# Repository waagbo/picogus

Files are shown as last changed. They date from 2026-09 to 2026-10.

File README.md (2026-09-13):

# PicoGUS

PicoGUS Logo



ISA sound card and CD-ROM drive emulation on the Raspberry Pi Pico's RP2040 microcontroller. PicoGUS can emulate:

* [Gravis Ultrasound (GUS)](https://en.wikipedia.org/wiki/Gravis_Ultrasound) - the primary focus of PicoGUS, hence the name
* [Sound Blaster 16](https://en.wikipedia.org/wiki/Sound_Blaster_16) (OPL3) / [Sound Blaster Pro 2](https://en.wikipedia.org/wiki/Sound_Blaster#Sound_Blaster_Pro_2,_CT1600) (OPL3) / [AdLib](https://en.wikipedia.org/wiki/Ad_Lib,_Inc.) (OPL2)
* [MPU-401 (with intelligent mode)](https://en.wikipedia.org/wiki/MPU-401) - outputs MIDI data on 3.5mm MIDI TRS connector
* [Tandy 3-voice](http://www.vgmpf.com/Wiki/index.php?title=Tandy_3_Voice)
* [CMS/Game Blaster](http://nerdlypleasures.blogspot.com/2012/10/all-you-ever-wanted-to-know-about.html)
* [Game port joystick](https://en.wikipedia.org/wiki/Game_port)
* [Panasonic/MKE CD-ROM](https://en.wikipedia.org/wiki/Panasonic_CD_interface)
* USB drive access from DOS: the drive plugged into the PicoGUS mapped to a DOS drive letter with `PGUSDFS.EXE` (see [pgusdfs/README.md](pgusdfs/README.md))

Current status: perpetual beta! See the [main wiki page](https://github.com/polpo/picogus/wiki) for current status and the [compatibility list](https://github.com/polpo/picogus/wiki/Compatibility-list) for support status of various DOS programs and other system compatibility notes. This project has a heavy demoscene focus due to the GUS's history so that's what I've concentrated on, but GUS support in games is very good to excellent.

Want to buy a PicoGUS? Fully assembled PicoGUS 2.0 sound cards are available from these sources, all of whom ship worldwide:

* [Joe's Computer Museum Shop](https://jcm-1.com/product/picogus-v2/) - in US 🇺🇸
* [Serdashop](https://www.serdashop.com/PicoGUS) - in EU 🇪🇺
* [Flamelily IT](https://shop.flamelily.co.uk/picogus) - in UK 🇬🇧

Want to make your own PicoGUS? See the [build guide](https://github.com/polpo/picogus/wiki/Building-your-PicoGUS). Note that the more DIY friendly v1.1.1 hardware has some documented issues with reset – a forthcoming v1.2 revision will fix these issues. **Important caveat**: due to the specs of the Pico, assumptions made by programs written to use the GUS, the imprecise nature of emulation, and the varying specs of retro DOS PC hardware, some things will likely never be perfect. **This is still a work in progress.**

Have a PicoGUS and want to use it? See the [configuring and using your PicoGUS guide](https://github.com/polpo/picogus/wiki/Configuring-and-using-your-PicoGUS).

Want to support PicoGUS? I have a limited number of machines to test PicoGUS in and donating either money or motherboards would be greatly appreciated and help increase the compatibility of PicoGUS.

You can donate via [PayPal](https://paypal.me/ianpolpo) or Ko-Fi: 

PicoGUS 2.0 PCB

PicoGUS v1.1 beta PCB

See/hear PicoGUS in action on YouTube:

Videos by others:

[](https://www.youtube.com/watch?v=08IPnmvuatw)
[](https://youtu.be/bBYUTwKRyNk)
[](https://youtu.be/oEHVB0FITqU)
[](https://youtu.be/aeejxbaAQ4g)
[](https://youtu.be/okSBZJwqVb8)

My videos:

[September 2022 update](https://youtu.be/h4iWSnTc9Ag)
[October 2022 update](https://youtu.be/CkJvkJVRscQ)
[December 2022 update](https://youtu.be/F5Zk_hHHkTg)
[January 2023 update](https://youtu.be/sOHTagrWcIE)
[March 2023 update](https://youtu.be/2LBXzy4Fus0)

## Open Source Credits

* [Raspberry Pi Pico C/C++ SDK](https://github.com/raspberrypi/pico-sdk)
* `pico_audio_i2s` from [pico-extras](https://github.com/raspberrypi/pico-extras)
* `stdio_async_uart` from [PicoCart64](https://github.com/kbeckmann/PicoCart64)
* `gus-x.cpp` adapted from [DOSBox-X](https://github.com/joncampbell123/dosbox-x)
* OPL/AdLib emulation from [rp2040-doom](https://github.com/kilograham/rp2040-doom) (based on [emu8950](https://github.com/digital-sound-antiques/emu8950))
* MPU-401 emulation adapted from [HardMPU](https://github.com/ab0tj/HardMPU) and [DOSBox-X](https://github.com/joncampbell123/dosbox-x)
* Tandy 3-voice emulation based on code contributed by [Aaron Giles](https://aarongiles.com/), adapted from [DREAMM](https://aarongiles.com/dreamm/) 
* CMS emulation based on code contributed by [Aaron Giles](https://aarongiles.com/), adapted from [DREAMM](https://aarongiles.com/dreamm/)
* USB support uses [TinyUSB](https://github.com/hathach/tinyusb) and [tusb_xinput](https://github.com/Ryzee119/tusb_xinput) with USB mass storage improvements by rppicomidi and wbcbz7.
* FAT drive support by [FatFS](https://elm-chan.org/fsw/ff/)

## License

The hardware portions of this repository (hw/ directory) are licensed under the CERN OHL version 2, permissive.

The software portions of this repository (sw/, pgusinit/ directories) as a collection are licensed under the GNU GPL version 2. Some files are individually dual-licensed under BSD or MIT licenses – see the license in the file headers for details.

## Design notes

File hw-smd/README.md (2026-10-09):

# PicoGUS SMD v1.3.0 – based on PicoGUS v1.2

Board revision **v1.3.0 (SMD)**: the PicoGUS **v1.2** SMD card with the additions made for the
through-hole board in [`hw-tht/`](../hw-tht/README.md):

* **Waveblaster (wavetable) daughterboard header** J9, with MIDI and /RESET drive
* **Analogue WT volume** (RV1) and an **NE5532 op-amp mixer** that sums the PCM audio (unity gain) and the WT
  audio (up to +6 dB, set by RV1)
* **Cleaner audio supplies:** a ferrite-bead-filtered DAC AVDD and RC-filtered ±12 V for the op-amp
* **Same layout as the THT board:** taller card, Pico rotated along the top edge, DAC turned so its
  outputs face the mixer, and one KiCad group per circuit block

> **Status: prototype design, not yet fabricated or tested.**
> The schematic passes ERC (0 errors). The board was autorouted and checked with DRC in KiCad 10
> (0 errors, 0 unconnected), but nobody has built one yet. `hw/` still holds the released v1.2.

| File | What |
|---|---|
| `PicoGUS-SMD.kicad_pro/.kicad_sch/.kicad_pcb` | KiCad **10** project (the root sheet is the v1.2 logic) |
| `audio.kicad_sch` | PCM510x DAC sheet (v1.2 circuit, AVDD now filtered) |
| `wavetable.kicad_sch` | New: Waveblaster header, WT control (U12), WT volume, op-amp mixer, line-out jack |
| `PicoGUS-SMD-schematic.pdf` | Schematic PDF |
| `BOM-SMD.csv` | BOM with a **DigiKey link** for every line, stock and NOK price (checked 2026-09-29) |
| `BOM-SMD-digikey-upload.csv` | DigiKey cart/BOM upload: quantity, DigiKey part number, MPN, and the reference designators as Customer Reference (printed on each bag) |
| `BOM-SMD-digikey-upload-10x.csv` | The same for **10 boards**: every quantity ×10, except the 1x40 header strip (11 strips: one per board for the Pico, one more for all the 1x2 jumpers). DigiKey applies its 10-piece price breaks |

## What changed compared to v1.2

The v1.2 logic is unchanged: U2 74LVC244, U3/U4 CB3T3257, U5 74AHC14, U6 74LVC00,
U7 74LVC1G00, U8 PSRAM, U9 PCM510x and U10 74LVC2G06, with the same footprints.

* **Waveblaster header J9** (2x13, 2.54 mm) along the top edge, with 5 V, ±12 V and decoupling at the
  header (C24–C27). The daughterboard's outputs go through C22/C23 to RV1.
* **U12 (74LVC2G06, new)** drives the daughterboard's /RESET (inverted ISA RESET) and MIDI (the same
  UART data as the MIDI-out jack). Its outputs are open drain with 10 k pull-ups to +3.3 V (R9/R16), so
  3.3 V daughterboards are safe. U12B takes its input from the same U5A output that drives U10B (net `~MIDI_DRV`).
* **Mixer U11 (NE5532, SOIC-8)** is an inverting summer. PCM (after the v1.2 470 Ω / 2.2 nF filter) goes
  through 20 kΩ (R10/R11) and WT (after RV1) through 10 kΩ (R12/R13) into the virtual ground, with
  20 kΩ ∥ 47 pF feedback (R19/R20, C30/C31) and a 100 Ω output resistor.
  * PCM has (almost) unity gain (20k/20.47k, −0.2 dB), so the PCM level at the jack is the same as on v1.2
    (2.1 Vrms full scale).
  * WT has a gain of 2 (+6 dB) at RV1 max. Waveblaster daughterboards put out only about 1–1.2 Vrms full
    scale (a DreamBlaster X2 uses an AKM AK4388 DAC, 1.13 Vrms), so at unity gain MIDI was 5–6 dB quieter
    than PCM. RV1 trims it down. The daughterboard sees about 4.8 kΩ at RV1 max (RV1 ∥ R12 ∥ R14).
  * **Changed 2026-10-09** (BOM only, no board change): R10, R11, R19, R20 were 10 kΩ and C30/C31 were
    100 pF (about unity gain for both sources; PCM was −0.4 dB). 47 pF with the 20 kΩ feedback puts the
    corner at ~170 kHz (10 kΩ ∥ 100 pF was ~160 kHz).
* **Audio quality:**
  * DAC AVDD (U9 pin 8) sits behind ferrite bead FB3, with C13 (0.1 µF) and C15 (10 µF) at the pin.
    DVDD and CPVDD stay on the Pico's 3.3 V.
  * Op-amp ±12 V comes through R23/R24 (10 Ω) and C32/C33 (47 µF), an RC low-pass at ~340 Hz, with
    C28/C29 (0.1 µF) at the pins.
  * C22/C23 are **bipolar** electrolytics, because the DC level across them depends on the daughterboard.
  * The signal-path capacitors (C19/C20, C30/C31) are **C0G**. The signal-path resistors (R7/R8,
    R10–R13, R19/R20) are **0.1 % thin film**, which has lower noise and distortion than thick film and
    keeps left and right matched.
* **Removed:** J2 (the ISA debug header, never fitted).
* **Pico VBUS** gets a PWR_FLAG, which clears the one ERC error that v1.2 also had.
* **1.6 mm FR4.** The v1.2 project file said 0.57 mm, which is too thin for an ISA edge connector.

### DAC option: on-board PCM5100A **or** a GY-PCM5102 module (J10)

As on the THT board, the PCM output can come from **either** the on-board DAC **or** a GY-PCM5102
module soldered almost flat over the DAC area. Fit one of the two, **never both**.

| Build | Fit | Leave out |
|---|---|---|
| On-board DAC (default, JLCPCB assembly) | U9, C12–C20, FB3, R7, R8 | J10 (the module) |
| GY-PCM5102 module | the module, soldered almost flat in J10 | **U9, C12–C20, FB3, R7, R8** (mark them DNP) |

* The parts to leave out are exactly the ones inside the module's **dashed J10 outline**, headed
  "DAC -OR- GY-PCM5102". That includes the DAC's output filter (R7/R8, C19/C20): the module has the same
  470 Ω / 2.2 nF filter, so its outputs join AUDIO_L/AUDIO_R straight into the mixer.
* Solder the module directly on its 2.54 mm male pins (6-pin I2S header + a 4-pin piece on the AGND ROUT
  AGND LROUT end of its 9-pin row), no sockets, so it stays well under a Waveblaster daughterboard. Its
  solder jumpers: **H1=L, H2=L, H3=H, H4=L**; it gets +5 V and SCK is grounded on the card.

### Back silkscreen

The back carries the PicoGUS artwork (hw-common/art/picogus-artwork.svg: three game heroes over the
PicoGUS logo), 76 × 27 mm, with the dedication centred below it: *This version is dedicated to Mila and
Alisa, my two wonderful princesses, who fill my world with joy.* Both are mirrored on B.SilkS; any pad or
hole in the way is cut out 0.3 mm around it.

## Card dimensions (ISA 8-bit)

The card is **103.7 mm long (bracket to far edge) × 99.9 mm tall** (fingers to top edge). The IBM PC/XT
full-height limit is 4.2 in (106.7 mm), so the card is 6.8 mm under it; the AT limit is 4.8 in (121.9 mm).
The edge connector (62 contacts, 0.1 in pitch), its position and the bracket holes H1/H2 are copied
from v1.2. The existing v1.2 bracket fits, plus one extra hole for RV1 (see below). The tallest
parts are the pot RV1 and the pin headers. A Waveblaster daughterboard sits about 11 mm above the
card, well inside the 0.8 in (20.3 mm) slot pitch of an AT case, as on Sound Blaster cards with a
Waveblaster header. The next card along must not have tall parts on its solder side.

## Ordering

`BOM-SMD.csv` has a DigiKey part number, a clickable digikey.no link, stock and price for every
line. Every line was in stock at DigiKey on 2026-09-29.

| DigiKey, parts only (no PCB, no shipping) | 1 board | per board, 10-board order |
|---|---|---|
| NOK excl. MVA | ~374 kr | ~286 kr |
| NOK incl. 25 % MVA | ~468 kr | ~357 kr |
| USD | ~$39 | ~$30 |

The NOK prices are DigiKey's price breaks converted by findchips.com, so digikey.no may differ by a
few percent. The biggest items are the Pico (44 kr), U3/U4 (40 kr), the PCM5100A (25 kr) and RV1 (24 kr).

Several v1.2 BOM lines are **out of stock at DigiKey today**, so they are replaced with equivalent parts:

| Part | v1.2 BOM | v1.3.0 BOM |
|---|---|---|
| 0.1 µF | Samsung CL21B104KCFNNNE | Samsung CL21B104KBCNNNC |
| 1 µF | Samsung CL21B105KBFNNNE | TDK C2012X7R1H105K125AB |
| 2.2 µF | Samsung CL21A225KBQNNNE | TDK C2012X7R1H225K125AC |
| 10 µF (C15) | Samsung CL21A106KAYNNNE, 0805 | Samsung CL31A106KAHNNNE, **1206** (no 10 µF 0805 in stock) |
| 47 µF | Samsung CL31A476MPHNNNE | TDK C3216X5R1A476M160AB |
| U2 | Nexperia 74LVC244APW,118 | TI SN74LVC244APW |
| R1/R2/R5/R6 | Bourns CR0805 (low stock) | Yageo RC0805FR |

This BOM doesn't include LCSC/JLCPCB assembly data. The `hw/jlcpcb` files are for v1.2.

## JLCPCB files

```
hw-common/tools/jlcpcb.sh hw-smd/PicoGUS-SMD.kicad_pcb        # -> hw-smd/build/jlcpcb/
```

The script stops if DRC (including the schematic-parity check) finds errors. `FORCE=1` exports anyway. It writes:

* `PicoGUS-SMD-gerbers.zip`: upload this to jlcpcb.com. It holds the Gerbers (Protel extensions, no X2)
  and the Excellon drill files (PTH and NPTH separate, mm).
* `PicoGUS-SMD-bom-jlc.csv` and `PicoGUS-SMD-cpl-jlc.csv`: the BOM and placement files for JLCPCB assembly (SMD parts only).
  The LCSC column is empty for now (this BOM is DigiKey-only), so JLCPCB matches parts by MPN or you pick them in their BOM tool.
* `PicoGUS-SMD-drc.rpt`: the DRC report.

The **Hardware (JLCPCB files)** GitHub Action runs the same script on every push that touches the
boards. The files can be downloaded as build artifacts (`jlcpcb-tht`, `jlcpcb-smd`).

Order options: 2 layers, **1.6 mm**, and **Gold fingers: Yes** with the **45° finger chamfer** (the ISA
edge connector). ENIG is a good choice for the rest of the board. Check the rotations in JLCPCB's
placement preview before paying for assembly.

## Caveats

1. **Untested.** The board is built from the proven v1.2 circuit plus the THT board's additions, but
   it hasn't been fabricated. It was autorouted with Freerouting, so check the routing before ordering.
2. **Audio now needs −12 V.** The mixer runs from ISA ±12 V, so without −12 V there is no line
   output at all (not even PCM). Every AT/ATX PC power supply provides −12 V.
3. **C22/C23 footprint.** KiCad has no non-polar SMD electrolytic footprint, so the silkscreen shows
   a "+". The parts are bipolar, so either orientation is correct.
4. **RV1.** The BOM uses the Bourns PTD902-2020K-A103 (DigiKey 426, 24 kr). It has the same 2.5 mm
   pin grid and M7 bushing as the Alps RK097 the footprint was drawn for; test-fit one in the bracket
   before a large order. The Alps RK09712200HA (45 kr) and the switched RK0971221Z0X also fit, but
   have low stock.
5. **ISA bracket.** Drill one more hole (about 7 mm, for RV1's bushing) between the MIDI and line-out
   jack holes.
6. **Silkscreen.** Reference labels were placed automatically, and some sit on their default spot
   next to a neighbour. Tidy them before ordering.

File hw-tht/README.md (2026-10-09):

# PicoGUS THT (through-hole) v1.3.0 – based on PicoGUS v1.2

Board revision **v1.3.0**: a through-hole variant of the PicoGUS **v1.2** ISA card, with an added
**Waveblaster (wavetable) daughterboard header** and an **analogue volume
control** that mixes the wavetable output with the PicoGUS audio.

> **Status: prototype design, not yet fabricated or tested.**
> The schematic passes ERC and was netlist-compared against v1.2. The board was
> autorouted and checked with DRC in KiCad 10, but nobody has built one yet.
> Read the [caveats](#caveats) before ordering boards.

Files:

| File | What |
|---|---|
| `PicoGUS-THT.kicad_pro/.kicad_sch/.kicad_pcb` | KiCad **10** project (the root sheet is the v1.2 logic) |
| `audio.kicad_sch` | PCM510x DAC sheet (same circuit as v1.2, with THT passives) |
| `wavetable.kicad_sch` | New: Waveblaster header, WT control logic, WT volume, op-amp mixer, line-out jack |
| `PicoGUS-THT-schematic.pdf` | Schematic PDF |
| `BOM-THT.csv` | BOM with DigiKey **and** LCSC part numbers, plus a digikey.no link per line (stock checked 2026-09-28) |
| `BOM-THT-digikey-upload.csv` (+ `-optional`) | DigiKey cart/BOM upload: quantity, DigiKey part number, MPN, and the reference designators as Customer Reference (printed on each bag) |
| `BOM-THT-digikey-upload-10x.csv` (+ `-optional-10x`) | The same for **10 boards**: every quantity ×10, except the 1x40 header strip (11 strips: one per board for the Pico, one more for all the 1x2 jumpers). DigiKey applies its 10-piece price breaks |

The shared `PiGUS library` symbols and footprints are linked from `hw-common/`, like the other boards.
All other footprints come from KiCad's standard libraries.

## What changed compared to v1.2

### Through-hole parts only

| Part | v1.2 | THT board |
|---|---|---|
| Resistors | 0805 | 1/4 W axial, 10.16 mm hole pitch |
| Ceramic caps | 0805 / 1206 | radial MLCC / disc, **5.0 mm** lead pitch |
| Electrolytics | 1206 / SMD | 5 mm radial electrolytics |
| D1 | B5819W SOD-123 | 1N5819 DO-41 |
| U2 | 74LVC244 TSSOP-20 | **74AHC244 DIP-20** |
| U5 | 74AHC14 SOIC-14 | **74AHC14 DIP-14** |
| U6 | 74LVC00 SOIC-14 | **74AHC00 DIP-14** |
| U7 | 74LVC1G00 SOT-23-5 | **one gate of a 74AHC00 DIP-14**, 3 spare gates tied off |
| U10 | 74LVC2G06 SOT-23-6 (open drain, 3V3) | **74AHCT126 DIP-14 at +5 V**, used as a "pseudo open-drain" |
| FB1/FB2 | 0805 beads | axial ferrite beads (bead on leads), 12.7 mm hole pitch |

Only the parts that exist in SMD packages alone stay SMD. All of them have a pitch of 0.65 mm or more and can be hand-soldered:

* **U3, U4** SN74CB3T3257: FET bus-switch mux with 5 V→3.3 V clamping. It only comes in
  TSSOP-16/TVSOP. No DIP part does this job without redesigning the ISA bus interface (and the PIO timing).
* **U8** APS6404L PSRAM: SOIC-8.
* **U9** PCM5100A/PCM5101A/PCM5102A DAC: TSSOP-20.

The 3.3 V logic needs 5 V-tolerant inputs, so it is 74**AHC** in DIP (TI still makes these and DigiKey
stocks them). **LCSC has almost none of these DIPs in stock** (0–74 pcs on 2026-09-28): order the logic
ICs from DigiKey.

### U10: 74AHCT126 instead of 74LVC2G06

The open-drain 74LVC2G06 has no DIP equivalent that takes a 3.3 V input and has a 5 V
open-drain output. HC/LS open-drain parts either need 5 V input levels or float "high"
while the Pico boots, which would hang the ISA bus through IOCHRDY. The AHCT126 runs from +5 V and
accepts the 3.3 V signals (TTL thresholds). It is wired as a pseudo open-drain driver:
input **A is tied to GND**, and the signal that drove the old inverter input now drives **OE**. OE=1 pulls the line low;
OE=0 releases it. The polarity is the same as on v1.2, so **no firmware change** is needed.

* Gate A: IOCHRDY (as v1.2). **R18** (100 k pull-down on `~RI/OCHRDY`) keeps IOCHRDY released
  while +5 V is up but the Pico's 3.3 V rail isn't yet, or while the Pico is in reset.
* Gate B: MIDI-out current loop (as v1.2).
* Gate C: Waveblaster `/RESET`. Gate D: Waveblaster MIDI (see below).
* **Only use 74AHCT126 here** (SN74AHCT126N). A 74**HCT**126 has
  input clamp diodes to VCC: with the Pico powered from USB and the PC off, the Pico's
  outputs would back-power the ISA +5 V rail through it. A 74**HC**126 at 5 V doesn't recognise 3.3 V
  highs. An **AHC**126 would work electrically, but its 5 V thresholds leave no margin.

**R17** (10 k pull-up on `UART_TX`) holds the MIDI and Waveblaster MIDI lines idle while the Pico boots
(the RP2040 pads default to pull-down, which would otherwise send a MIDI "break").

### Waveblaster header (new)

`J9` is the standard 26-pin Waveblaster header (2x13 male, 2.54 mm; the daughterboard has the
female socket). The pinout is as on PicoGUS 2.0: DGND 1,3,5,7,9,11 · AGND 15–25 odd · +5 V 6,10,14 ·
+12 V 18 · −12 V 22 · MIDI to DB 4 · audio R 20 · audio L 24 · /RESET 26 · 2,8,12,13,16 n.c.

* **MIDI** (pin 4): the MPU-401 UART (`UART_TX`, the same data as the MIDI-out jack) through U10D,
  a pseudo open-drain driver with a **10 k pull-up to +3.3 V** (R16). The line swings 0/3.3 V: that is
  a valid TTL high for 5 V daughterboards, and it is safe for modern 3.3 V daughterboards
  (Dreamblaster etc.) that are not 5 V tolerant.
* **/RESET** (pin 26): ISA RESET through U10C, also pseudo open-drain with a 10 k pull-up to +3.3 V (R9).
* **±12 V** come straight from the ISA bus. They are now connected on this board, with 0.1 µF decoupling at J9.
* The footprint includes the standard support hole at the far end of the daughterboard
  (the M3 × 11 mm standoff is in the BOM).

### Analogue WT volume + op-amp mixer (new)

```
                    v1.2 DAC filter
PCM510x OUTL --- 470R ---+--- 20k (R10) ---+-------+---- 47pF (C30) ----+
                         |                 |       +---- 20k (R19) -----+
                       2.2nF               |       |                    |
                         |                 |       +--|- \              |
                        GND                |          |NE5532 >---------+--- 100R (R21) --> LINE OUT L (J8)
WT L (J9.24) --+-- C22 ---- RV1A ---- R12 -+       +--|+ /
               |                                   |
          100k (R14)                              GND
               |
              GND                    (right channel: R11, R13, R20, C31, R22, RV1B, C23, R15)
```
C22 = 10 µF bipolar · RV1A = 10k log (CW end from C22, CCW end to GND, wiper to R12) · R12 = 10k · R14 = 100k

* The two sources are summed by a **NE5532 inverting summer** (U11, DIP-8, powered from ISA ±12 V).
  **PCM has (almost) unity gain** (R19/(R7+R10) = 20k/20.47k, −0.2 dB), so the PCM line out has the same
  level as on v1.2 (2.1 Vrms full scale). **The WT input has a gain of 2 (+6 dB) at RV1 max** (R19/R12 = 20k/10k):
  Waveblaster daughterboards put out only about 1–1.2 Vrms full scale (a DreamBlaster X2 uses an AKM AK4388
  DAC, 1.13 Vrms), so at unity gain MIDI ended up 5–6 dB quieter than PCM. RV1 trims it down. C30/C31
  (47 pF) put the feedback corner at ~170 kHz (10k ∥ 100 pF was ~160 kHz). The output is phase-inverted, which you can't hear.
* **Changed 2026-10-09** (BOM only, no board change): R10, R11, R19, R20 were 10k and C30/C31 were 100 pF
  (about unity gain for both sources; PCM was −0.4 dB). On a board built that way, swap R10/R11/R19/R20 to
  20k (and C30/C31 to 47 pF; leaving 100 pF costs only ~0.2 dB more at 20 kHz) to get the extra WT gain. Raising the feedback instead
  of lowering R12/R13 keeps the daughterboard's load as before: about 4.8 kΩ at RV1 max (RV1 ∥ R12 ∥ R14).
* **RV1** (dual-gang 10 k audio taper, right angle: Bourns PTD902-2020K-A103, or the Alps RK097 the footprint was drawn for) sets the Waveblaster
  level. Its shaft goes through the ISA bracket between the MIDI and line-out jacks. The signal is on the
  CW-end terminals (3/6) and GND is on the CCW end (1/4), so the level rises clockwise. The 10 k summing
  resistor loads the wiper only a little, because a log pot's wiper is near the GND end for most of its travel.
* C22/C23 (10 µF **bipolar** electrolytics, Panasonic SU) block any DC offset from the daughterboard.
  The DC across them depends on the daughterboard (some outputs are AC-coupled, some carry an offset), so a
  polarised cap could end up reverse-biased; a bipolar one doesn't care. R14/R15 (100 k) give the
  capacitors a defined DC level when no daughterboard is fitted. Without a daughterboard, RV1's setting doesn't matter.
* The PCM510x sees a ~20.5 kΩ load (R7 + R10; its datasheet minimum is 1 kΩ). The output is DC-coupled, which is fine because the
  DAC's outputs are ground-centred; expect a few mV of offset at the jack.
* R21/R22 (100 Ω) isolate the op-amp from cable capacitance. The NE5532 drives 600 Ω headphones
  easily, but this is still a line output.
* **Op-amp supply filter.** The ISA ±12 V rails carry PSU ripple and noise from other cards. They reach U11
  through R23/R24 (10 Ω) and C32/C33 (47 µF), an RC low-pass at about 340 Hz, with C28/C29 (0.1 µF) at the
  op-amp pins. The NE5532's supply rejection falls at high frequencies, which is where this filter works.
  The daughterboard still gets the plain ±12 V (decoupled at J9); it has its own regulators and filtering.
* **DAC analogue supply.** On v1.2 the PCM510x AVDD (pin 8) shares the Pico's switch-mode 3.3 V with all
  the logic. Here AVDD has its own rail behind ferrite bead FB3 (the same part as FB1/FB2), with C13
  (0.1 µF) and C15 (10 µF) at the pin. DVDD/CPVDD stay on the plain 3.3 V. The bead drops only millivolts
  at the DAC's ~10 mA.
* **Capacitor types in the signal path:** C19/C20 (DAC output filter) and C30/C31 (op-amp feedback) are
  **C0G/NP0**, which has no voltage or temperature coefficient and so adds no distortion. X7R is used only for
  supply decoupling.

### DAC option: on-board PCM5100A **or** a GY-PCM5102 module (J10)

The PCM output can come from **either** the on-board DAC **or** a plug-in GY-PCM5102 module. Fit one of
the two, **never both** (two DAC outputs would drive the same line).

| Build | Fit | Leave out |
|---|---|---|
| On-board DAC (default) | U9, C12–C20, FB3, R7, R8 | J10 (the module) |
| GY-PCM5102 module | the module, soldered almost flat in J10 | **U9, C12–C20, FB3, R7, R8** |

* The module lies **over the DAC area**: the parts to leave out for it are exactly the ones inside the
  module's **dashed J10 outline** on the silkscreen, headed "DAC -OR- GY-PCM5102". That includes the
  DAC's output filter (R7/R8 470 Ω, C19/C20 2.2 nF): the module has the same 470 Ω / 2.2 nF filter on
  board, so its outputs join the audio path after it (AUDIO_L/AUDIO_R, straight into the mixer).
* Solder the module **almost flat, directly on its 2.54 mm male pins** (no sockets): its 6-pin I2S header
  (SCK BCK DIN LCK GND VIN) and a 4-pin piece of the 1x40 strip on the **AGND ROUT AGND LROUT end** of
  its 9-pin row, both pointing down. It then sits a few mm above the card, well under a Waveblaster
  daughterboard (~11 mm); on 8.5 mm sockets it would hit one.
* Set the module's solder jumpers **H1=L, H2=L, H3=H, H4=L**. It gets +5 V (it has its own 3.3 V
  regulator); SCK is grounded on the card. Its own 3.5 mm jack is not used: the audio goes through the
  mixer to J8.
* Either way the mixer, the Waveblaster mix and the firmware are the same. With the module the board is
  fully through-hole apart from U3/U4 and the SOIC-8 PSRAM.
* The module is not sold by DigiKey (AliExpress, eBay and the like).

### Back silkscreen

The back carries the PicoGUS artwork (hw-common/art/picogus-artwork.svg: three game heroes over the
PicoGUS logo), 76 × 27 mm, just above the ISA fingers, with the dedication higher up on the back, above the DAC area: *This version is
dedicated to Mila and Alisa, my two wonderful princesses, who fill my world with joy.* Both are mirrored
on B.SilkS so they read correctly from the back. The back is full of through-hole pads, so the artwork is
cut out 0.3 mm around every pad and hole (silkscreen never lands on copper).

### Other changes

* The board is **103.7 × 99.9 mm**. It has the same length, ISA edge connector and bracket holes as v1.2
  (the MIDI and line-out jacks are in the same places), but it is taller, like PicoGUS 2.0, to fit the
  Waveblaster header along the top edge. 1.6 mm FR4 (the v1.2 project file said 0.57 mm).
* Design rules are relaxed for THT/DIY: 0.2 mm clearance, 0.25 mm signal / 0.4 mm power tracks
  (+5 V, +3.3 V, VSYS), 0.7/0.35 mm vias. GND is routed and poured on both layers, with stitching vias.
* **J2 (the 2x31 ISA debug/probe header of v1.2, never fitted) is removed.** On a through-hole board
  its pads formed a wall right above the gold fingers that every ISA signal had to cross.
* The `+3.3V` power symbols are renamed `+3V3`. KiCad 8+ names power nets after the symbol value, so the
  upgraded v1.2 sheets would otherwise have split the 3.3 V rail into two nets.
* The symbol fields of U3/U4 now name the CB3T3257 that is actually used (the v1.2 fields still said 74FST3257DR2G).
* **Layout is grouped by circuit block.** Each chip and its decoupling caps and resistors form a KiCad group,
  so a block can be selected and moved as one: DAC (U9), Mixer + line out (U11, J8), WT volume (RV1),
  Waveblaster header (J9), MIDI out (J5), Pico + power (U1), ISA bus switches (U3, U4), ISA buffer (U2),
  74AHC14 (U5), 74AHC00 (U6, U7), 74AHCT126 (U10), PSRAM (U8), IRQ/DMA jumpers (J1).
* **Layout for audio quality:** every decoupling cap sits next to its chip's supply pin, with a short
  return to GND. FB3 sits next to C13/C15. The ±12 V filter (R23/R24, C32/C33) sits above U11. The PCM5102 is rotated so that its outputs, output RC filter (R7/R8, C19/C20) and the
  mixer op-amp form one short, straight path to the line-out jack, away from the Pico and the ISA logic.

## Card dimensions (ISA 8-bit)

The card is **103.7 mm long × 99.9 mm tall** (bottom of the fingers to the top edge). The IBM PC/XT
full-height limit is 4.2 in (106.7 mm), so the card is 6.8 mm under it; the AT limit is 4.8 in (121.9 mm).
The edge connector (62 contacts, 0.1 in pitch), its position and the bracket holes are unchanged from
v1.2, and the board is 1.6 mm, the standard ISA card thickness. A Waveblaster daughterboard sits about
11 mm above the card, inside the 0.8 in (20.3 mm) AT slot pitch. Clip the THT leads short
(≤ 2 mm) on the solder side, where the next card sits.

The **SMD** version of this board is in [`hw-smd/`](../hw-smd/README.md).

## Ordering

`BOM-THT.csv` lists, for every line, the DigiKey part (with DigiKey stock) and the LCSC part
(with LCSC stock) as of 2026-09-28, plus alternatives. DigiKey numbers were checked
against findchips distributor data, and LCSC numbers against the LCSC product API.

* **Logic ICs (U2, U5, U6, U7, U10): order from DigiKey.** LCSC lists the DIPs, but has 0–74 in stock.
  Everything else is available from both.
* **DigiKey BOM cost** (2026-09-28, parts only, no PCB, no shipping), from DigiKey's price breaks:

  | | 1 board | per board, 10-board order |
  |---|---|---|
  | NOK excl. MVA (digikey.no) | ~474 kr | ~356 kr |
  | NOK incl. 25 % MVA | ~592 kr | ~444 kr |
  | USD | ~$50 | ~$37 |

  The optional sockets and Pico headers add ~39 kr (~$4). NOK figures are DigiKey's USD prices converted
  at 9.53 NOK/USD, so digikey.no can differ by a few percent. The Pico (44 kr), U3/U4 (40 kr)
  and the 18 × 0.1 µF (59 kr) are the big items.
* **Ceramic capacitors must have 5.0 mm (or 5.08 mm) lead pitch.** 2.5 mm parts don't fit (e.g. TDK FG1x, Vishay K…L2).

Mistakes found in the v1.2 BOM/JLCPCB data (don't copy these from the v1.2 files):
C139966 is a Vilsion part, not the APS6404L. C2910528 is a 3.5 mm jack with a different pinout.
C2905423 is a female header, not the Pico. C2935925 is DEALON, not Amphenol. C6942 is the SOIC SN74AHC14DR.

## JLCPCB files

```
hw-common/tools/jlcpcb.sh hw-tht/PicoGUS-THT.kicad_pcb        # -> hw-tht/build/jlcpcb/
```

The script stops if DRC (including the schematic-parity check) finds errors. `FORCE=1` exports anyway. It writes:

* `PicoGUS-THT-gerbers.zip`: upload this to jlcpcb.com. It holds the Gerbers (Protel extensions, no X2)
  and the Excellon drill files (PTH and NPTH separate, mm).
* `PicoGUS-THT-bom-jlc.csv` and `PicoGUS-THT-cpl-jlc.csv`: the BOM and placement files for JLCPCB assembly (SMD parts only).
  Only U3/U4 (and U8/U9) are SMD on this board; the LCSC column comes from the schematic fields.
* `PicoGUS-THT-drc.rpt`: the DRC report.

The **Hardware (JLCPCB files)** GitHub Action runs the same script on every push that touches the
boards. The files can be downloaded as build artifacts (`jlcpcb-tht`, `jlcpcb-smd`).

Order options: 2 layers, **1.6 mm**, and **Gold fingers: Yes** with the **45° finger chamfer** (the ISA
edge connector). ENIG is a good choice for the rest of the board. Check the rotations in JLCPCB's
placement preview before paying for assembly.

## Caveats

1. **Untested.** This board is built from the proven v1.2 circuit, but it hasn't been fabricated or
   run in a PC. It was autorouted with Freerouting, so check the routing before ordering.
2. **Audio now needs −12 V.** The mixer op-amp runs from ISA ±12 V, so without −12 V there is
   **no line output at all** (not even PCM). Every AT/ATX PC power supply provides −12 V. Some unusual
   backplanes or small DC-DC "pico" supplies may not, so check yours.
3. **Slower logic in the ISA path.** 74AHC00 (U6/U7) is a few ns slower than the v1.2 74LVC00,
   and IOCHRDY now goes through an AHCT126 instead of an LVC2G06. At ISA speeds this should be
   harmless, but it hasn't been tested on fast (10–12 MHz) buses.
4. **AHC input thresholds.** At 3.3 V, 74AHC needs ~2.3 V for a logic high (74LVC: 2.0 V). The ISA
   signals that reach U5/U7 directly (AEN, RESET, DACK) are fine from any normal chipset or
   74LS/F/ACT driver (VOH ≈ 3.4 V or more). A marginal old bus that only gives the TTL minimum of 2.4 V
   has little margin.
5. **Daughterboard clearance.** The Waveblaster daughterboard sits ~11 mm above the card, and a
   full-size (Creative-spec) board covers most of the card's left half. Only low parts are placed
   under it (DIP ICs, axial resistors, radial MLCCs, the J1 jumper block as on PicoGUS 2.0). Electrolytics,
   the pot and the Pico are outside that area. IC sockets add ~4 mm and may touch a daughterboard
   that has parts on its underside, so solder the DIPs directly or check the clearance.
6. **RV1.** The BOM uses the Bourns PTD902-2020K-A103 (DigiKey 426, 24 kr). It has the same 2.5 mm
   pin grid and M7 bushing as the Alps RK097 the footprint was drawn for; test-fit one in the bracket
   before a large order. LCSC doesn't list it, so the LCSC column keeps the Alps RK09712200HA
   (C470545). The Alps parts (RK09712200HA: DigiKey 210 / LCSC 175, 45 kr; the switched RK0971221Z0X
   also fits) have low stock, and Alps North America has published a discontinuation notice that
   covers parts of the range.
7. **ISA bracket.** Drill one more hole (about 7 mm, for RV1's bushing) between the MIDI and
   line-out jack holes. Those two holes are where they are on v1.2.
8. **Mixed LCSC stand-ins.** LCSC's 3.5 mm jacks are XKB PJ-325C5 equivalents. Their unused
   TN pin sits ~0.4 mm further out, so clip it if it doesn't fit. Don't use C2910528
   (different pinout; it is in the v1.2 JLCPCB project). The Pico is not sold in the LCSC shop
   (only in the JLCPCB assembly library). DigiKey doesn't stock the APS6404L PSRAM; Adafruit 4677 (the bare chip) is the DigiKey source.
9. **Ferrite beads.** FB1/FB2 are axial beads on leads (DigiKey Fair-Rite 2743002112, LCSC FH
   RH3.5x0.8x9P52E). A wire link also works (MIDI out works without the beads, with slightly worse EMI).
10. The v1.2 symbols are cached in the schematic, so KiCad reports "symbol doesn't match library"
    warnings. That is expected; don't "update symbols from library" blindly.
11. Waveblaster pin 8 (MIDI out from the daughterboard) and the daughterboard audio inputs (pins 12/16)
    are not used. PicoGUS has no MIDI in.

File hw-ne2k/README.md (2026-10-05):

# PicoGUS NE2000 v1.0 – WiFi network card based on PicoGUS v1.2

A third card in this repository: the PicoGUS **v1.2** ISA interface with **everything audio removed**,
built around a **Raspberry Pi Pico W** so it runs the PicoGUS NE2000 firmware (`pg-ne2k`: an NE2000
that talks to the network over WiFi). Added:

* **USB-A host port** at the bracket, wired to the Pico W's USB test points (TP2/TP3), for USB mice,
  joysticks and storage (the same idea as the PicoGUS 2.0 USB-A port)
* **8 MB PSRAM** (APS6404L) kept, for buffering/caching in future firmware
* **Boot ROM** on the ISA memory bus: an in-system-writable SST39SF010A flash with 4 × 32 KB images
  (e.g. iPXE for PXE boot, a disk-image boot ROM, XT-IDE BIOS), configured from the Pico W

> **Status: prototype design, not yet fabricated or tested.** The schematic passes ERC (no errors
> beyond those inherited from v1.2). The board was autorouted and checked with DRC in KiCad 10:
> **0 errors, 0 unconnected**, and it matches the schematic. Firmware support for the boot ROM
> (enable/base/bank set-up, ROM images, flashing tool) does not exist yet; the stock `pg-ne2k` firmware
> runs the NE2000 and leaves the ROM switched off.

| File | What |
|---|---|
| `PicoGUS-NE2K.kicad_pro/.kicad_sch/.kicad_pcb` | KiCad **10** project. Root sheet: the v1.2 ISA logic + Pico W + PSRAM |
| `bootrom.kicad_sch` | Boot ROM (U13–U16) and USB-A host port (J5, U17, F1) |
| `PicoGUS-NE2K-schematic.pdf` | Schematic PDF |
| `BOM-NE2K.csv` | BOM with a **DigiKey link** for every line, stock and NOK price |
| `BOM-NE2K-digikey-upload.csv` / `-10x.csv` | DigiKey cart/BOM upload for 1 / 10 boards (designators as Customer Reference) |
| `build/jlcpcb/` | Gerbers, drill, assembly BOM and placement files for JLCPCB (regenerate with `hw-common/tools/jlcpcb.sh`) |

## What is on the card

### Kept from v1.2 (unchanged)

U2 74LVC244, U3/U4 SN74CB3T3257, U5 74AHC14, U6 74LVC00, U7 74LVC1G00, U8 APS6404L PSRAM and
U10A 74LVC2G06 (IOCHRDY), with the same Pico GPIO assignment as v1.2. So the stock PicoGUS firmware
builds (`pg-ne2k`, the USB mouse/joystick build, `multifw`) work without changes; the sound modes of
`multifw` simply have no DAC to play through.

### Removed

* **Audio:** PCM510x DAC, the GY-PCM5102 option, line-out and the Waveblaster/mixer section of v1.3
* **MIDI out** (J5 jack, R3/R4, FB1/FB2). U10B stays on the board (its input is still driven) with the
  output unconnected.
* **ISA DMA:** the DRQ/DACK jumpers and the DRQ/DACK/TC paths. The NE2000 moves packet data with
  programmed I/O through its data port (its "remote DMA" is internal to the NE2000, not ISA DMA), so
  `pg-ne2k` never uses DRQ or DACK. DACK keeps its pull-up (R6), so the AEN gating (U7) works as before.
* **J7 (USB power jumper):** the USB-A port has its own VBUS supply.

### IRQ (J1)

J1 is now a **2×5 header**: one jumper selects **IRQ 2/9, 3, 4, 5 or 7** for the NE2000 (same layout as
the IRQ half of the v1.2 J1). IRQ 3 is the usual NE2000 choice if COM2 is not used.

### Pico W, antenna and USB-A

* **U1 must be a Pico W** (SC0918). The NE2000 firmware is built for the RP2040 + CYW43439; a
  Pico 2 W does not work.
* **Solder the Pico W flat** (castellated edges, or pins cut flush), not on header pins: the USB data
  lines are taken from its **TP2 (D−) and TP3 (D+)** test points on the underside. The footprint
  (`RPi_PicoW_SMD_TH_USB`) has plated 1.5 mm pads with a 0.6 mm hole there, so you solder them from the
  back of the card after the module is in place. TP1 (USB ground) is connected the same way. A Pico WH
  (pre-soldered headers) cannot be used.
* **The antenna end points at the bracket**, as far out as the board allows. No copper on either layer
  under the antenna (datasheet keep-out, 14 × 9 mm between the pin rows) or between the module end and
  the bracket edge. The footprint also drops the Pico's SWD pads, which would sit under the Pico W
  antenna.
* **USB-A (J5, Molex 67643)** sits at the bracket below the antenna, on the line of the v1.2 line-out jack.
  D+/D− run straight from the Pico's test points (the Pico's own 27 Ω series resistors are before them),
  with a USBLC6-2SC6 ESD protector (U17). VBUS comes from the ISA +5 V through a 0.5 A polyfuse (F1)
  with 10 µF + 0.1 µF. The Pico's own VBUS pin is not connected, so a PC on the micro-USB port (on the
  bench, for flashing) and the ISA supply never feed each other.
* **Firmware updates** go over ISA with `pgusinit` as usual. The micro-USB socket now faces into the card;
  it is still usable with the card out of the PC (BOOTSEL on the Pico).

### Boot ROM (bootrom.kicad_sch)

A real option ROM on the ISA memory bus, so the BIOS finds and runs it during POST.

* **U13 SST39SF010A** (128 KB, 5 V, PLCC-32), read through a **32 KB window**: SA0–SA14 go straight to the
  flash. Flash A15/A16 are the **bank** bits from the Pico, so the chip holds **4 images of 32 KB**.
* **U14 74HCT688** compares SA19..SA15 with `1 1 BASE2 BASE1 BASE0` and requires **ROM_EN = 1**. Its
  enable is `~MEMSTB` (U16: low during any ISA memory read or write), so the output `~ROM_CS` is only
  active in a memory cycle inside the window.
* **U15 74AHCT245** drives the flash data onto the ISA data bus (the flash alone is too weak for a loaded
  bus). Direction comes from `~SMEMW`, enable from `~ROM_CS`.
* **Base address** (BASE2..0): `001` C8000, `010` D0000, `011` D8000, `100` E0000, `101` E8000.
* **ROM_EN, BASE0–2, BANK0–1 are Pico GPIOs** (the pins freed by removing I2S and DMA):

  | GPIO | Pico pin | Signal |
  |---|---|---|
  | 16 | 21 | ROM_EN (pulled low by R3: ROM off until the firmware enables it) |
  | 17 | 22 | ROM_BASE0 |
  | 18 | 24 | ROM_BASE1 |
  | 19 | 25 | ROM_BASE2 |
  | 20 | 26 | ROM_BANK0 |
  | 22 | 29 | ROM_BANK1 |

  The firmware should set them from its stored settings first thing after reset. The Pico is running
  within tens of milliseconds of ISA RESET, while the BIOS scans for option ROMs only after its memory
  test. With the stock firmware the ROM stays invisible.
* **Writing the ROM from DOS:** fit **J2** (write enable: `~SMEMW` → flash WE#, R4 holds WE# high
  otherwise), then use the SST software command sequence (5555h/2AAAh lie inside the 32 KB window).
  Remove J2 afterwards.
* **What to put in the banks:** iPXE built with its `ne2k_isa` driver (PXE boot; iPXE needs a 386 or
  later), a small INT 13h ROM that boots a disk image the Pico fetches over WiFi (cached in the PSRAM; works
  on an 8088), or an XT-IDE BIOS. All of this is firmware work; the hardware only provides the ROM.

## Card dimensions and bracket

The card uses the **v1.2 outline: 103.7 × 74.2 mm** (bracket edge to far edge × fingers to top), with the
v1.2 edge connector and bracket holes H1/H2, so a v1.2 bracket screws on. The bracket needs:

* a **large opening in front of the antenna** (around the old MIDI-jack hole, y ≈ 80 mm on the board):
  metal close to the antenna is what costs range,
* a **USB-A cut-out** (about 14 × 7 mm) centred on the old line-out jack hole.

### Silkscreen

Front: IRQ numbers at J1, `ROM WE` at J2, `TX GND` at J6, `USB`, `WiFi ANTENNA` at the antenna end,
`REAR >`. Back: the PicoGUS artwork (`hw-common/art/picogus-artwork.svg`, 70 × 25 mm) over the lower half,
the dedication *This version is dedicated to Mila and Alisa, my two wonderful princesses, who fill my
world with joy.* behind the Pico, and the copyright/licence text (CERN-OHL-P v2).

## Building it

* Everything except U1, J1, J2, J5, J6 and the jumpers is SMD on the top side. `hw-common/tools/jlcpcb.sh
  hw-ne2k/PicoGUS-NE2K.kicad_pcb` writes gerbers, drill, assembly BOM and placement files to `build/jlcpcb/`
  (38 SMD placements). The parts have no LCSC numbers yet, so pick them in JLCPCB's part matcher (or order
  the parts from DigiKey and assemble by hand).
* Solder the **Pico W flat**, then solder **TP1, TP2, TP3 from the back** through the plated holes.
* Jumpers: one on J1 (IRQ). J2 only while writing the boot ROM.
* Firmware: flash `pg-ne2k` (or `multifw`) with `pgusinit`, then set the WiFi SSID/password and the NE2000
  base port with `pgusinit` as on any PicoGUS.

## Ordering

`BOM-NE2K.csv` lists a DigiKey part for every line with stock and price (new parts checked on
digikey.com on 2026-10-05; parts shared with the SMD board from its 2026-09-29 check).
DigiKey parts only (no PCB, no shipping): **about 264 kr excl. MVA (~330 kr incl. 25 % MVA, ~$28) per
board**; the Pico W (73 kr), the PLCC flash (19 kr), the USB-A connector (18 kr) and the two bus switches
(20 kr) are the largest items.

## Sources

* PicoGUS v1.2 schematic (`hw/`) and the v1.3.0 SMD root sheet (`hw-smd/`)
* Raspberry Pi Pico W datasheet (test points TP1–TP6, SMT footprint, antenna keep-out)
* Microchip SST39SF010A datasheet; TI CD74HCT688, SN74AHCT245, SN74AHCT1G08 datasheets
* PicoGUS firmware: `sw/ne2000play.cpp`, `sw/ne2000/ne2000.c`, `sw/CMakeLists.txt` (`NE2K` target)

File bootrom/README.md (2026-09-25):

# PGBOOT: boot floppy and hard disk images from the PicoGUS USB drive

**Experimental.** PGBOOT is an 8 KB x86 option ROM. It presents disk image
files on the USB drive plugged into a PicoGUS to the BIOS as a floppy drive
(A:, BIOS drive 00h) and/or a hard disk (C:, BIOS drive 80h), and it can boot
from them. The PicoGUS only decodes I/O ports and cannot carry a ROM itself,
so the ROM goes into an EEPROM on a separate ROM card, or it is loaded into
RAM by `PGBOOT.COM`.

The card side (`sw/bootdisk/`) serves 512-byte sectors of the image files
over the PGDFS transport. The wire protocol is described in
`sw/bootdisk/PROTOCOL.md` and `sw/dfs/PROTOCOL.md`.

| File | What it is |
|---|---|
| `PGBOOT.ROM` | The option ROM (8192 bytes: `55 AA 10`, init entry at offset 3, checksum byte at the end). |
| `PGBOOT88.ROM` | The same code, but it always uses the 8088 transfer loops. This is for testing; on an XT the normal ROM picks those loops by itself. |
| `PGBOOT.COM` | Loader for machines without a ROM board (experimental). |
| `PGFLASH.COM` | Writes the ROM into a 28C64/28C256 EEPROM in the machine (experimental). |
| `test/INT13TST.COM` | INT 13h exerciser used by the tests. It is not needed to boot. |

## Building

You need `nasm` (2.15 or later) and `python3`.

```
make            # PGBOOT.ROM PGBOOT88.ROM PGBOOT.COM PGFLASH.COM test/INT13TST.COM
make check      # size/header/checksum of both ROMs, and no 186+ opcode outside
                # the two 186+ transfer routines (cpucheck.py on the listing)
```

All sources assemble with `cpu 8086` and with every NASM warning treated as
an error. Only two routines are exceptions: `out186` (`rep outsw`) and
`in186` (`rep insw`). They are assembled with `cpu 186` and only run after the
CPU check has found an 80186 or later. `mkrom.py` pads the image, sets the
checksum byte and verifies it. The header word at 14h holds the number of
bytes in use: about 4.3 KB of the 8 KB.

## Setting up the card

Copy the image files to the USB drive and configure the card with pgusinit:

```
pgusinit /fdimage DOS622.IMG     floppy image -> A: (raw 160K..2.88M, DMF, or any size with a FAT BPB)
pgusinit /hdimage HD\DOS.VHD     hard disk image -> C: (raw with MBR, fixed VHD, superfloppy)
pgusinit /bdopts n               bit 0 floppy read-only, bit 1 hard disk read-only,
                                 bit 2 ROM disabled, bit 3 boot the hard disk even with a floppy image
pgusinit /save                   make it permanent
pgusinit /fdimage -              remove the floppy image (same for /hdimage)
```

You can change the floppy image while the system is running: the ROM
reports a media change (INT 13h AH=16h) to DOS. A new hard disk image takes
effect at the next boot.

## Installing the ROM

### On a ROM card (DoubleROM-style, XT-IDE boards with a free socket, ...)

1. Choose a free 8 KB window, for example C800h, D000h, D800h or E000h. It
   must not overlap the VGA BIOS (C000h-C7FFh), a network boot ROM or an
   XTIDE ROM. **Order matters with other disk ROMs.** The BIOS scans option
   ROMs from low to high segments, so each ROM that hooks INT 19h wraps the
   ones scanned before it, and the last one scanned runs first at boot.
   * Some ROMs replace INT 19h without chaining to the old handler: XT
     fixed-disk controller ROMs (the IBM/WD/Xebec family) and the XTIDE
     Universal BIOS in its default mode, which runs its own boot menu.
     PGBOOT must be scanned **after** such a ROM, so give it a higher
     segment. Scanned first, PGBOOT's INT 19h never runs.
   * The XTIDE Universal BIOS configured for late initialisation hooks
     INT 19h and INT 13h at boot time itself. Then both ROMs rearrange the
     drive numbers when their INT 19h runs, and the one that runs second
     sees the other's drives as physical. Use XUB in normal (POST-time)
     mode with PGBOOT above it, or expect the image at 80h to shift.
   * BIOSes with a BIOS Boot Specification boot manager (most 1996+ AT
     BIOSes, "boot device priority" menus) may restore their own INT 19h
     before booting, or boot through their own list without calling
     INT 19h. PGBOOT then never runs its late init. Such machines need a
     BIOS that keeps legacy option ROM INT 19h hooks, or `PGBOOT.COM`.
2. Program the EEPROM. You have three ways to do it:
   * `PGFLASH D000 PGBOOT.ROM` in the target machine. Boot clean first (no
     EMM386 or QEMM) and set the board's write-enable jumper. `/256` sends
     the 28C256 SDP command addresses, but only when the board decodes the
     chip's full 32 KB. `/NOSDP` writes without the unlock sequence. `/BYTE`
     is for chips without page mode. PGFLASH only reads until you confirm.
     It shows what the segment holds now and warns about other option ROMs
     in the same 32 KB window, which a 28C256 or a board decoding 32 KB may
     share. After you confirm, it checks that the segment is not RAM and
     writes. Interrupts stay off from each SDP unlock until the write cycle
     ends. It refuses to overwrite a PGBOOT that is running from that
     segment.
   * XTIDECFG (from the XTIDE Universal BIOS): load `PGBOOT.ROM` as a
     "BIOS image" and flash it to the segment. Skip its "configure" step,
     because that is XTIDE-specific.
   * An external programmer such as the TL866 or T48: write `PGBOOT.ROM` to
     the chip at address 0. On a 28C256 in a board that maps an 8 KB window,
     write it at the offset the board's address jumpers select.
3. Tell memory managers to keep out of the window, for example
   `DEVICE=EMM386.EXE X=D000-D1FF`. The same goes for QEMM, 386MAX and the
   UMB drivers.
4. If the BIOS shadows option ROMs, it may shadow this window too. Shadowing
   is harmless for PGBOOT, which never writes to its own segment. Only
   PGFLASH needs shadowing off for that window.

### Without a ROM card: PGBOOT.COM (experimental)

```
PGBOOT [path\PGBOOT.ROM] [/Y] [/C]
```

`PGBOOT.COM` reads the image (default: `PGBOOT.ROM` in the current directory)
and checks its size, header, signature and checksum. It copies the image to
the top of conventional memory: 40:13h is lowered by 8 KB, so the copy is KB
aligned. It tells the copy where the original BIOS INT 13h handler is, calls
the copy's init entry just as the BIOS would at POST, and then issues
INT 19h. If the ROM does not install (no card, disabled, ...), the loader
puts back the memory and vectors it touched and returns to DOS.

**Run it from a clean boot.** INT 19h does not undo what DOS and TSRs have
hooked. The booted system overwrites DOS in memory while a timer, keyboard
or disk IRQ vector may still point into it. The loader lists such vectors
(08h, 09h, 0Eh, 15h, 1Ch, 70h, 74h, 76h in conventional memory or the HMA)
and asks before it goes on. The fix is a minimal CONFIG.SYS: `STACKS=0,0`
(FreeDOS and MS-DOS hook the IRQ vectors for their stack switcher
otherwise), no TSRs, no HIMEM, no EMM386. The loader refuses to run in
virtual 8086 mode. `/Y` skips the question.

`/C` (catch mode, MS-DOS 3.2 or later only; untested) keeps DOS's own INT 19h
in charge, so that DOS restores the vectors it hooked. The loader points
INT 13h at a boot catcher in the ROM copy, directly and through INT 2Fh
AH=13h. The BIOS's first INT 13h call after DOS's INT 19h then runs the late
init. FreeDOS has no INT 2Fh AH=13h and restores INT 13h on its own, so `/C`
is refused there.

#### Loader <-> ROM convention (header fields)

| Offset | Size | Field |
|---|---|---|
| 06h | 4 | `PGBT` signature |
| 0Ah | 1 | loader interface version, 1 |
| 0Bh | 1 | flags. Bit 0: this image is a writable RAM copy, set by the loader. Bit 1: catch mode active, set by the catcher. |
| 0Ch | 4 | far pointer: the INT 13h handler the ROM chains to. 0:0 means "the vector at INT 19h time". The loader stores the BIOS handler from INT 2Fh AH=13h (ES:BX, else DS:DX, else the current vector). |
| 10h | 4 | previous INT 19h. Written by the init entry only when bit 0 is set. |
| 14h | 2 | bytes used, for information only |
| 16h | 1 | `IRET`. The loader points INT 1Bh (Ctrl-Break) at it. |
| 1Ch | 2 | offset of the boot catcher (`/C`) |

The loader fixes the checksum byte after it patches these fields.

## What happens at boot

1. **POST** (the BIOS far-calls offset 3). The ROM looks for the card with
   these checks: knock CCh on 1D0h; `CMD_MAGIC` = DDh; `CMD_PROTOCOL` >= 5;
   `CMD_DFSMAXLEN` in 512..32768; `CMD_DFSPORT` != 0; `CMD_BDOPTS` with
   bit 7 set, bit 6 clear and bit 2 (ROM disabled) clear. The ROM prints one
   line. If the card is there, it hooks INT 19h and nothing else. If
   nothing answers at all, it still hooks INT 19h: a fast AT POST can reach
   the option ROMs while the card is still booting. The late init then
   gives the card another 2 s and continues with the BIOS boot if it is
   still absent. If the card answers but reports old firmware, PGDFS off
   or the ROM disabled, nothing is hooked. A ROM
   cannot write to itself: an unprotected EEPROM would take the write. So
   the ROM keeps the previous INT 19h in interrupt vector **6Bh** (free
   between POST and boot) until the late init copies it to RAM. A loaded
   copy keeps it in its header instead.
2. **INT 19h (late init).** The ROM checks the card again and takes 1 KB at
   the top of conventional memory (40:13h - 1) for all its state. It then
   runs on its own stack at the top of that block. If no image name is
   configured, it continues with the BIOS boot at once. Otherwise it waits
   up to 15 s for the USB drive (`CMD_DFSSTAT` = FFh, or BDINFO state 4,
   means "not mounted yet"). A countdown is shown and Esc skips the wait
   (other keys, such as F5/F8 for DOS, stay in the keyboard buffer). The
   ROM then sends BDINFO with OPEN for unit 0 (floppy) and unit 1 (hard
   disk), prints a line per configured unit, adjusts the BIOS data area,
   hooks INT 13h and reads sector 0 of the boot image to 0000:7C00. It boots
   the floppy image first, or the hard disk image when option bit 3 is set or
   there is no floppy image. A hard disk needs 55AAh at the end of the
   sector. A floppy boot sector without the signature is accepted when it
   starts with a jump (EBh/E9h). The ROM then jumps to 0000:7C00 with
   DL = drive, DH = 0, SS:SP = 0000:7C00 and the other registers 0. If the
   first image does not boot, it tries the other one. If neither boots, it
   continues with the BIOS boot, and the images stay installed as A:/C:.
   When no image is ready, the ROM gives the memory back, unhooks INT 19h
   and continues with the BIOS boot.
3. **Running system.** The INT 13h handler serves drives 00h and 80h from the
   card. It passes other drives through to the previous handler, translating
   them as described in the next section.

### Drive mapping

| BIOS drive | Floppy image configured | Hard disk image configured |
|---|---|---|
| 00h | the floppy image (the physical A: is hidden) | physical A: |
| 01h | physical B: | physical B: |
| 80h | physical first disk | the hard disk image |
| 81h..80h+n | physical | physical disk 80h..80h+n-1 (DL-1 to the old handler, DL restored) |

When a floppy image is present, the equipment word (40:10h) is set to report
at least one floppy drive. A hard disk image adds one to 40:75h. INT 13h
AH=08h for 80h or a translated drive returns DL = the number of physical
hard disks the ROM saw at install + 1, taken from its own state rather than
from 40:75h after chaining. AH=15h returns CX:DX unchanged from the old
handler.

### INT 13h functions served

Floppy image (00h): 00 reset (also re-reads the image info), 01 status,
02/03/04 read/write/verify, 05 format (fills the track with F6h, 03h if
read-only), 08 parameters (BL type from the card, ES:DI -> a DPT in RAM with
the image's sectors per track), 15 (AH=02h, change line), 16 (06h + CF once
after the image changed), 17, 18 (0Ch if the requested geometry does not
match the image).

Hard disk image (80h): 00, 01, 02, 03, 04, 08, 09, 0C, 0D, 10, 11, 14,
15 (AH=03h, CX:DX = total sectors), 41h (EDD 1.1, CX=1: 42h-44h, 47h, 48h),
42h/43h/44h (disk address packet, LBA < 2^32, count written back),
47h (bounds check), 48h (1Ah or 1Eh bytes, CHS valid, no DPTE).

Any other function returns AH=01h with CF set. The last status goes to 40:41h
(floppy) or 40:74h (hard disk). CHS addresses outside the geometry, and LBAs
at or past the end of the image, return 04h. Transfers stop at the end of the
image, and AL (or the packet count) holds the number of sectors done. The
buffer (ES:BX or the packet's pointer) is tracked as a linear address. Each
frame gets the segment address/16, but at most FFFFh, so no DMA-boundary
errors are raised. A buffer in the HMA (FFFF:xxxx with A20 on) is served
without wrapping to low memory. A frame that would run past FFFF:FFFF is cut
there, and if not even one sector fits, the ROM returns 09h. Transfers are
split into frames of at most `CMD_DFSMAXLEN`/512 sectors for reads and
(`CMD_DFSMAXLEN`-10)/512 for writes. With the default 4096 that is 8 and 7
sectors. Card status codes pass through as INT 13h status (03h write
protected, 04h, 20h, 80h). A transport timeout or a missing USB drive gives
80h, and a frame the card rejects twice gives 20h.

Every BDREAD/BDWRITE carries the unit's image token from the last BDINFO.
If the floppy image was swapped in between, the card answers 06h. The ROM
passes 06h on (CF set, DOS re-reads the disk), refreshes the unit (new
token and geometry, so the next call works) and also reports the change at
the next AH=16h. For the hard disk, a token mismatch (card rebooted,
different file) is 80h "not ready" until the next boot.

A call that comes in while a request is in progress (an interrupt handler
calling INT 13h during the poll) gets AAh "drive not ready" with CF set, and
the transaction in flight is not disturbed.

### Transport

Every transaction knocks and selects its register again, because another
program may have changed it. On a 186 or later the ROM moves data with
`rep outsw`/`rep insw`. On an 8086/8088 it uses `lodsw/out dx,ax` and
`in ax,dx/stosw` loops, and an odd last byte moves as a single byte. The
CPU test is the shift-count mask, so a NEC V20 counts as an 8088. After
`CMD_DFSEXEC`, the ROM polls `CMD_DFSSTAT`. Reads, verifies and BDINFO get
about 10 s. Writes and BDINFO with OPEN get about 30 s, because the card's
USB write deadline is 10 s per operation and one BDWRITE (write plus sync)
can take several. The time is counted in changes of the BIOS tick count,
and a timeout also needs a minimum number of status reads (ticks x 1.2 x
65536; one ISA read takes at least about 0.7 us). A program that speeds up
the timer therefore cannot shorten the timeout. With interrupts off, twice
that many reads end the wait. On a timeout the ROM aborts the transaction
and returns 80h. An ABORTED status makes it send the request once more, and
NODRIVE returns 80h. Before it starts a request, the ROM reads
`CMD_DFSSTAT`. If another client's request is BUSY (PGUSDFS interrupted by
an INT 13h call), the ROM waits for it to finish, within the same timeout.

### RAM block (1 KB at segment `[40:13h]*64` after the late init)

| Offset | Content |
|---|---|
| 00h | `PGBT`, old INT 13h, old INT 19h, ROM segment, data port, sectors per read/write frame, CPU flag, installed units, last translated drive, saved 40:10h / 40:75h, options, media-change latch, scratch |
| 30h / 48h | unit structures (floppy, hard disk): cylinders, heads (at most 255), sectors, total, drive type, flags, state, card unit, generation, image token. The geometry is only replaced by a valid BDINFO record, so an ejected floppy keeps its last geometry. |
| 60h | diskette parameter table (AH=08h/18h) |
| 70h | INT 13h trampoline: `push cs / push cs / jmp far ROM:int13_entry`. The INT 13h vector points here. The handler reads its RAM segment from the pushed words and puts the caller's DS back before it returns or chains. |
| 78h-B3h | transaction and transfer parameters |
| C0h-13Fh | BDINFO answer buffer |
| up to 400h | stack for the late init (the INT 13h handler runs on the caller's stack, about 50 bytes) |

If INT 19h runs again (a reboot through INT 19h), the ROM finds its block
through the INT 13h vector, undoes the previous installation and reuses the
block.

## Expected screen output

No card (or firmware without PGDFS/PGBOOT):
```
PGBOOT 0.1: PicoGUS not found, will look again at boot   [then at INT 19h: PGBOOT: PicoGUS not found]
PGBOOT 0.1: PicoGUS firmware without PGBOOT support
PGBOOT 0.1: PGDFS disabled or unsupported on the card
PGBOOT 0.1: disabled (pgusinit /bdopts bit 2)
```
Card found, floppy and hard disk image, the stick mounts a few seconds late:
```
PGBOOT 0.1: PicoGUS found, data port 1D4h (186+)       [(8088) on an XT, (8088 forced) for PGBOOT88.ROM]
PGBOOT: waiting for the USB drive (Esc skips)... 12    [only while not mounted; counts down from 15]
PGBOOT: A: \FD.IMG, 1440K
PGBOOT: C: \HD.IMG, 31M                                [" (read-only)" appended when read-only]
PGBOOT: booting A:
```
Other late-init lines, each followed by the normal BIOS boot:
```
PGBOOT: no disk image configured
PGBOOT: skipped                                        (Esc)
PGBOOT: no USB drive                                   (15 s passed)
PGBOOT: A: \MISSING.IMG - file not found               (also: - unusable image, - no USB drive,
                                                        - too fragmented (copy it to a freshly formatted drive), - not ready)
PGBOOT: no image ready
PGBOOT: C: card error 80h
PGBOOT: C: boot sector read error 04h
PGBOOT: C: not bootable (no 55AAh signature)
PGBOOT: continuing with the BIOS boot
```

## Tests

`tools/emu/run-tests.sh` (QEMU with the pgbridge device and the card
simulator) covers these cases:
* T1: FreeDOS floppy image, with a write.
* T2: T1 with `PGBOOT88.ROM`.
* T3: `FDISK /MBR` and `SYS C:` onto a blank hard disk image through the ROM.
* T4: boot that hard disk image.
* T5: USB drive mounted 3 s late.
* T6: no card.

`test/INT13TST.COM [W]` prints AH=08h/15h for 00h/80h/81h. It also tests
EDD 41h/48h, compares CHS against LBA reads over several frames, reads into
an odd unnormalised buffer, checks error codes, reads a physical 81h through
the translation, and with `W` does write/readback/restore on A: and the last
LBA of 80h. The last line is `INT13TST DONE, n failures`.

## Limitations

* Every sector goes through the USB drive and FatFs on the card. The ROM
  waits for each write until the card has synced the file, so disk-heavy
  work is slower than on a real disk.
* SMARTDRV and other write-behind caches hold writes in RAM. Turn write-behind
  off for the image drives (`SMARTDRV C-` or `/X`), or flush before a power
  cycle, or the image can end up inconsistent.
* Windows 9x runs these drives in MS-DOS compatibility mode (real-mode
  INT 13h, no 32-bit disk access), which is slow but works. Windows 3.x
  32-bit disk access (WDCTRL) does not apply: keep 32BitDiskAccess off.
* The ROM and PGUSDFS (the PGDFS redirector) share the card's single
  transport. Both knock and select for every transaction, so they coexist as
  long as neither is called from an interrupt handler while the other is in
  the middle of a transaction. A disk cache that flushes from the timer
  interrupt could do exactly that.
* An image that is in use must not be changed through PGUSDFS. The card
  refuses to modify, rename or delete an open image file (access denied),
  but other files on the stick are fine.
* The hard disk image must fit the CHS view for old DOS: at most 1024
  cylinders, 256 heads, 63 sectors. Larger images are reachable through
  EDD (LBA) only.
* No INT 41h/46h fixed disk parameter table is installed for the image.
  Software that reads the geometry from there instead of INT 13h AH=08h sees
  the physical disk.
* The pre-POST INT 19h is kept in vector 6Bh between POST and the late init
  (ROM only). If another ROM uses that vector at POST, change `OLD19_VEC`
  in `defs.inc` and rebuild.
* `PGBOOT.COM` depends on a clean boot, and its `/C` mode is untested on
  MS-DOS.
* A floppy image that was ejected (`/fdimage -`) still answers AH=08h with
  the last geometry. Reads return 80h.
* PGFLASH is untested on real EEPROMs. Its refusal paths (RAM,
  read-only window, running ROM) have been checked in QEMU.

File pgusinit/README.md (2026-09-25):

# PicoGUSinit

PicoGUSinit (also called pgusinit, after the program's .exe file) detects and
initializes a PicoGUS card. In GUS emulation mode, it should be used instead of
ULTRINIT.

For more info on PicoGUS, see https://picog.us/.

The board must be loaded with firmware before using it for the first time. See
https://github.com/polpo/picogus/wiki/Building-your-PicoGUS#programming-the-pico
for programming instructions if your card didn't come programmed. The `/flash
x` option to pgusinit can be used to upgrade firmware on a running PicoGUS.
Firmware files that comes with release:

* `picogus.uf2` - All modes are now in a single firmware. To switch between
  modes, use the `/mode x` option in pgusinit.
* `pg-ne2k.uf2` - Special firmware for NE2000/WiFi. Only works on PicoGUS
  Femto and PicoGUS v1.x boards with a Pico W installed.

pgusinit must be run with firmware it is compatible with. If run with an
incompatible firmware, pgusinit will complain about a protocol mismatch. One
exception to this is that pgusinit can be used to upgrade an older version of
firmware to a more recent version. For example, firmware v1.2.0, which is
normally incompatibile with pgusinit v3.0.0, can be upgraded to firmware
v2.0.0 with pgusinit v3.0.0.

## Using

Simply run `PGUSINIT.EXE` to detect and initialize your card with default
settings. Options may be given for other settings:

### Global options

* `/?` - shows help for PicoGUSinit. Detects the current card mode and only
  shows options valid for that mode.
* `/??` - shows help for PicoGUSinit for all modes.
* `/flash picogus.uf2` - uploads firmware in the file named picogus.uf2 to the
  PicoGUS. Used to upgrade firmware version.
* `/wtvol x` - sets wavetable header volume to x percent (PicoGUS 2.0 boards
  only).  Available in all modes in case you want to use the wavetable header
  as an aux input (for example for an internal CD-ROM drive).
* `/mainvol x` - sets main volume level for all outputs.
* `/mode x` - changes the card to mode specified by x. Options:
    - `gus`: Gravis Ultrasound
    - `sb`: Sound Blaster 2.0 & AdLib. Supports CD-rom emulation.
    - `mpu`: MPU-401 with intelligent mode and IRQ support
    - `psg`: Tandy 3-voice and CMS/Game Blaster. Supports USB serial mouse
      emulation.
    - `adlib`: AdLib only. Supports USB serial mouse emulation.
    - `usb`: Only emulates game port joystick and serial mouse via USB. Can be
      used if you don't want to emulate any sound cards. Supports CD-ROM
      emulation.
* `/save` - saves current settings to the card. Saved settings persist across
  reboots, meaning pgusinit does not need to be run. The card mode is also
  saved.
* `/defaults` - restores all card settings to defaults.
* `/joy 1|0` - enable USB joystick support with 1, disable with 0.

### GUS options

GUS emulation requires the ULTRASND variable to be set, in the format:

`set ULTRASND=240,1,1,5,5` where 240 is the PicoGUS's port, 1 is the DMA, and
5 is the IRQ. pgusinit will check that the port set on the PicoGUS matches the
port specified in ULTRASND.

* `/gusenv` - sets the base I/O port from ULTRASND variable.
* `/gusport x` - sets the base I/O port of the GUS to x. Defaults to 240.
* `/gusbuf n` - sets the audio buffer size to n samples. Defaults to 4 with a
  minimum of 1 and maximum of 256. Some programs require a different value to
  run properly. Going lower than 4 is not advisable.
* `/gusdma n` - sets the DMA interval to n microseconds. Games that use
  streaming audio over DMA work better with higher values. Doom, for example,
  runs well with a value of 10-12. Note that increasing this will slow sample
  loading. Set to 0 to use the GUS's default DMA interval handling, where the
  DMA interval is set by the program using it.
* `/gus44k 1|0` - setting to 1 enables fixed 44.1kHz output. Normally the GF1
  varies its output sample rate from 44.1kHz at 14 voices to 19.2kHz at 32
  voices. Using this option enables 44.1kHz output for all numbers of voices,
  similar to the Interwave. This will result in stuttering in most games that
  use streaming DMA for sound effects like Doom, hence it is EXPERIMENTAL.
* `/gusvol x` - sets the volume of the GUS output to x percent.

See the Compatibility List wiki for notes on programs that require special
settings for the above options:
https://github.com/polpo/picogus/wiki/Compatibility-list

### Sound Blaster/AdLib options

Sound Blaster emulation requires the BLASTER variable to be set, in the format:

`set BLASTER=A220 I5 D1 H1 T6`, where 220 is the PicoGUS's SB emulation port,
5 is the IRQ, 1 is the DMA, 6 is the emulated SB type (see `/sbtype` option)

* `/sbenv` - sets SB base port, IRQ, DMA and type from BLASTER variable.
* `/sbport x` - sets the base port of the Sound Blaster. Defaults to 220.
* `/sbirq x` - sets the IRQ of the Sound Blaster. Must match jumper settings.
* `/sbdma x` - sets the DMA of the Sound Blaster. Must match jumper settings.
* `/sbtype x` - sets the Sound Blaster type: Allowed values are:
  1 - SB 1.x,          2 - SB Pro 1 (dual OPL2), 3 - SB 2.0
  4 - SB Pro 2 (OPL3), 6 - SB 16
* `/oplport x` - sets the base port of the OPL/AdLib. Defaults to 388.
* `/oplwait` - wait on OPL2 data write. Can fix speed-sensitive early AdLib
  games on fast systems (example: 688 Attack Sub).
* `/sbvol  x` - sets the volume of the SB PCM output to x percent.
* `/oplvol x` - sets the volume of the OPL2 output to x percent.
* `/sbfixtc 1|0 ` - fix SB time constant for 11/22/44 kHz sample rate. Can fix
  PCM audio slightly pitched up or down in pre-SB16 games and applications.
  Note than certain programs are already aware of SB time constant inaccuracy
  and will sound wrong if this option is enabled. Default = 0 (disabled)
* `/sblockmixer n` - lock writes to SB mixer settings. Choices:
  0 - write lock disabled (default)
  1 - lock all but Voice Volume registers (for panning effects e.g. in Wolf3D)
  2 - lock all registers

### MPU-401 options

* `/mpuport x` - sets the base port of the MPU-401. Defaults to 330.
* `/mpudelay` - set to 1 to enable sysex delay to prevent buffer overflows on
  older MPU-401 revisions.
* `/mpufake` - set to 1 to fake all-notes-off for the Roland RA-50.

### Tandy options

* `/tandyport x` - sets the base port of the Tandy 3-voice. Defaults to 2c0.
* `/psgvol x` - sets the volume of the PSG output to x percent.

### CMS options

* `/cmsport x` - sets the base port of the CMS. Defaults to 220.
* `/psgvol x` - sets the volume of the PSG output to x percent.

### Serial mouse settings

Since a COM port requires an IRQ, serial mouse emulation is possible in modes
that do not require an IRQ: AdLib, CMS, Tandy, and USB.

* `/mousecom n` - mouse COM port. Default: 0, Choices: 0 (disable), 1, 2, 3, 4
* `/mouseproto n` - set mouse protocol. Default: 0 (Microsoft). Choices:
     0 - Microsoft Mouse 2-button,      1 - Logitech 3-button
     2 - IntelliMouse 3-button + wheel, 3 - Mouse Systems 3-button
* `/mouserate n` - set report rate in Hz. Default: 60, Min: 20, Max: 200.
  Increase for smoother cursor movement, decrease for lower CPU load
* `/mousesen n` - set mouse sensitivity (256 - 100%, 128 - 50%, 512 - 200%)

### CD-ROM emulation options

* `/cdport x` - set base port of CD interface. Default: 250, 0 to disable
* `/cdlist` - list CD images on the inserted USB drive
* `/cdload n` - load image n in the list given by /cdlist. 0 to unload image
* `/cdloadname x` - load CD image by name. Names with spaces can be quoted
* `/cdauto 1|0` - auto-advance loaded image when same USB drive is reinserted
* `/cdvol x` - sets the volume of the CD audio output to x percent.

### PGDFS options

* `/dfsport x` - set the PGDFS data port (hex). Default: 1D4, 0 to disable
  PGDFS. The port must be even (the data window is two consecutive ports,
  1D4-1D5 by default), between 100 and 3FE, and clear of the PicoGUS control
  ports 1D0-1D3; the card keeps its old value otherwise. The PGDFS driver
  reads this setting from the card once, at install, so after changing the
  port (or `/defaults`) unload and reload the driver: `PGUSDFS /U`, then
  `PGUSDFS E:`. Keep the window clear of the ports of the emulated devices
  active in your mode (220h Sound Blaster, 250h CD-ROM, 330h MPU-401, 388h
  AdLib, ...); pgusinit warns when it overlaps one. Use `/save` to keep the
  setting across reboots.

### PGBOOT options (experimental)

These configure the PGBOOT option ROM, which boots floppy and hard disk
images stored on the USB drive (see `sw/bootdisk/PROTOCOL.md`). They need
firmware with PGBOOT support; with older firmware pgusinit says so and changes nothing.

* `/fdimage x` - floppy image presented as drive A:, a path on the USB drive
  (`\DISKS\DOS622.IMG`; use backslashes, a leading `/` reads as the next
  option). `-` removes it. The card switches to the new image at once, so a
  running system sees a media change, as if the disk had been swapped. Raw
  images of the standard sizes (160K to 2.88M, DMF) or with a DOS boot
  sector, and fixed VHD files, are accepted.
* `/hdimage x` - hard disk image presented as drive C: (the physical hard
  disks move up by one), `-` removes it. A raw image or a fixed VHD. The
  change takes effect at the next boot: a running system keeps the disk it
  booted with.
* `/bdopts n` - option bits, add them up: 1 floppy image read-only, 2 hard
  disk image read-only, 4 disable the ROM (it installs nothing), 8 boot the
  hard disk image even when a floppy image is configured. Default: 0.

All three are stored with the other settings: use `/save` to keep them
across power cycles. pgusinit shows the configured images and options in its
status output (`PGBOOT floppy image: ...`) when the firmware supports PGBOOT.
The images live on the USB drive that PGDFS serves, and the ROM reaches them
through PGDFS, so PGDFS must be enabled (`/dfsport`, not 0). While an image
is in use, PGDFS refuses to delete, rename or write that file.

## PGDFS (USB drive as a DOS drive letter)

Firmware with PGDFS support serves the FAT-formatted USB drive plugged into
the PicoGUS to DOS as a network drive letter. pgusinit shows the state of
PGDFS on a `PGDFS data port 1D4, USB drive: ...` line in its normal status
output (data port, then the drive's label, file system and size, or `none
inserted`), or `PGDFS disabled (pgusinit /dfsport 1D4 to enable)` when the
data port has been set to 0, when the firmware supports it. The DOS driver
itself is a separate TSR, `PGUSDFS.EXE`, which comes with its own test tool
`DFSDIAG.EXE`; see `pgusdfs/README.md` for usage and requirements.

## Compiling

PicoGUSinit can be compiled with OpenWatcom 1.9 or 2.0. Run `wmake` to compile.

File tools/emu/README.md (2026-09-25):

# Emulator test harness for PGBOOT and PGDFS

End-to-end tests of the PGBOOT option ROM (`bootrom/`) and the PicoGUS
card-side code (`sw/dfs`, `sw/bootdisk`) without hardware:

```
 QEMU (i386 PC, SeaBIOS)                     pgcard-sim (host process)
 +-----------------------------+   UNIX     +------------------------------------------+
 | FreeDOS / PGBOOT.ROM        |  socket    | core 0: knock/select, 1D1h/1D2h regs      |
 |   in/out 1D0h-1D2h, 1D4h-5h |----------->|   -> real dfs_ctl_* / dfs_data_* / bd_ctl_*|
 | pgbridge ISA device         |  byte      | core 1: real dfs_tasks() -> dfs_server,   |
 |   (8-bit card: word access  |  cycles    |   dfs_fs, bootdisk, FatFs                 |
 |    = 2 byte cycles)         |<-----------| USB stick: raw image file (file diskio)   |
 +-----------------------------+            +------------------------------------------+
```

* `qemu/pgbridge.c` - the QEMU device; `qemu/pgbridge.patch` - the same file
  plus Kconfig/meson wiring, generated by `qemu/mkpatch.sh`.
* `sim/` - `pgcard-sim`. Core 0 register logic mirrors `sw/picogus.cpp`
  (`select_picogus`, `write_picogus_low/high`, `read_picogus_low/high`) for the
  registers the ROM, pgusinit and PGUSDFS use; everything behind the registers
  is the real firmware code compiled for the host.
* `lib.sh`, `run-tests.sh` - image builders and the tests.
* `buscheck.py` - drives the card over the bridge protocol directly (no QEMU)
  the way the ROM does, and checks the PGBOOT registers and frames (test S1).

Nothing large is kept in the repository: QEMU, FreeDOS, the DOS tools, the
simulator build and all test images live in `$EMU_CACHE`
(default `~/pico/emu-cache`: about 1.7 GB with the QEMU source and build
trees, about 200 MB without them, `CLEAN=1 tools/emu/build-qemu.sh` removes
them after installing; the next build re-extracts the tarball).

## Requirements

* macOS or Linux, a C compiler, make, python3.
* QEMU build: ninja, pkg-config, glib, pixman, libfdt
  (`brew install ninja pkgconf glib pixman dtc`). QEMU brings its own meson.
* mtools (`brew install mtools`) for all disk images.
* OpenWatcom in `~/pico/watcom` (or `$WATCOM`) for T0, T9 and T10: the
  harness builds `DFSDIAG.EXE`, `PGUSDFS.EXE` and `PGUSINIT.EXE` out of tree
  into `$EMU_CACHE/dos` with the flags of their Makefiles (nothing is written
  into `pgusdfs/` or `pgusinit/`), again whenever a source is newer.
* The ROM images for T1-T11: `bootrom/PGBOOT.ROM` and `bootrom/PGBOOT88.ROM`
  (`make -C bootrom`, nasm); a test whose ROM is missing reports SKIP.

## Build

```
tools/emu/build-qemu.sh          # downloads qemu-10.2.4, patches, builds i386-softmmu only
make -C tools/emu/sim            # pgcard-sim ($EMU_CACHE/sim-build/pgcard-sim)
```

`build-qemu.sh` configures with `--without-default-features --enable-tcg
--enable-pixman --enable-vnc --target-list=i386-softmmu` (no docs, no GUI
toolkits, no audio, no networking back ends), installs to
`$EMU_CACHE/qemu` and drops the firmware blobs of other targets. When
`pgbridge.patch` changed it swaps the old patch for the new one in the
existing tree (incremental rebuild) and re-extracts only if that fails.
After editing `qemu/pgbridge.c`, run `qemu/mkpatch.sh` and then `build-qemu.sh`.

The simulator Makefile uses the real `sw/bootdisk/*.c` as soon as that
directory defines `bd_init()`, and `sim/bd_stub.c` (answers AX=01h to every
PGBOOT frame) before that; `make -C tools/emu/sim info` says which.
FatFs is `sw/fatfs/source` with `sw/dfs/test/ffconf_host.h` (read/write, LFN,
fast seek), copied next to `ff.h` in the build directory as that Makefile does.

## Run

```
tools/emu/run-tests.sh                 # T0 S1 T1 ... T11 (about 1.5 minutes)
tools/emu/run-tests.sh T0 T3 T4        # a selection
KEEP=1 SIM_LOG=3 tools/emu/run-tests.sh T1
SIM_EXTRA='--busy-polls 300' tools/emu/run-tests.sh    # a slow card: long BUSY phases
ROMDIR=/some/dir tools/emu/run-tests.sh                # other PGBOOT.ROM / PGBOOT88.ROM
```

Every test prints PASS/FAIL/SKIP and a short excerpt of the guest's COM1
output; the evidence stays in `$EMU_CACHE/work/<test>/`:

| file | content |
|---|---|
| `serial.txt` | COM1 of the guest (the DOS batch files redirect everything there) |
| `sim.log` | card trace: register selects, every frame (`REQ #n BDREAD unit=0 count=7 lba=...`, `ANS #n AX=...`), status changes, USB mount |
| `screen-early.txt`, `screen.txt` | text screen (B800h) a few seconds after power-on and at the end: SeaBIOS, ROM and kernel messages |
| `qemu.log` | QEMU's stderr |
| `*.img` | stick, floppy and hard disk images (deleted after a PASS unless `KEEP=1`) |

## Tests

| Test | What runs | What it proves |
|---|---|---|
| S1 | `buscheck.py` against the sim, no QEMU | Card PGBOOT server over the exact bus sequence: `CMD_BDOPTS` signature, image names, nothing open before BDINFO OPEN (state 0, BDREAD -> 80h), BDINFO (state, CHS, total, floppy type, image token), BDREAD (content equals the image, max-size frames, end of image -> 04h), BDWRITE + read back, wrong token -> 06h floppy / 80h hard disk, new token after OPEN and after a floppy name commit, unknown unit -> 01h. Also shows BUSY -> READY. |
| T0 | Native QEMU floppy boot (FreeDOS), `DFSDIAG /INFO /ECHO /DIR /LDIR /MKDIR` | Bridge + transport + real DFS server, without the ROM: detection registers, 16-bit reads at odd ports, word-wide data window both ways, 64..4096-byte frames, FatFs on the stick image, a write (MKDIR) visible with mtools. |
| T1 | `PGBOOT.ROM`, no native disks, stick with `FD.IMG`, sim `--fd FD.IMG` | The ROM boots FreeDOS from the floppy image: POST detection, INT 19h late init, BDINFO OPEN, INT 13h reads (boot sector, FAT, kernel, COMMAND.COM). Also reports whether a DOS write to A: reached `FD.IMG`. |
| T2 | as T1 with `PGBOOT88.ROM` | the 8088 transfer path (`in ax,dx`/`out dx,ax` loops instead of `rep insw`/`outsw`; the ROM's banner says `(8088 forced)`, on the bus both paths are the same byte-cycle pairs) |
| T3 | ROM, stick with an installer floppy + an empty partitioned FAT16 `HD.IMG` (65/16/63, 32 MB), sim `--fd --hd` | INT 13h writes through the ROM: `FDISK /MBR` (MBR code), `SYS C:` (boot sector, KERNEL.SYS, COMMAND.COM), COPY. Verified afterwards with mtools on `HD.IMG` extracted from the stick. |
| T4 | ROM, stick with only `HD.IMG`, sim `--hd HD.IMG` | Booting FreeDOS from the hard disk image (C:), and a write to C:. Uses T3's image if T3 passed in the same run, else a reference image prepared natively (`P4`). |
| T5 | T1 with `--mount-delay-ms 3000` | The ROM's wait loop: the card reports NODRIVE (FFh) for 3 s after power-on, then the stick mounts and the boot continues. |
| T6 | ROM without `-device pgbridge`, native floppy | No card: the ROM prints `PicoGUS not found` (regex `ROM_NOTFOUND_RE`) and SeaBIOS boots the native floppy. |
| T7 | ROM + card, `--fd MISSING.IMG`, native floppy | Card present but no image ready: the ROM reports "file not found" and chains to the BIOS INT 19h, which boots the native floppy. |
| T8 | ROM, `--fd FD.IMG --hd HD.IMG --opts 8` | Both drives presented, option bit 3 boots C: instead of A:. |
| T9 | ROM, FreeDOS on FD.IMG runs `PGUSINIT /fdimage FD2.IMG` | Floppy swap under a running DOS: the card reopens unit 0 and flags a media change, the ROM reports it through INT 13h, DOS re-reads FAT and directory (new label, a file only FD2.IMG has). FreeCOM re-reads AUTOEXEC.BAT by name and offset, so the checks after the swap only exist on FD2.IMG. |
| T10 | ROM boot, then `PGUSDFS D:` | PGDFS and PGBOOT together: the stick as D:, a D: -> A: copy, and DEL/REN of the open `FD.IMG` refused by the card (DELETE/RENAME answer AX=05h in the trace, the file is still on the stick). |
| T11 | ROM, card `--dfsport 0x2a0`, bridge `dataport=0x2a0` | The ROM takes the data window from `CMD_DFSPORT` instead of assuming 1D4h. |
| P4 | native QEMU floppy + IDE disk, no ROM, no card | Helper: the reference hard disk for T4/T8 when T3 did not run (FDISK /MBR + SYS C: through SeaBIOS INT 13h). |

The markers the tests wait for are written by `AUTOEXEC.BAT` with
`ECHO PGBOOT-... > COM1`; there is no power-off, the harness kills QEMU after
the marker and a final screen dump. Timeout per test: `TIMEOUT` (90 s).

## Test images

* FreeDOS 1.3 FloppyEdition (official, sha256-checked,
  `FD13-FloppyEdition.zip` from ibiblio): its 1.44 MB boot disk is the template
  for every floppy (FreeDOS FAT12 boot sector that loads `KERNEL.SYS` by name);
  the installer is removed and `COMMAND.COM`, `FDAPM.COM`, a minimal
  `FDCONFIG.SYS` and the test's `AUTOEXEC.BAT` are added. `SYS.COM` and
  `FDISK.EXE` come from the same disk.
* The stick is a 96 MB FAT32 superfloppy (`mformat -F`), label `PGSTICK`.
* The hard disk is 65 cyl x 16 heads x 63 sectors with one active type-04
  FAT16 partition at sector 63 (`mpartition`, `mformat -H 63`), no boot code:
  that is what T3/P4 install.

## pgcard-sim

```
pgcard-sim --stick IMAGE [--fd NAME] [--hd NAME] [--opts N] [--mount-delay-ms N]
           [--dfsport N] [--busy-polls N] [--socket PATH] [--persist] [--log[=N]] [--logfile F]
```

* The stick mounts `--mount-delay-ms` after the bridge connects (QEMU start),
  then `dfs_on_drive_mounted()` runs like in `usb_msc/msc_app.c` (which also
  opens the PGBOOT images: `dfs_server_drive_mounted()` calls
  `bd_on_drive_mounted()`). Until then the status reads NODRIVE.
* Core 1: `dfs_tasks()` (which also runs `bd_tasks()`) runs whenever the
  socket is idle for 1 ms, after every control/data-port write except a
  pending request, and when the status is polled: a request stays BUSY for
  `--busy-polls` status reads (default 1), so the ROM sees `02 03`, not just
  `03`.
* `--fd/--hd/--opts` are the persisted settings (`Settings.BootDisk`);
  `CMD_SAVE` only logs them. `CMD_FLASH`/`CMD_REBOOT` are not simulated.
* The data window is decoded at the card's current `CMD_DFSPORT` value; the
  bridge only forwards the window it was created with (`dataport=`), so a
  guest that moves the window loses it, as on a machine where the new ports
  are decoded by something else.
* Log levels: 1 registers and frames, 2 every status poll, 3 disk I/O
  (`disk R/W lba n`), 4 every port access.

## Bridge wire protocol

8-byte messages, little-endian: `op, size(1), port(u16), value(u32)`.
QEMU sends `'r'` (read, blocks for a `'R'` reply carrying the byte) and `'w'`
(write, posted). The device sets `impl.max_access_size = 1` and
`valid.unaligned = true`, so the QEMU memory core splits `in ax, dx` /
`rep insw` into two byte cycles, base then base+1, exactly what an 8-bit ISA
card sees (including `in ax, 1D1h`). Properties: `path` (socket, required),
`dataport` (default 0x1d4, 0 = none), `timeout` (seconds to wait for the
socket at start, default 10).

## SeaBIOS and the option ROM

`-option-rom FILE` hands the ROM to SeaBIOS (1.17.0 in QEMU 10.2) through
fw_cfg (`/rom@genroms/PGBOOT.ROM`). SeaBIOS copies it to the option ROM area
(CC80h here, after `kvmvapic.bin` at CA00h) and runs its init entry during
POST ("Running option rom at cc80:0003" in the SeaBIOS debug log, captured
with `-chardev file,id=sb,path=seabios.log -device isa-debugcon,iobase=0x402,chardev=sb`).
PGBOOT hooks INT 19h there, and SeaBIOS leaves that vector alone: at the end
of POST SeaBIOS boots by issuing INT 19h (`startBoot`), so the ROM's handler
runs first, before any SeaBIOS boot entry. The screen shows the PGBOOT lines
right after the SeaBIOS banner with no "Booting from ..." line (T1-T5, T8-T11).
When the ROM has nothing to boot it chains to the previous vector and SeaBIOS
runs its normal boot order: "Booting from Hard Disk... Boot failed", then
"Booting from Floppy..." (T7; QEMU's default order for `-M pc` is hard disk,
floppy, CD). With no card the ROM does not hook INT 19h at all (T6). So no
`-boot order`/`bootorder` tweaking is needed; the tests pass `-boot menu=off`
only to rule out the boot menu prompt.

## Debugging

* `SIM_LOG=3` (or 4) for the card trace, `KEEP=1` to keep the images.
* Run a test by hand: `pgcard-sim --stick stick.img --fd FD.IMG --log --socket /tmp/pg.sock &`
  then `qemu-system-i386 -M pc -m 16 -display none -nic none -serial stdio
  -option-rom bootrom/PGBOOT.ROM -device pgbridge,path=/tmp/pg.sock`.
  To watch the screen, add `-vnc :1` and connect a VNC viewer to port 5901
  (QEMU is built without curses/SDL/Cocoa).
* The sim exits when QEMU disconnects (`--persist` keeps it listening); a
  guest reboot inside one QEMU run keeps the card state (the simulator has
  no ISA RESET line).
* QEMU: `-d int,in_asm -D qemu.trace` (large), `-d unimp,guest_errors`,
  `-monitor stdio` then `info registers`, `x/16xb 0xc8000`,
  `pmemsave 0xb8000 4000 screen.bin`.
* The screen dumps (`screen*.txt`) come from `pmemsave` of B800:0000 through
  the HMP monitor socket.

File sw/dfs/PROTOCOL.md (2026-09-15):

# PGDFS wire protocol

PGDFS lets a DOS network-redirector TSR (`PGUSDFS.EXE`) use the USB drive plugged
into the PicoGUS as a drive letter. DOS forwards every file operation on that
letter (open, read, find-first, mkdir, ...) to the TSR as an INT 2Fh/11h call;
the TSR packs the call into a request frame, ships it to the card, and unpacks
the answer. The card serves the request from its own FatFs volume, so DOS never
sees sectors and the volume format is the card's business.

The request/answer payloads are the EtherDFS "EDF5" protocol (Mateusz Viste,
MIT), which is also what PicoMEM's PMDFS speaks. Only the framing and the
transport differ: EtherDFS uses raw Ethernet frames, PMDFS a shared-RAM window,
PGDFS a byte stream over a two-port ISA I/O window.

## Ports and registers

Everything rides on the existing PicoGUS control protocol (`common/picogus.h`):
knock `CCh` on `CONTROL_PORT` (1D0h), write a register number, then move data
through `DATA_PORT_LOW` (1D1h) / `DATA_PORT_HIGH` (1D2h). PGDFS adds a two-port
data window and eight registers.

| Reg / port | Name | Access | Meaning |
|---|---|---|---|
| `1D4h`-`1D5h` (default) | data window | byte stream, 8- or 16-bit | Request bytes in (`rep outsw`), answer bytes out (`rep insw`). Two consecutive ports at an even base; both feed the same byte stream, so a word access carries stream byte n in the low byte (base) and n+1 in the high byte (base+1), and single-byte accesses to either port work as well. Direction follows the selected register. Base set with `CMD_DFSPORT`. |
| `80h` | `CMD_DFSSTAT` | read 1D2h / write 1D2h | Read: `dfs_status_t`. Any write aborts the current transaction and returns to IDLE. |
| `81h` | `CMD_DFSREQ` | select | Rewinds the write pointer. Subsequent data window writes append to the request frame. Status becomes RECEIVING. |
| `82h` | `CMD_DFSEXEC` | write 1D2h (any value) | Validates the frame (received bytes == declared length, length within limits) and sets BUSY; core 1 serves it. Invalid frame: ABORTED. |
| `83h` | `CMD_DFSRESP` | select | Rewinds the read pointer. Subsequent data window reads stream the answer frame. Valid only in READY. |
| `84h` | `CMD_DFSINFO` | read string 1D2h | Zero-terminated `LABEL|FS|<size MB>|<serial hex>`; empty string when no drive is mounted. Reading the terminator rewinds. |
| `85h` | `CMD_DFSMAXLEN` | read 16-bit 1D1h/1D2h | Largest payload (bytes, excluding header) the card accepts in one frame. Reads 0 when PGDFS is disabled (`CMD_DFSPORT` = 0). Firmware without PGDFS returns FF00h here (low byte 00h, high byte FFh); the driver treats anything outside 128..32768 as "not supported". |
| `86h` | `CMD_DFSTIME` | write 1D2h, 4 bytes | DOS packed time (lo, hi) then packed date (lo, hi), FAT format. Used for timestamps on files the card creates or modifies. |
| `87h` | `CMD_DFSPORT` | read/write 16-bit 1D1h/1D2h | Base of the data window, handled like `CMD_CDPORT`: write the low byte to 1D1h, then the high byte to 1D2h, which commits; reads return the current value, 0 when disabled. Bit 0 is ignored (the base is forced even). 0 disables PGDFS: `CMD_DFSMAXLEN` reads 0 and the window is not decoded. Bases below 100h, above 3FEh, or whose window overlaps 1D0h-1D3h are rejected and the previous value kept. Stored in the card's settings (`pgusinit /dfsport`, persisted by `pgusinit /save`); default 1D4h. |

Protocol version (`CMD_PROTOCOL`) is 5 with PGDFS present. The driver requires `>= 5`.

Reads of `1D2h` and of the data window hold IOCHRDY only for the time it takes
core 0 to fetch one byte from RAM. Writes to the data window use the
IOCHRDY-stalled path as well, so the PIO FIFO can never overflow during
`rep outsw`. Core 0 never waits on USB or FatFs inside a bus cycle; the DOS side
waits on the status byte instead.

### Why a word-wide window on an 8-bit card

The PicoGUS is an 8-bit ISA card, so it never sees a 16-bit bus cycle. When
the CPU executes `out dx, ax` / `in ax, dx` (or `rep outsw` / `rep insw`) on an
8-bit port, the 8088 itself, or the bus controller of a 286+ motherboard,
splits the access into two 8-bit cycles, the base port with the low byte and
then base+1 with the high byte, with no extra CPU work. Both ports of the
window feed the same stream, so every iteration moves two stream bytes and the
CPU cost per byte roughly halves compared with `rep outsb` / `rep insb`.
`insw`/`outsw` are 186+ instructions; an 8086/8088 driver gets the same effect
from `in ax, dx` / `stosw` and `lodsw` / `out dx, ax` loops.

The card decodes the other emulated devices (GUS, SB, MPU-401, CD-ROM, ...)
before the PGDFS window, so a window placed on one of their ports is shadowed
by that device: pick a free even base, as for any other card in the machine.

## Status machine

```
            CMD_DFSREQ                CMD_DFSEXEC (ok)          core 1 done
  IDLE ---------------> RECEIVING -----------------------> BUSY ------------> READY
   ^                       |                                                  |
   |   CMD_DFSEXEC (bad)   v                                                  |
   +---------------- ABORTED <--------- CMD_DFSSTAT write (from any state) <--+
   |
   +--- NODRIVE: reported instead of IDLE while no USB drive is mounted
```

* `IDLE (0)`: nothing in flight. Selecting `CMD_DFSREQ` starts a transaction.
* `RECEIVING (1)`: the card is collecting request bytes.
* `BUSY (2)`: core 1 owns the buffer and is talking to FatFs/USB.
* `READY (3)`: the answer frame is in the buffer; select `CMD_DFSRESP` and read.
  The next `CMD_DFSREQ` discards it.
* `ABORTED (FEh)`: the last request was rejected (length mismatch, oversize) or
  aborted through `CMD_DFSSTAT`. Sticky until the next `CMD_DFSREQ`.
* `NODRIVE (FFh)`: no USB drive is mounted; reported in place of IDLE and
  ABORTED. Requests are refused. Also what firmware without PGDFS returns for
  an unknown register, so the driver must check `CMD_DFSMAXLEN` (FF00h without
  PGDFS, 0 with PGDFS disabled) and the protocol version at install, not this
  byte.

A write to `CMD_DFSSTAT` while BUSY cannot stop core 1: the status keeps
reading BUSY until core 1 finishes, then it becomes ABORTED (the result is
dropped through a generation counter). A driver that gave up on a request
therefore sees BUSY on its next transaction and simply waits for it; it
never streams a new frame into a buffer the card is still writing. A
`CMD_DFSREQ` or `CMD_DFSEXEC` arriving while BUSY is ignored.

## Frame format

Little-endian. The answer overwrites the request in the same buffer on both
sides, so the driver needs one buffer, not two.

```
request : LL LL DD AL  payload...
          LL LL = total frame length including this 4-byte header
          DD    = drive index in bits 0-4 (0 = the USB drive), flags in bits 5-7 (0)
          AL    = INT 2Fh/11h subfunction (EDF5 "query"), or a PGDFS extension

answer  : LL LL AX AX  payload...
          LL LL = total frame length including this 4-byte header
          AX AX = DOS result: 0 = success, else the DOS error code (2 = file not
                  found, 3 = path not found, 5 = access denied, 15h = drive not
                  ready, 12h = no more files, 1Dh = write fault, 1Eh = read
                  fault, ...)
```

Error codes that tell the layers apart: `15h` (drive not ready) means no drive
is mounted, FatFs found no file system, or the volume is not enabled; `1Dh`
(write fault) is a WRITE, CLOSE, SETFILETIMESTAMP or MKDIR whose disk write
(or a FatFs internal consistency check) failed underneath a mounted volume;
`1Eh` (read fault) is the same for READ; `13h` is a write-protected drive;
`05h` from MKDIR or CREATE can also mean that FatFs believes the volume has
no free cluster. `DIAG` (F2h) says which.

Maximum payload per frame is `CMD_DFSMAXLEN` (4096 by default). READ and WRITE
requests are chunked by the driver to fit; every other subfunction fits in one
frame.

## Transaction, driver side

`dfs_port` is the window base read from `CMD_DFSPORT` at install (0: PGDFS is
disabled, do not install). Frames move a word at a time; an odd byte count ends
with one byte access.

```
out 1D0h, CCh          ; knock
out 1D0h, 81h          ; CMD_DFSREQ: open request buffer
mov dx, dfs_port
mov cx, frame_len      ; the whole frame, header first
shr cx, 1              ; words; CF = one trailing byte
rep outsw              ; 186+ (8086/8088: lodsw / out dx, ax loop)
jnc @f
outsb
@@:
out 1D0h, 82h          ; CMD_DFSEXEC
out 1D2h, 01h
out 1D0h, 80h          ; CMD_DFSSTAT
loop: in al, 1D2h
      3 -> ready, FEh -> aborted, FFh -> no drive, else keep polling
      give up after ~30 s (BIOS tick count): abort via out 1D2h, 0 and fail with error 15h
out 1D0h, 83h          ; CMD_DFSRESP
mov dx, dfs_port
in ax, dx              ; header: frame length
mov cx, ax
in ax, dx              ; header: AX result
sub cx, 4
shr cx, 1
rep insw               ; payload (8086/8088: in ax, dx / stosw loop)
jnc @f
insb
@@:
```

The driver never re-sends a request that got READY. On ABORTED it re-sends
once (a lost byte during a bus glitch, or the card finishing a request the
driver had already given up on); a second ABORTED is reported to DOS as
error 15h (drive not ready). The poll timeout is about 30 s: an unplugged
drive is reported at once as NODRIVE, so the timeout only matters for hangs,
and legal work such as a wildcard DELETE over hundreds of files can take
several seconds.

The knock plus register select is part of every transaction because another
program (pgusinit) may have changed the selected register in between.

## Time

At install, and on `PGUSDFS /T`, the driver writes the DOS clock through
`CMD_DFSTIME`. Core 0 collects the four bytes and hands them to core 1,
which keeps `dos_time + elapsed` and returns it from `get_fattime()`. Without it, files created from DOS carry the FatFs default
timestamp (1 Jan 1980 or the firmware's fixed value).

## Drive info

`CMD_DFSINFO` returns `LABEL|FAT32|30528|1A2B3C4D` style strings: volume label
(may be empty), filesystem (`FAT12`/`FAT16`/`FAT32`/`EXFAT`), size in MB,
volume serial in hex. `pgusinit` shows it; `PGDFS` shows it at install.

## Subfunctions (EDF5 payloads)

Payloads are unchanged from EtherDFS. Summary, from EtherDFS `protocol.txt`
(Mateusz Viste, MIT). "SS" is the 16-bit file id the server assigned at OPEN
(EtherDFS calls it "starting sector"); "CC" is the 16-bit directory id and "pp"
the position used to continue a search.

| AL | Name | Request payload | Answer payload |
|---|---|---|---|
| 01h | RMDIR | path (`\DIR\SUB`) | - |
| 03h | MKDIR | path | - |
| 05h | CHDIR | path (existence check) | - |
| 06h | CLOSEFILE | SS | - |
| 08h | READFILE | OOOO offset, SS, LL length | data (may be shorter than LL at EOF) |
| 09h | WRITEFILE | OOOO offset, SS, data... | LL bytes written (LL=0 with data length 0 truncates at offset) |
| 0Ah/0Bh | LOCK/UNLOCK | NN count, SS, (OOOO ZZZZ)* | - (always success) |
| 0Ch | DISKSPACE | - | BX total clusters, CX bytes/sector, DX free clusters; AX = sectors/cluster (1) |
| 0Eh | SETATTR | A attr, path | - |
| 0Fh | GETATTR | path | tt time, dd date, ssss size, A attr |
| 11h | RENAME | L srclen, src path, dst path | - |
| 13h | DELETE | path (wildcards allowed) | - |
| 16h/17h/2Eh | OPEN/CREATE/SPOPNFIL | SS stack word (open mode for 16h, attributes for 17h/2Eh), CC action, MM mode, path | A attr, 11-byte FCB name, tt, dd, ssss size, CC file id, RR result (1 opened, 2 created, 3 truncated), o open mode |
| 1Bh | FINDFIRST | A attr mask, path with mask (`\DIR\FILE????.???`) | A attr, 11-byte FCB name, tt, dd, ssss, CC dir id, pp position |
| 1Ch | FINDNEXT | CC dir id, pp position, A attr, 11-byte FCB mask | same as FINDFIRST |
| 21h | SEEKFROMEND | oooo offset from end, SS | oooo offset from start |
| 24h | SETFILETIMESTAMP | tt, dd, SS | - |
| F0h | ECHO (PGDFS) | any bytes | the same bytes |
| F1h | LONGNAME (PGDFS) | path as DOS sees it: drive-relative, backslashes, 8.3 names (`\DIR\LONGNA~1.EXT`), no wildcards | the entry's long file name, no terminator (the short name itself when the entry has none, empty for the root); AX = 0, or GETATTR's errors: 2 file not found, 3 path not found, 15h no drive |
| F2h | DIAG (PGDFS) | - | the 60-byte diagnostics record below; AX = 0 always, with or without a drive (the drive index is ignored) |

Behaviour that the MS-DOS side relies on (all inherited from ethersrv-linux):
FINDFIRST in a non-root directory returns `.` and `..` first; a failing
FINDFIRST returns 12h (no more files), not 02h; DISKSPACE totals are capped just
under 2 GB; deleting a read-only file returns 05h; RENAME onto an existing name
fails; file and directory names are matched case-insensitively and reported as
8.3 names (FatFs short names, so long names appear as `LONGNA~1.EXT`).

## Diagnostics record (DIAG, F2h)

`DIAG` returns what the card knows about its own disk path, so a failing
write can be placed in the USB transfer, in FatFs or in the server from the
DOS side alone (`DFSDIAG /INFO` prints it, and `DFSDIAG` prints it after any
failed command). It never touches the drive: the values are counters kept by
the USB mass-storage glue (`sw/usb_msc/msc_app.c`) and the state of the FatFs
volume object as it is. AX is always 0; without a drive the volume fields are
zero and the counters still count. The layout is fixed and versioned by its
first byte; the same table is in `sw/dfs/dfs_server.h` (`DFS_DIAG_*`) and in
`pgusdfs/dfsdiag.c`. Little-endian; the u16 event counters saturate at FFFFh,
the u32 ones count since power-on.

| Offset | Size | Field |
|---|---|---|
| 0 | u8 | record version, 1 |
| 1 | u8 | flags: bit 0 = the server considers a drive present (status would not read NODRIVE) |
| 2 | u8 | FatFs volume type: 0 none, 1 FAT12, 2 FAT16, 3 FAT32, 4 exFAT |
| 3 | u8 | reserved, 0 |
| 4 | u32 | free clusters as FatFs currently believes them; a value greater than the cluster count means "unknown": the FAT has not been scanned since the mount (the first DISKSPACE does it, see FF_FS_NOFSINFO; FatFs starts at FFFFFFFFh) |
| 8 | u32 | FAT entries = clusters + 2 |
| 12 | u16 | sectors per cluster |
| 14 | u8 | last non-OK FatFs result of any call the server made (FRESULT, `ff.h` order: 1 DISK_ERR, 2 INT_ERR, 3 NOT_READY, 4 NO_FILE, 5 NO_PATH, 6 INVALID_NAME, 7 DENIED, 8 EXIST, ...); 0 = none since boot |
| 15 | u8 | which call produced it: 0 none, 1 f_open, 2 f_close, 3 f_lseek, 4 f_read, 5 f_write, 6 f_truncate, 7 f_sync, 8 f_stat, 9 f_chmod, 10 f_utime, 11 f_mkdir, 12 f_unlink, 13 f_rename, 14 f_opendir, 15 f_readdir, 16 f_closedir, 17 f_getfree, 18 f_getlabel |
| 16 | u8 | last "hard" FatFs result: as offset 14 but ignoring the lookup outcomes NO_FILE, NO_PATH, EXIST and INVALID_NAME, which DOS provokes constantly |
| 17 | u8 | which call produced it (same ids as offset 15) |
| 18 | u8 | DRESULT of the last disk read: 0 OK, 1 ERROR, 2 WRPRT, 3 NOTRDY, 4 PARERR |
| 19 | u8 | DRESULT of the last disk write |
| 20 | u8 | how the last disk read ended: 0 completed, 1 no drive mounted, 2 refused by the USB stack (endpoint busy or not mounted), 3 drive answered CSW status != 0, 4 no completion within the deadline (2 s for reads, 10 s for writes), 5 drive vanished during the transfer |
| 21 | u8 | how the last disk write ended (same codes) |
| 22 | u8 | bCSWStatus of the last SCSI command that completed with status != 0 (0 = none yet) |
| 23 | u8 | reserved, 0 |
| 24 | u32 | disk reads issued (`disk_read()` calls) |
| 28 | u32 | disk writes issued (`disk_write()` calls) |
| 32 | u16 | READ(10) commands the USB stack refused to start |
| 34 | u16 | WRITE(10) commands the USB stack refused to start |
| 36 | u16 | READ(10) commands completed with CSW status != 0 |
| 38 | u16 | WRITE(10) commands completed with CSW status != 0 |
| 40 | u16 | transfers abandoned at the deadline (2 s for reads, 10 s for writes) |
| 42 | u16 | transfers abandoned because the drive vanished |
| 44 | u32 | microseconds the last disk write took, from the call to its outcome (about 2 000 000 after a timeout) |
| 48 | u32 | first sector (LBA) of the last disk write |
| 52 | u16 | sectors in the last disk write (FatFs writes up to a cluster in one command when the caller's buffer allows it) |
| 54 | u16 | completions that arrived for a transfer the card had already abandoned (ignored, not charged to the current command) |
| 56 | u32 | dCSWDataResidue of the last SCSI command that completed with status != 0 |

A driver or tool that does not know the record simply skips it: the answer is
clipped to the frame like any other, and a record longer than the tool expects
(a later version) still starts with the fields above.
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

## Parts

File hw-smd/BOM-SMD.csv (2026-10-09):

References | Qty | Value | Type | Footprint | Manufacturer | MPN | DigiKey PN | DigiKey link | DigiKey stock 2026-09-29 | Unit NOK (1 board) | Line NOK (1 board) | Alternatives | Notes
U1 | 1 | Raspberry Pi Pico | THT module | RPi_Pico_SMD_TH | Raspberry Pi | SC0915 | 2648-SC0915CT-ND | https://www.digikey.no/no/products/result?keywords=2648-SC0915CT-ND | 42851 | 44.05 | 44.05 | Pico H SC0917 (DK 2648-SC0917-ND, 8889; JLCPCB lib C21351132). Pico W also works. | LCSC: Pico is only in the JLCPCB assembly parts library, not the LCSC shop - buy from DigiKey or an approved Raspberry Pi reseller. Solder on 2x 1x20 male headers (from the 1x40 strip) or socket it.
U2 | 1 | 74LVC244 | SMD TSSOP-20 | TSSOP-20_4.4x6.5mm_P0.65mm | Texas Instruments | SN74LVC244APW | 296-26609-5-ND | https://www.digikey.no/no/products/result?keywords=296-26609-5-ND | 2154 | 11.61 | 11.61 | Nexperia 74LVC244APW,118 (v1.2 BOM, DK 1727-2875-1-ND, 0 in stock today).
U3, U4 | 2 | SN74CB3T3257 | SMD TSSOP-16 | TSSOP-16_4.4x5mm_P0.65mm | Texas Instruments | SN74CB3T3257PWR | 296-17850-1-ND | https://www.digikey.no/no/products/result?keywords=296-17850-1-ND | 4031 | 19.96 | 39.93 |  | TSSOP-16. No DIP or SOIC version exists (only PW/DGV).
U5 | 1 | 74AHC14 | SMD SOIC-14 | SOIC-14_3.9x8.7mm_P1.27mm | Diodes Inc | 74AHC14S14-13 | 31-74AHC14S14-13CT-ND | https://www.digikey.no/no/products/result?keywords=31-74AHC14S14-13CT-ND | 3070 | 3.55 | 3.55 |  | Must be 74AHC14 (higher Schmitt threshold, see v1.2 changelog).
U6 | 1 | 74LVC00 | SMD SOIC-14 | SOIC-14_3.9x8.7mm_P1.27mm | Diodes Inc | 74LVC00AS14-13 | 31-74LVC00AS14-13CT-ND | https://www.digikey.no/no/products/result?keywords=31-74LVC00AS14-13CT-ND | 1816 | 3.65 | 3.65
U7 | 1 | 74LVC1G00 | SMD SOT-23-5 | SOT-23-5 | Texas Instruments | SN74LVC1G00DBVR | 296-9845-1-ND | https://www.digikey.no/no/products/result?keywords=296-9845-1-ND | 14500 | 1.34 | 1.34
U8 | 1 | APS6404L-3SQR-SN | SMD SOIC-8 | SOIC-8_3.9x4.9mm_P1.27mm | AP Memory | APS6404L-3SQR-SN [Adafruit 4677 (64Mbit QSPI PSRAM)] | 1528-4677-ND | https://www.digikey.no/no/products/result?keywords=1528-4677-ND | 4132 | 16.80 | 16.80 |  | SOIC-8. DigiKey does not stock the APS6404L itself; Adafruit 4677 is the DigiKey source (as in v1.2). Note: v1.2 BOM LCSC C139966 is actually a Vilsion VTI7064MSME (compatible).
U9 | 1 | PCM5100A | SMD TSSOP-20 | TSSOP-20_4.4x6.5mm_P0.65mm | Texas Instruments | PCM5100APWR | 296-36705-1-ND | https://www.digikey.no/no/products/result?keywords=296-36705-1-ND | 1419 | 25.15 | 25.15 | Pin-compatible PCM5102APWR (DK 296-36707-1-ND 619, LCSC C107671 6471) or PCM5101APWR. | TSSOP-20, no THT version exists. DAC AREA: leave out U9, C12-C20, FB3, R7 and R8 when the GY-PCM5102 module (J10) is fitted instead.
J10 | 1 | GY-PCM5102 module | THT (optional, instead of the DAC area) | GY-PCM5102_Module | generic | GY-PCM5102 |  |  |  |  |  |  | OPTION: replaces U9 + C12-C20 + FB3 + R7/R8 - exactly the parts under the dashed J10 module outline (the module has the same 470R/2.2nF output filter). Fit ONE of the two, never both. Not sold by DigiKey (AliExpress/eBay etc). Solder it almost flat, directly on 2.54 mm male pins: its 6-pin I2S header and a 4-pin piece of the 1x40 strip on AGND/ROUT/AGND/LROUT. No sockets: raised on 8.5 mm sockets it would hit a Waveblaster daughterboard. Set its solder jumpers H1=L H2=L H3=H H4=L.
U10, U12 | 2 | 74LVC2G06 | SMD SOT-23-6 | TSOP-6_1.65x3.05mm_P0.95mm | Texas Instruments | SN74LVC2G06DBVR | 296-13492-1-ND | https://www.digikey.no/no/products/result?keywords=296-13492-1-ND | 25644 | 3.46 | 6.91 |  | Open-drain inverters. U10: IOCHRDY + MIDI out (as v1.2). U12: Waveblaster /RESET + MIDI (new).
U11 | 1 | NE5532 | SMD SOIC-8 | SOIC-8_3.9x4.9mm_P1.27mm | Texas Instruments | NE5532DR | 296-13622-1-ND | https://www.digikey.no/no/products/result?keywords=296-13622-1-ND | 50117 | 4.80 | 4.80 |  | WT/PCM summing amplifier on the (filtered) ISA +/-12 V.
D1 | 1 | B5819W | SMD SOD-123 | D_SOD-123 | Slkor (Shenzhen Slkormicro) | B5819W | 5399-B5819WCT-ND | https://www.digikey.no/no/products/result?keywords=5399-B5819WCT-ND | 67294 | 2.69 | 2.69 |  | 40 V 1 A Schottky, SOD-123 (cut tape; 5399-B5819WTR-ND is a 3000-pc reel). Replaces MCC B5819W-TP (purchase-limited at DigiKey); Comchip CDBW140-G (641-1458-1-ND) also fits. JLCPCB assembly keeps B5819W (LCSC C84354).
C1, C2 | 2 | 47uF | SMD 1206 | C_1206_3216Metric | TDK | C3216X5R1A476M160AB | 445-6006-1-ND | https://www.digikey.no/no/products/result?keywords=445-6006-1-ND | 33669 | 7.97 | 15.93 | v1.2 Samsung CL31A476MPHNNNE (0 at DigiKey today).
C3, C4, C5, C6, C7, C8, C9, C11, C12, C13, C14, C18, C21, C25, C26, C27, C28, C29 | 18 | 0.1uF | SMD 0805 | C_0805_2012Metric | Samsung | CL21B104KBCNNNC | 1276-1003-1-ND | https://www.digikey.no/no/products/result?keywords=1276-1003-1-ND | 4889645 | 0.43 | 7.77 |  | 50V X7R.
C10 | 1 | 1uF | SMD 0805 | C_0805_2012Metric | TDK | C2012X7R1H105K125AB | 445-7547-1-ND | https://www.digikey.no/no/products/result?keywords=445-7547-1-ND | 7594 | 2.88 | 2.88 |  | 50V X7R.
C15, C24 | 2 | 10uF | SMD 1206 | C_1206_3216Metric | Samsung | CL31A106KAHNNNE | 1276-1075-1-ND | https://www.digikey.no/no/products/result?keywords=1276-1075-1-ND | 18634 | 2.11 | 4.22 | TDK C3216X5R1E106K160AB (DK 445-6862-1-ND, 43950). | 25V X5R. 1206 because no 10uF 0805 is in stock at DigiKey today.
C16, C17 | 2 | 2.2uF | SMD 0805 | C_0805_2012Metric | TDK | C2012X7R1H225K125AC | 445-5968-1-ND | https://www.digikey.no/no/products/result?keywords=445-5968-1-ND | 499706 | 5.09 | 10.17 |  | 50V X7R.
C19, C20 | 2 | 2.2nF C0G | SMD 0805 | C_0805_2012Metric | Samsung | CL21C222JBFNNNE | 1276-2993-1-ND | https://www.digikey.no/no/products/result?keywords=1276-2993-1-ND | 51757 | 1.34 | 2.69 |  | C0G/NP0 (DAC output filter). DAC AREA: leave out with the GY-PCM5102 module (J10).
C30, C31 | 2 | 47pF C0G | SMD 0805 | C_0805_2012Metric | Samsung | CL21C470JC61PNC | 1276-6521-1-ND | https://www.digikey.no/no/products/result?keywords=1276-6521-1-ND | 67127 | 1.70 | 3.40 |  | C0G/NP0 (op-amp feedback), 100 V. Previous value: 100pF C0G (Samsung CL21C101JBANNNC). 47 pF with the 20k feedback puts the feedback pole at ~170 kHz (10k || 100 pF was ~160 kHz). JLCPCB/LCSC: C14857 (CL21C470JBANNNC, 50 V; DigiKey does not stock it). Stock checked 2026-10-09.
C22, C23 | 2 | 10uF bipolar | SMD 6.3x5.4 | CP_Elec_6.3x5.4 | Panasonic | EEE-1EA100NP | PCE4294CT-ND | https://www.digikey.no/no/products/result?keywords=PCE4294CT-ND | 6070 | 6.05 | 12.09 | Nichicon UUP1V100MCL1GS (bipolar 35V, DK 493-9559-1-ND, 3792). | WT audio coupling: NON-POLAR electrolytic (either orientation). The footprint shows a + mark only because KiCad has no non-polar SMD electrolytic footprint.
C32, C33 | 2 | 47uF 35V | SMD 6.3x7.7 | CP_Elec_6.3x7.7 | Panasonic | EEE-FK1V470P | PCE3842CT-ND | https://www.digikey.no/no/products/result?keywords=PCE3842CT-ND | 47922 | 6.24 | 12.48 |  | Op-amp +/-12 V RC filter. C33: + to GND.
FB1, FB2, FB3 | 3 | 1k@100MHz | SMD 0805 | L_0805_2012Metric | Murata | BLM21AG102SN1D | 490-1041-1-ND | https://www.digikey.no/no/products/result?keywords=490-1041-1-ND | 621156 | 1.54 | 4.61 |  | FB1/FB2: MIDI out EMI. FB3: DAC AVDD filter.
R1 | 1 | 1k | SMD 0805 | R_0805_2012Metric | Yageo | RC0805FR-071KL | 311-1.00KCRCT-ND | https://www.digikey.no/no/products/result?keywords=311-1.00KCRCT-ND | 732526 | 0.96 | 0.96
R2, R5, R6 | 3 | 15k | SMD 0805 | R_0805_2012Metric | Yageo | RC0805FR-0715KL | 311-15.0KCRCT-ND | https://www.digikey.no/no/products/result?keywords=311-15.0KCRCT-ND | 127426 | 0.96 | 2.88
R3, R4 | 2 | 220R | SMD 0805 | R_0805_2012Metric | Yageo | RC0805FR-07220RL | 311-220CRCT-ND | https://www.digikey.no/no/products/result?keywords=311-220CRCT-ND | 420320 | 0.96 | 1.92
R7, R8 | 2 | 470R 0.1% thin film | SMD 0805 | R_0805_2012Metric | Yageo | RT0805BRD07470RL | YAG1904CT-ND | https://www.digikey.no/no/products/result?keywords=YAG1904CT-ND | 12924 | 1.06 | 2.11 |  | Thin film in the audio path (lower noise and voltage coefficient than thick film). DAC output filter: leave out with the GY-PCM5102 module (J10), which has the same filter.
R12, R13 | 2 | 10k 0.1% thin film | SMD 0805 | R_0805_2012Metric | Yageo | RT0805BRD0710KL | YAG1763CT-ND | https://www.digikey.no/no/products/result?keywords=YAG1763CT-ND | 176155 | 0.96 | 1.92 |  | Mixer WT inputs: thin film, 0.1% keeps the L/R gains matched. Until 2026-10-09 this line also held R10, R11, R19, R20 (6 pcs); those are now 20k.
R10, R11, R19, R20 | 4 | 20k 0.1% thin film | SMD 0805 | R_0805_2012Metric | Yageo | RT0805BRD0720KL | YAG1823CT-ND | https://www.digikey.no/no/products/result?keywords=YAG1823CT-ND | 24509 | 1.04 | 4.16 |  | Mixer PCM input/feedback: thin film, 0.1%. Previous value: 10k 0.1% (RT0805BRD0710KL). Mixer gain change 2026-10-09: R10/R11 (PCM in) and R19/R20 (feedback) 10k -> 20k gives the Waveblaster path 2x (+6 dB) gain at RV1 max; PCM gain essentially unchanged (-0.4 dB -> -0.2 dB). Stock checked 2026-10-09.
R9, R16 | 2 | 10k | SMD 0805 | R_0805_2012Metric | Yageo | RC0805FR-0710KL | 311-10.0KCRCT-ND | https://www.digikey.no/no/products/result?keywords=311-10.0KCRCT-ND | 2120333 | 0.96 | 1.92
R14, R15 | 2 | 100k | SMD 0805 | R_0805_2012Metric | Yageo | RC0805FR-07100KL | 311-100KCRCT-ND | https://www.digikey.no/no/products/result?keywords=311-100KCRCT-ND | 1068493 | 1.06 | 2.11
R21, R22 | 2 | 100R | SMD 0805 | R_0805_2012Metric | Yageo | RC0805FR-07100RL | 311-100CRCT-ND | https://www.digikey.no/no/products/result?keywords=311-100CRCT-ND | 1562462 | 0.96 | 1.92
R23, R24 | 2 | 10R | SMD 0805 | R_0805_2012Metric | Yageo | RC0805FR-0710RL | 311-10.0CRCT-ND | https://www.digikey.no/no/products/result?keywords=311-10.0CRCT-ND | 614659 | 1.15 | 2.30 |  | Op-amp +/-12 V RC filter (with C32/C33).
RV1 | 1 | 10k dual log | THT | Potentiometer_Alps_RK097_Dual_Horizontal_Switch | Bourns | PTD902-2020K-A103 | PTD902-2020K-A103-ND | https://www.digikey.no/no/products/result?keywords=PTD902-2020K-A103-ND | 426 | 24.45 | 24.45 | Alps RK09712200HA (DK 4809-RK09712200HA-ND 210, 45.45 kr; the part the footprint was drawn for). Alps RK0971221Z0X (same pot + switch, switch unused; DK 4809-RK0971221Z0X-ND 276). | 9 mm dual-gang 10k LOG, right angle, M7 bushing 7 mm, 20 mm shaft through the ISA bracket. Same 2.5 mm 2x3 pin grid as the Alps RK097 footprint; +-20 %, +-3 dB tracking. Test-fit one in the bracket before a large order. Alps stock is low and Alps NA has issued a discontinuation notice for parts of the RK097 range.
J1 | 1 | 2x9 header | THT | PinHeader_2x09_P2.54mm_Vertical | Amphenol | 10129381-918001BLF | 609-10129381-918001BLF-ND | https://www.digikey.no/no/products/result?keywords=609-10129381-918001BLF-ND | 8940 | 11.71 | 11.71
(jumpers) | 4 | 2.54mm jumper shunt | THT |  | Harwin | M7582-05 | 952-2881-ND | https://www.digikey.no/no/products/result?keywords=952-2881-ND |  | 1.52 | 6.08 | Blue: Harwin M7583-05 (DK 952-2882-ND). Red: Harwin M7581-05 (DK 952-2169-ND). Same open-top 2.54 mm shunt. | Black, open top. 3 for J1 (IRQ, DRQ, DACK), 1 for J7 (only for USB host devices).
J6, J7 | 2 | 1x40 breakaway header | THT | PinHeader_1x02_P2.54mm_Vertical | Sullins | PREC040SAAN-RC | S1012EC-40-ND | https://www.digikey.no/no/products/result?keywords=S1012EC-40-ND | 26032 | 4.70 | 9.41 |  | Cut 2x 1x20 for the Pico if it is not soldered directly (castellated), and 2x 1x2 for J6/J7.
J5 | 1 | SJ1-3535NG (black) | THT | Jack_3.5mm_CUI_SJ1-3535NG_Horizontal | Same Sky (CUI) | SJ1-3535NG | CP1-3535NG-ND | https://www.digikey.no/no/products/result?keywords=CP1-3535NG-ND | 27525 | 15.55 | 15.55 | Genuine CUI at LCSC C4991610 (56). The green C692438 (4990) also works - colour is cosmetic. | XKB PJ-325C5: TN pin sits ~0.4 mm further out (unused here) - clip it if it does not fit. Do NOT use C2910528 (different pinout; it is in the v1.2 JLCPCB project).
J8 | 1 | SJ1-3535NG-GR (green) | THT | Jack_3.5mm_CUI_SJ1-3535NG_Horizontal | Same Sky (CUI) | SJ1-3535NG-GR | CP1-3535NG-GR-ND | https://www.digikey.no/no/products/result?keywords=CP1-3535NG-GR-ND | 6323 | 17.08 | 17.08 |  | See J5 note about the TN pin.
J9 | 1 | Waveblaster 2x13 male | THT | Wavetable | Sullins | PEC13DAAN | 35-PEC13DAAN-ND | https://www.digikey.no/no/products/result?keywords=35-PEC13DAAN-ND | 439 | 12.86 | 12.86 |  | Unshrouded 2x13 male pin header; the daughterboard has the female socket.
(DB-standoff) | 1 | M3 x 11 mm F-F standoff | Hardware |  | Wurth | 970110321 | 732-10550-ND | https://www.digikey.no/no/products/result?keywords=732-10550-ND | 23866 | 3.07 | 3.07 |  | Supports the far corner of the daughterboard (J9 footprint hole).
(DB-screws) | 2 | M3 x 6 mm pan head screw | Hardware |  | Keystone | 29311 | 36-29311-ND | https://www.digikey.no/no/products/result?keywords=36-29311-ND | 14850 | 4.51 | 9.02
J3 | 0 | Bus_ISA_8bit | not fitted | BUS_PC_chamfer |  |  |  |  |  |  |  |  | ISA card edge (PCB gold fingers, order with chamfered/bevelled edge)
H1 | 0 | MountingHole_3.2mm_M3_Pad | not fitted | MountingHole_3.2mm_M3_Pad |  |  |  |  |  |  |  |  | Bracket mounting hole
H2 | 0 | MountingHole_3.2mm_M3_Pad | not fitted | MountingHole_3.2mm_M3_Pad |  |  |  |  |  |  |  |  | Bracket mounting hole

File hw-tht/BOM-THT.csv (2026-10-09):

References | Qty | Value | Type | Footprint | Manufacturer | MPN (DigiKey line) | DigiKey PN | DigiKey link | DigiKey stock 2026-09-28 | LCSC PN [MPN if different] | LCSC stock 2026-09-28 | Alternatives | Notes
U1 | 1 | Raspberry Pi Pico | THT module | RPi_Pico_SMD_TH | Raspberry Pi | SC0915 | 2648-SC0915CT-ND | https://www.digikey.no/no/products/result?keywords=2648-SC0915CT-ND | 42851 | C7203002 | n/a (JLCPCB library only) | Pico H SC0917 (DK 2648-SC0917-ND, 8889; JLCPCB lib C21351132). Pico W also works. | LCSC: Pico is only in the JLCPCB assembly parts library, not the LCSC shop - buy from DigiKey or an approved Raspberry Pi reseller. Solder on 2x 1x20 male headers (from the 1x40 strip) or socket it.
(U1-socket) | 2 | 1x20 female header x2 | THT (optional) |  | Sullins | PPTC201LFBN-RC | S7018-ND | https://www.digikey.no/no/products/result?keywords=S7018-ND | 16735 | C2897383 [HCTL PM254-1-20-Z-8.5] | 4775 |  | Only if you want the Pico socketed.
U2 | 1 | 74AHC244 | THT DIP-20 | DIP-20_W7.62mm | Texas Instruments | SN74AHC244N | 296-4585-5-ND | https://www.digikey.no/no/products/result?keywords=296-4585-5-ND | 982 | C1548228 | 0 | Rochester 2156-SN74AHC244N-ND (9380). | 3V3 supply, inputs must be 5V tolerant: AHC only (never HC/HCT). LCSC stocks this DIP rarely (checked 2026-09-28) - order it from DigiKey.
U3, U4 | 2 | SN74CB3T3257 | SMD only | TSSOP-16_4.4x5mm_P0.65mm | Texas Instruments | SN74CB3T3257PWR | 296-17850-1-ND | https://www.digikey.no/no/products/result?keywords=296-17850-1-ND | 4031 | C544573 | 6022 |  | TSSOP-16. No DIP or SOIC version exists (only PW/DGV).
U5 | 1 | 74AHC14 | THT DIP-14 | DIP-14_W7.62mm | Texas Instruments | SN74AHC14N | 296-4550-5-ND | https://www.digikey.no/no/products/result?keywords=296-4550-5-ND | 6716 | C2879116 | 0 |  | Must be 74AHC14 (higher Schmitt threshold, see v1.2 changelog), not LVC/HC. LCSC stocks this DIP rarely (checked 2026-09-28) - order it from DigiKey.
U6, U7 | 2 | 74AHC00 | THT DIP-14 | DIP-14_W7.62mm | Texas Instruments | SN74AHC00N | 296-4510-5-ND | https://www.digikey.no/no/products/result?keywords=296-4510-5-ND | 1979 | C2879122 | 74 | Rochester 2156-SN74AHC00N-ND (21358). | 3V3 supply, 5V-tolerant inputs: AHC only. LCSC stocks this DIP rarely (checked 2026-09-28) - order it from DigiKey.
U8 | 1 | APS6404L-3SQR-SN | SMD only | SOIC-8_3.9x4.9mm_P1.27mm | AP Memory | APS6404L-3SQR-SN | 1528-4677-ND [Adafruit 4677 (64Mbit QSPI PSRAM)] | https://www.digikey.no/no/products/result?keywords=1528-4677-ND | 4132 | C5333729 | 4772 |  | SOIC-8. DigiKey does not stock the APS6404L itself; Adafruit 4677 is the DigiKey source (as in v1.2). Note: v1.2 BOM LCSC C139966 is actually a Vilsion VTI7064MSME (compatible).
U9 | 1 | PCM5100A | SMD only | TSSOP-20_4.4x6.5mm_P0.65mm | Texas Instruments | PCM5100APWR | 296-36705-1-ND | https://www.digikey.no/no/products/result?keywords=296-36705-1-ND | 1419 | C131154 | 2156 | Pin-compatible PCM5102APWR (DK 296-36707-1-ND 619, LCSC C107671 6471) or PCM5101APWR. | TSSOP-20, no THT version exists. DAC AREA: leave out U9, C12-C20, FB3, R7 and R8 when the GY-PCM5102 module (J10) is fitted instead.
J10 | 1 | GY-PCM5102 module | THT (optional, instead of the DAC area) | GY-PCM5102_Module | generic | GY-PCM5102 |  |  |  |  |  |  | OPTION: replaces U9 + C12-C20 + FB3 + R7/R8 - exactly the parts under the dashed J10 module outline (the module has the same 470R/2.2nF output filter). Fit ONE of the two, never both. Not sold by DigiKey (AliExpress/eBay etc). Solder it almost flat, directly on 2.54 mm male pins: its 6-pin I2S header and a 4-pin piece of the 1x40 strip on AGND/ROUT/AGND/LROUT. No sockets: raised on 8.5 mm sockets it would hit a Waveblaster daughterboard. Set its solder jumpers H1=L H2=L H3=H H4=L.
U10 | 1 | 74AHCT126 | THT DIP-14 | DIP-14_W7.62mm | Texas Instruments | SN74AHCT126N | 296-4659-5-ND | https://www.digikey.no/no/products/result?keywords=296-4659-5-ND | 995 | C1548378 | 0 | Rochester 2156-SN74AHCT126N-ND (58265). | +5V supply with 3V3 inputs: must be AHCT (inputs tolerate voltage above VCC, so nothing back-powers the 5V rail when the card runs from USB only). Do NOT use HCT/HC/LVC. LCSC stocks this DIP rarely (checked 2026-09-28) - order it from DigiKey.
(DIP14-socket) | 4 | DIP-14 socket | THT (optional) |  | TE Connectivity | 1-2199298-3 | A120348-ND | https://www.digikey.no/no/products/result?keywords=A120348-ND | 31813 | C3034942 | 6392 |  | Optional. Sockets add ~4 mm height under the Waveblaster daughterboard - check clearance.
(DIP20-socket) | 1 | DIP-20 socket | THT (optional) |  | TE Connectivity | 1-2199298-6 | A120351-ND | https://www.digikey.no/no/products/result?keywords=A120351-ND | 7072 | C2328 [BOOMELE IC-20P] | 6132 |  | Optional.
D1 | 1 | 1N5819 | THT | D_DO-41_SOD81_P10.16mm_Horizontal | onsemi | 1N5819RLG | 1N5819RLGOSCT-ND | https://www.digikey.no/no/products/result?keywords=1N5819RLGOSCT-ND | 31215 | C88393 | 7130 | 1N5817-T (DK 1N5817DICT-ND, LCSC C507852).
R3, R4 | 2 | 220R | THT | R_Axial_DIN0207_L6.3mm_D2.5mm_P10.16mm_Horizontal | Stackpole | RNMF14FTC220R | S220CACT-ND | https://www.digikey.no/no/products/result?keywords=S220CACT-ND | 11561 | C3537012 [Yageo MFR-25FBF52-220R] | 26540
R7, R8 | 2 | 470R | THT | R_Axial_DIN0207_L6.3mm_D2.5mm_P10.16mm_Horizontal | Stackpole | RNMF14FTC470R | S470CACT-ND | https://www.digikey.no/no/products/result?keywords=S470CACT-ND | 11554 | C58592 [UNI-ROYAL MFR0W4F4700A50] | 8250 |  | DAC output filter (with C19/C20). DAC AREA: leave out with the GY-PCM5102 module (J10), which has the same filter.
R1 | 1 | 1k | THT | R_Axial_DIN0207_L6.3mm_D2.5mm_P10.16mm_Horizontal | Yageo | MFR-25FBF52-1K | 1.00KXBK-ND | https://www.digikey.no/no/products/result?keywords=1.00KXBK-ND | 82574 | C57435 [UNI-ROYAL MFR0W4F1001A50] | 146700
R9, R12, R13, R16, R17 | 5 | 10k | THT | R_Axial_DIN0207_L6.3mm_D2.5mm_P10.16mm_Horizontal | Yageo | MFR-25FBF52-10K | 10.0KXBK-ND | https://www.digikey.no/no/products/result?keywords=10.0KXBK-ND | 105899 | C1519255 | 18900 |  | Until 2026-10-09 this line also held R10, R11, R19, R20 (9 pcs); those are now 20k.
R10, R11, R19, R20 | 4 | 20k | THT | R_Axial_DIN0207_L6.3mm_D2.5mm_P10.16mm_Horizontal | Yageo | MFR-25FBF52-20K | 20.0KXBK-ND | https://www.digikey.no/no/products/result?keywords=20.0KXBK-ND | 53295 | C1364283 | 27100 |  | Previous value: 10k (MFR-25FBF52-10K). Mixer gain change 2026-10-09: R10/R11 (PCM in) and R19/R20 (feedback) 10k -> 20k gives the Waveblaster path 2x (+6 dB) gain at RV1 max; PCM gain essentially unchanged (-0.4 dB -> -0.2 dB). Stock checked 2026-10-09.
R2, R5, R6 | 3 | 15k | THT | R_Axial_DIN0207_L6.3mm_D2.5mm_P10.16mm_Horizontal | Yageo | MFR-25FBF52-15K | 15.0KXBK-ND | https://www.digikey.no/no/products/result?keywords=15.0KXBK-ND | 26166 | C3556390 | 5100
C3, C4, C5, C6, C7, C8, C9, C11, C12, C13, C14, C18, C21, C25, C26, C27, C28, C29 | 18 | 0.1uF | THT | C_Disc_D5.0mm_W2.5mm_P5.00mm | Murata | RDER71H104K0M1H03A | 490-9144-1-ND | https://www.digikey.no/no/products/result?keywords=490-9144-1-ND | 1302 | C527620 | 9695 |  | 50V X7R radial, 5.0 mm pitch. DigiKey bulk 490-9144-3-ND (14000).
C10 | 1 | 1uF | THT | C_Disc_D5.0mm_W2.5mm_P5.00mm | Murata | RDER71H105K2M1H03A | 490-9146-1-ND | https://www.digikey.no/no/products/result?keywords=490-9146-1-ND | 1279 | C1620132 | 8520 |  | 50V X7R radial, 5.0 mm pitch.
C16, C17 | 2 | 2.2uF | THT | C_Disc_D5.0mm_W2.5mm_P5.00mm | TDK | FG24X7R1H225KRT06 | 445-173378-1-ND | https://www.digikey.no/no/products/result?keywords=445-173378-1-ND | 658 | C1623182 | 1500 |  | 50V X7R radial, 5.0 mm pitch (FG14... is the 2.5 mm version and does NOT fit).
C15, C24 | 2 | 10uF | THT | C_Disc_D5.0mm_W2.5mm_P5.00mm | Murata | RCER71H106MWM1H03A | 490-7518-1-ND | https://www.digikey.no/no/products/result?keywords=490-7518-1-ND | 1740 | C3690252 | 1378 |  | 50V X7R radial MLCC, 5 mm pitch (low profile: C24 sits under the daughterboard).
C19, C20 | 2 | 2.2nF C0G | THT | C_Disc_D5.0mm_W2.5mm_P5.00mm | TDK | FG28C0G1H222JNT06 | 445-173487-1-ND | https://www.digikey.no/no/products/result?keywords=445-173487-1-ND | 1649 | C22391154 [Dersonic CD1H222JC9PECHD000 (5.08 mm pitch)] | 1560 | Vishay K222J15C0GF5TH5 (DK BC1050CT-ND, 1744). | C0G, 5.0 mm pitch. DAC output filter (with R7/R8). DAC AREA: leave out with the GY-PCM5102 module (J10).
C1, C2, C32, C33 | 4 | 47uF | THT | CP_Radial_D5.0mm_P2.00mm | Rubycon | 35YXJ47M5X11 | 1189-2919-ND | https://www.digikey.no/no/products/result?keywords=1189-2919-ND | 2049 | C88761 | 177540 |  | 35V, 5x11 mm, 2.0 mm pitch. C32/C33 = op-amp +/-12 V filter: needs >=25V. C33: + to GND.
C22, C23 | 2 | 10uF bipolar | THT | C_Radial_D6.3mm_H11.0mm_P2.50mm | Panasonic | ECE-A1HN100U | P1280-ND | https://www.digikey.no/no/products/result?keywords=P1280-ND | 7654 | C6029955 [Panasonic ECE-A1HN100UB] | 1790 | Nichicon UES1H100MPM (Muse ES audio bipolar, DK 493-15033-ND, 14516) is 8 mm / 3.5 mm pitch: does not fit. | WT audio coupling: bipolar (non-polar) 50V, 6.3x11 mm, 2.5 mm pitch. The DC across them is undefined (depends on the daughterboard), so a polarised cap could sit reverse-biased.
FB1, FB2, FB3 | 3 | Ferrite bead | THT | R_Axial_DIN0309_L9.0mm_D3.2mm_P12.70mm_Horizontal | Fair-Rite | 2743002112 | 1934-1477-1-ND | https://www.digikey.no/no/products/result?keywords=1934-1477-1-ND | 19974 | C192455 [FH RH3.5x0.8x9P52E (100R@100MHz)] | 50580 | Fair-Rite 2761001112 (DK 1934-1423-1-ND, 33346). A wire link also works (slightly worse EMI / DAC noise). | Axial bead on leads, 12.7 mm hole pitch (the 9 mm long LCSC bead needs it).
RV1 | 1 | 10k dual log | THT | Potentiometer_Alps_RK097_Dual_Horizontal_Switch | Bourns | PTD902-2020K-A103 | PTD902-2020K-A103-ND | https://www.digikey.no/no/products/result?keywords=PTD902-2020K-A103-ND | 426 | C470545 [Alps RK09712200HA] | 175 | Alps RK09712200HA (DK 4809-RK09712200HA-ND 210, LCSC C470545 175; the part the footprint was drawn for, about twice the price). Alps RK0971221Z0X (same pot + switch, switch unused; DK 4809-RK0971221Z0X-ND 276, LCSC C22387186 681). | 9 mm dual-gang 10k LOG, right angle, M7 bushing 7 mm, 20 mm shaft through the ISA bracket. Same 2.5 mm 2x3 pin grid as the Alps RK097 footprint; +-20 %, +-3 dB tracking. Test-fit one in the bracket before a large order. Alps stock is low and Alps NA has issued a discontinuation notice for parts of the RK097 range.
J1 | 1 | 2x9 header | THT | PinHeader_2x09_P2.54mm_Vertical | Amphenol | 10129381-918001BLF | 609-10129381-918001BLF-ND | https://www.digikey.no/no/products/result?keywords=609-10129381-918001BLF-ND | 8940 | C492426 [XFCN PZ254V-12-18P] | 8020
(jumpers) | 4 | 2.54mm jumper shunt | THT |  | Harwin | M7582-05 | 952-2881-ND | https://www.digikey.no/no/products/result?keywords=952-2881-ND |  | C168674 | 28440 | Blue: Harwin M7583-05 (DK 952-2882-ND). Red: Harwin M7581-05 (DK 952-2169-ND). Same open-top 2.54 mm shunt. | Black, open top. 3 for J1 (IRQ, DRQ, DACK), 1 for J7 (only for USB host devices). LCSC C168674 is a generic shunt.
J6, J7 | 2 | 1x40 breakaway header | THT | PinHeader_1x02_P2.54mm_Vertical | Sullins | PREC040SAAN-RC | S1012EC-40-ND | https://www.digikey.no/no/products/result?keywords=S1012EC-40-ND | 26032 | C2337 [BOOMELE 2.54-1*40P] | 87885 |  | Cut 2x 1x20 for the Pico (skip if using a Pico H) and 2x 1x2 for J6/J7.
J5 | 1 | SJ1-3535NG (black) | THT | Jack_3.5mm_CUI_SJ1-3535NG_Horizontal | Same Sky (CUI) | SJ1-3535NG | CP1-3535NG-ND | https://www.digikey.no/no/products/result?keywords=CP1-3535NG-ND | 27525 | C2884945 [XKB PJ-325C5-B] | 115 | Genuine CUI at LCSC C4991610 (56). The green C692438 (4990) also works - colour is cosmetic. | XKB PJ-325C5: TN pin sits ~0.4 mm further out (unused here) - clip it if it does not fit. Do NOT use C2910528 (different pinout; it is in the v1.2 JLCPCB project).
J8 | 1 | SJ1-3535NG-GR (green) | THT | Jack_3.5mm_CUI_SJ1-3535NG_Horizontal | Same Sky (CUI) | SJ1-3535NG-GR | CP1-3535NG-GR-ND | https://www.digikey.no/no/products/result?keywords=CP1-3535NG-GR-ND | 6323 | C692438 [XKB PJ-325C5-G] | 4990 |  | See J5 note about the TN pin.
J9 | 1 | Waveblaster 2x13 male | THT | Wavetable | Sullins | PEC13DAAN | 35-PEC13DAAN-ND | https://www.digikey.no/no/products/result?keywords=35-PEC13DAAN-ND | 439 | C2894974 [HCTL PZ254-2-13-Z-8.5] | 3945 |  | Unshrouded 2x13 male pin header; the daughterboard has the female socket.
(DB-standoff) | 1 | M3 x 11 mm F-F standoff | Hardware |  | Wurth | 970110321 | 732-10550-ND | https://www.digikey.no/no/products/result?keywords=732-10550-ND | 23866 | C551331 [Shuntian M3*11] | 5000 |  | Supports the far corner of the daughterboard (J9 footprint hole).
(DB-screws) | 2 | M3 x 6 mm pan head screw | Hardware |  | Keystone | 29311 | 36-29311-ND | https://www.digikey.no/no/products/result?keywords=36-29311-ND | 14850 | C357543 [Shuntian PM3X6] | 29900
U11 | 1 | NE5532 | THT DIP-8 | DIP-8_W7.62mm | Texas Instruments | NE5532P | 296-1410-5-ND | https://www.digikey.no/no/products/result?keywords=296-1410-5-ND | 12687 | C5326 | 6175 | NE5532AP (DK 296-7040-5-ND, LCSC C353150). Other unity-gain-stable dual audio op-amps on +/-12 V work (e.g. TL072CP: LCSC C7236, DigiKey stock 0 today). | WT/PCM summing amplifier, powered from ISA +/-12 V. A DIP-8 socket is fine here (outside the DB area).
R14, R15, R18 | 3 | 100k | THT | R_Axial_DIN0207_L6.3mm_D2.5mm_P10.16mm_Horizontal | Yageo | MFR-25FBF52-100K | 100KXBK-ND | https://www.digikey.no/no/products/result?keywords=100KXBK-ND | 41215 | C1364475 | 11650
R23, R24 | 2 | 10R | THT | R_Axial_DIN0207_L6.3mm_D2.5mm_P10.16mm_Horizontal | Yageo | MFR-25FBF52-10R | 10.0XBK-ND | https://www.digikey.no/no/products/result?keywords=10.0XBK-ND | 29755 | C119282 [CCO MF1/4W-10R 1%] | 12550 |  | Op-amp +/-12 V RC filter (with C32/C33).
R21, R22 | 2 | 100R | THT | R_Axial_DIN0207_L6.3mm_D2.5mm_P10.16mm_Horizontal | Yageo | MFR-25FBF52-100R | 100XBK-ND | https://www.digikey.no/no/products/result?keywords=100XBK-ND | 79374 | C6300650 | 9300
C30, C31 | 2 | 47pF C0G | THT | C_Disc_D5.0mm_W2.5mm_P5.00mm | Vishay | K470J15C0GF5TH5 | BC1038CT-ND | https://www.digikey.no/no/products/result?keywords=BC1038CT-ND | 15168 | C3690607 | 1570 | TDK FG28C0G1H470JNT06 (DK 445-173499-1-ND); LCSC C123159 (TORCH CC4-0805-CG-50V-47pF-J, 5.08 mm pitch). | Previous value: 100pF C0G (Vishay K101J15C0GF5TH5). 47 pF with the 20k feedback puts the feedback pole at ~170 kHz (10k || 100 pF was ~160 kHz; flat to 20 kHz as before). C0G, 5.0 mm pitch. Stock checked 2026-10-09.
J3 | 0 | Bus_ISA_8bit | not fitted | BUS_PC_chamfer |  |  |  |  |  |  |  |  | ISA card edge (PCB gold fingers, order with chamfered/bevelled edge)
H1 | 0 | MountingHole_3.2mm_M3_Pad | not fitted | MountingHole_3.2mm_M3_Pad |  |  |  |  |  |  |  |  | Bracket mounting hole
H2 | 0 | MountingHole_3.2mm_M3_Pad | not fitted | MountingHole_3.2mm_M3_Pad |  |  |  |  |  |  |  |  | Bracket mounting hole

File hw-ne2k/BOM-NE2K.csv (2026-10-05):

References | Qty | Value | Type | Footprint | Manufacturer | MPN | DigiKey PN | DigiKey link | DigiKey stock | Unit NOK (1 board) | Line NOK (1 board) | Alternatives | Notes
U1 | 1 | Raspberry Pi Pico W | module (solder flat) | RPi_PicoW_SMD_TH_USB | Raspberry Pi | SC0918 | 2648-SC0918CT-ND | https://www.digikey.no/no/products/result?keywords=2648-SC0918CT-ND | 6986 | 72.90 | 72.90 | Pico 2 W does NOT work (the NE2000 firmware is RP2040-only). Pico WH (pre-soldered headers) cannot be soldered flat. | Pico W (RP2040 + CYW43439 WiFi). Solder it FLAT (castellated edge or pins cut flush) so TP1-TP3 (USB) can be soldered from the back. Antenna end toward the bracket.
U2 | 1 | 74LVC244 | SMD TSSOP-20 | TSSOP-20_4.4x6.5mm_P0.65mm | Texas Instruments | SN74LVC244APW | 296-26609-5-ND | https://www.digikey.no/no/products/result?keywords=296-26609-5-ND | 2154 | 11.61 | 11.61 | Nexperia 74LVC244APW,118 (v1.2 BOM, DK 1727-2875-1-ND, 0 in stock today). | Octal buffer, 3V3, 5V-tolerant inputs
U3, U4 | 2 | SN74CB3T3257 | SMD TSSOP-16 | TSSOP-16_4.4x5mm_P0.65mm | Texas Instruments | SN74CB3T3257PWR | 296-17850-1-ND | https://www.digikey.no/no/products/result?keywords=296-17850-1-ND | 4031 | 19.96 | 39.92 |  | TSSOP-16. No DIP or SOIC version exists (only PW/DGV).
U5 | 1 | 74AHC14 | SMD SOIC-14 | SOIC-14_3.9x8.7mm_P1.27mm | Diodes Inc | 74AHC14S14-13 | 31-74AHC14S14-13CT-ND | https://www.digikey.no/no/products/result?keywords=31-74AHC14S14-13CT-ND | 3070 | 3.55 | 3.55 |  | Must be 74AHC14 (higher Schmitt threshold, see v1.2 changelog).
U6 | 1 | 74LVC00 | SMD SOIC-14 | SOIC-14_3.9x8.7mm_P1.27mm | Diodes Inc | 74LVC00AS14-13 | 31-74LVC00AS14-13CT-ND | https://www.digikey.no/no/products/result?keywords=31-74LVC00AS14-13CT-ND | 1816 | 3.65 | 3.65 |  | Quad NAND, 3V3
U7 | 1 | 74LVC1G00 | SMD SOT-23-5 | SOT-23-5 | Texas Instruments | SN74LVC1G00DBVR | 296-9845-1-ND | https://www.digikey.no/no/products/result?keywords=296-9845-1-ND | 14500 | 1.34 | 1.34 |  | Quad NAND, 3V3
U8 | 1 | APS6404L-3SQR-SN | SMD SOIC-8 | SOIC-8_3.9x4.9mm_P1.27mm | AP Memory | APS6404L-3SQR-SN | 1528-4677-ND | https://www.digikey.no/no/products/result?keywords=1528-4677-ND | 4132 | 16.80 | 16.80 |  | SOIC-8. DigiKey does not stock the APS6404L itself; Adafruit 4677 is the DigiKey source (as in v1.2). Note: v1.2 BOM LCS
U10 | 1 | 74LVC2G06 | SMD TSOP-6 | TSOP-6_1.65x3.05mm_P0.95mm | Texas Instruments | SN74LVC2G06DBVR | 296-13492-1-ND | https://www.digikey.no/no/products/result?keywords=296-13492-1-ND | 25644 | 3.46 | 3.46 |  | Open-drain inverters. U10A: IOCHRDY. U10B: unused (input driven by U5A, output open).
U13 | 1 | SST39SF010A | SMD PLCC-32 | PLCC-32_11.4x14.0mm_P1.27mm | Microchip | SST39SF010A-70-4C-NHE | SST39SF010A-70-4C-NHE-ND | https://www.digikey.no/no/products/result?keywords=SST39SF010A-70-4C-NHE-ND | 4137 | 18.87 | 18.87 |  | Boot ROM: 128 KB 5 V flash = 4 banks of 32 KB, in-system writable from DOS (J2 fitted)
U14 | 1 | 74HCT688 | SMD SOIC-20W | SOIC-20W_7.5x12.8mm_P1.27mm | Texas Instruments | CD74HCT688M96 | 296-24357-1-ND | https://www.digikey.no/no/products/result?keywords=296-24357-1-ND | 9672 | 7.43 | 7.43 |  | Boot ROM address decoder (SA15-SA19 vs Pico-set base, enable)
U15 | 1 | 74AHCT245 | SMD TSSOP-20 | TSSOP-20_4.4x6.5mm_P0.65mm | Texas Instruments | SN74AHCT245PWR | 296-1118-1-ND | https://www.digikey.no/no/products/result?keywords=296-1118-1-ND | 17137 | 7.72 | 7.72 |  | Boot ROM data buffer onto the ISA bus
U16 | 1 | 74AHCT1G08 | SMD SOT-23-5 | SOT-23-5 | Texas Instruments | SN74AHCT1G08DBVR | 296-1113-1-ND | https://www.digikey.no/no/products/result?keywords=296-1113-1-ND | 66802 | 1.52 | 1.52 |  | ~MEMSTB = ~SMEMR AND ~SMEMW (low during any memory cycle)
U17 | 1 | USBLC6-2SC6 | SMD SOT-23-6 | SOT-23-6 | STMicroelectronics | USBLC6-2SC6 | 497-5235-1-ND | https://www.digikey.no/no/products/result?keywords=497-5235-1-ND | 144111 | 5.15 | 5.15 |  | USB ESD protection
D1 | 1 | B5819W | SMD SOD-123 | D_SOD-123 | Slkor | B5819W | 5399-B5819WCT-ND | https://www.digikey.no/no/products/result?keywords=5399-B5819WCT-ND | 67294 | 2.69 | 2.69 |  | 1A 40V Schottky, DO-41
F1 | 1 | 500mA PTC | SMD 1206 | Fuse_1206_3216Metric | Bourns | MF-NSMF050-2 | MF-NSMF050-2CT-ND | https://www.digikey.no/no/products/result?keywords=MF-NSMF050-2CT-ND | 30039 | 3.81 | 3.81 |  | USB VBUS polyfuse, 0.5 A hold
C1, C2 | 2 | 47uF | SMD 1206 | C_1206_3216Metric | TDK | C3216X5R1A476M160AB | 445-6006-1-ND | https://www.digikey.no/no/products/result?keywords=445-6006-1-ND | 33669 | 7.97 | 15.94 | v1.2 Samsung CL31A476MPHNNNE (0 at DigiKey today). | 47uF 35V aluminium electrolytic, 5mm dia, 2mm pitch
C3, C4, C5, C6, C7, C8, C9, C11, C12, C13, C14, C15, C17 | 13 | 0.1uF | SMD 0805 | C_0805_2012Metric | Samsung | CL21B104KBCNNNC | 1276-1003-1-ND | https://www.digikey.no/no/products/result?keywords=1276-1003-1-ND | 4889645 | 0.43 | 5.59 |  | 50V X7R.
C10 | 1 | 1uF | SMD 0805 | C_0805_2012Metric | TDK | C2012X7R1H105K125AB | 445-7547-1-ND | https://www.digikey.no/no/products/result?keywords=445-7547-1-ND | 7594 | 2.88 | 2.88 |  | 50V X7R.
C16 | 1 | 10uF | SMD 1206 | C_1206_3216Metric | Samsung | CL31A106KAHNNNE | 1276-1075-1-ND | https://www.digikey.no/no/products/result?keywords=1276-1075-1-ND | 18634 | 2.11 | 2.11 | TDK C3216X5R1E106K160AB (DK 445-6862-1-ND, 43950). | USB VBUS bulk. 25V X5R. 1206 because no 10uF 0805 is in stock at DigiKey today.
R1 | 1 | 1k | SMD 0805 | R_0805_2012Metric | Yageo | RC0805FR-071KL | 311-1.00KCRCT-ND | https://www.digikey.no/no/products/result?keywords=311-1.00KCRCT-ND | 732526 | 0.96 | 0.96 |  | 1k 1/4W 1% metal film
R2, R5, R6 | 3 | 15k | SMD 0805 | R_0805_2012Metric | Yageo | RC0805FR-0715KL | 311-15.0KCRCT-ND | https://www.digikey.no/no/products/result?keywords=311-15.0KCRCT-ND | 127426 | 0.96 | 2.88 |  | 15k 1/4W 1% metal film
R3, R4 | 2 | 10k | SMD 0805 | R_0805_2012Metric | Yageo | RC0805FR-0710KL | 311-10.0KCRCT-ND | https://www.digikey.no/no/products/result?keywords=311-10.0KCRCT-ND | 2120333 | 0.96 | 1.92 |  | 10k 1/4W 1% metal film
J1 | 1 | 2x5 header | THT | PinHeader_2x05_P2.54mm_Vertical | Amphenol | 10129381-910001BLF | 10129381-910001BLF-ND | https://www.digikey.no/no/products/result?keywords=10129381-910001BLF-ND | 8685 | 6.96 | 6.96 |  | IRQ select: one jumper (IRQ 2/9, 3, 4, 5 or 7)
J2, J6 | 2 | 1x2 header | THT | PinHeader_1x02_P2.54mm_Vertical | Amphenol | 77311-118-02LF | 609-4434-ND | https://www.digikey.no/no/products/result?keywords=609-4434-ND | 56935 | 1.72 | 3.43 |  | J2: boot ROM write enable (fit the jumper only while flashing). J6: debug UART TX + GND. 30 uin gold.
J5 | 1 | USB-A | THT | USB_A_Molex_67643_Horizontal | Molex | 0676432910 | WM11258-ND | https://www.digikey.no/no/products/result?keywords=WM11258-ND | 894 | 18.20 | 18.20 | Wurth 614004134726 (DK 732-2731-ND, different footprint). | USB host port (mouse/joystick/storage), at the bracket below the antenna
(jumpers) | 2 | 2.54mm jumper shunt | THT |  | Harwin | M7582-05 | 952-2881-ND | https://www.digikey.no/no/products/result?keywords=952-2881-ND |  | 1.52 | 3.04 | Blue: Harwin M7583-05 (DK 952-2882-ND). Red: Harwin M7581-05 (DK 952-2169-ND). Same open-top 2.54 mm shunt. | One for J1 (IRQ), one for J2 (boot-ROM write enable: fit only while flashing the ROM).
J3 | 0 |  | not fitted |  |  |  |  |  |  |  |  |  | ISA card edge (PCB gold fingers, order with chamfered/bevelled edge)
H1 | 0 |  | not fitted |  |  |  |  |  |  |  |  |  | Bracket mounting hole
H2 | 0 |  | not fitted |  |  |  |  |  |  |  |  |  | Bracket mounting hole

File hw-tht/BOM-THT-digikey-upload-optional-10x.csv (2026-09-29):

Quantity | Digi-Key Part Number | Manufacturer Part Number | Customer Reference
20 | S7018-ND | PPTC201LFBN-RC | Pico sockets U1
40 | A120348-ND | 1-2199298-3 | DIP14 sockets
10 | A120351-ND | 1-2199298-6 | DIP20 socket U2

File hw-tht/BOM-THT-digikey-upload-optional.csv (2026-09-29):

Quantity | Digi-Key Part Number | Manufacturer Part Number | Customer Reference
2 | S7018-ND | PPTC201LFBN-RC | Pico sockets U1
4 | A120348-ND | 1-2199298-3 | DIP14 sockets
1 | A120351-ND | 1-2199298-6 | DIP20 socket U2

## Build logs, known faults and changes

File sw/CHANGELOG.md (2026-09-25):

# Unreleased

## New features

### PGDFS: the USB drive as a DOS drive letter (all modes with the USB stack)

- The USB drive plugged into the PicoGUS can now be mapped to a DOS drive letter with the new `PGUSDFS.EXE` TSR, in the same spirit as PicoMEM's PMDFS: `PGUSDFS E:` gives you `E:` backed by the FAT32 drive, with read and write access, from plain DOS 5.0+. Copy files to and from the drive, run programs from it, edit files on it, in any firmware mode that carries the USB host stack (GUS, AdLib, SB, MPU-401, PSG, USB). CD-ROM emulation keeps working alongside it; both share the card's FatFs volume.
- PGDFS is a DOS network redirector derived from [EtherDFS](https://mateusz.fr/etherdfs/) (MIT) and speaks the same EDF5 request format, so the card-side server is the ethersrv code on FatFs. The transport is new: request/answer frames stream through a two-port I/O data window with 16-bit transfers (`rep insw`/`rep outsw`: the motherboard splits each word into two 8-bit cycles for the card, so this roughly halves the CPU cost per byte), driven by eight new control-port registers (see `sw/dfs/PROTOCOL.md`). `DFSDIAG.EXE` exercises the transport and protocol for diagnostics and throughput measurement.
- The data window base is configurable like the other emulated devices' ports: `pgusinit /dfsport <port>` (even; default 1D4h; 0 disables PGDFS), stored with `pgusinit /save`.
- Long file names: the DOS redirector interface is 8.3-only, so files with long names show up as `LONGNA~1.EXT`, but the new `LONGNAME` lookup returns the long name behind an 8.3 path and `DFSDIAG /LDIR` lists a directory with long names. The OEM code page used for file names is a firmware build option, `-DFATFS_CODE_PAGE=<n>` (437 US by default; 850 Western Europe, 865 Nordic, ...), for drives written on non-US Windows machines.
- The control-port protocol version is now 5. `pgusinit` shows the mounted USB drive (label, filesystem, size) in its status output.
- Diagnostics: the new `DIAG` request returns the card's disk and FatFs telemetry (USB read/write counters, refused, failed and timed-out transfers, the last SCSI status, the last failing FatFs call and the free-cluster count FatFs is working with). `DFSDIAG /INFO` prints it and `DFSDIAG` prints it after any failed command; `DFSDIAG /WRTEST` and `/MKDIR` reproduce a write round trip without the TSR. A failing sector transfer underneath a mounted drive is now reported to DOS as a write fault (1Dh) or read fault (1Eh) instead of "drive not ready" (15h). FatFs no longer trusts the FAT32 FSInfo free count written by other operating systems (`FF_FS_NOFSINFO`), a stale count of which makes every allocation fail with "Access denied"; the FAT is counted on the first free-space query after a mount instead.
- Firmware built with `-DPGDFS=OFF` omits all of this and keeps the previous behaviour.

### PGBOOT: boot floppy and hard disk images from the USB drive (experimental)

- An option ROM (`PGBOOT.ROM`, in an EEPROM on a ROM card, or loaded by `PGBOOT.COM`) can present a disk image file on the PicoGUS USB drive to the BIOS as floppy drive A: and/or hard disk C:, so the machine boots from it. The card serves the sectors over the PGDFS transport with three new requests (`BDINFO`, `BDREAD`, `BDWRITE`, see `sw/bootdisk/PROTOCOL.md`), in every firmware mode that carries PGDFS.
- Raw images and fixed VHD files are supported. Floppy geometry comes from the image size (160K to 2.88M, DMF 1.68M/1.72M) or its DOS boot sector; hard disk geometry from the VHD footer, the partition table, the boot sector, or 16 heads / 63 sectors. Images are kept open with a FatFs fast seek map (a hard disk image too fragmented for it is refused with a message to copy it to a freshly formatted stick), and written sectors reach the USB drive before the write is acknowledged.
- Safety: after the card boots (mode switch, firmware update) it opens no image until the ROM asks at the next boot, and every sector request carries a token that identifies the card boot and the image file, so a running system is never handed a different disk: a swapped floppy is reported as a media change, a hard disk that changed as not ready. Replugging the same USB stick carries on where it was.
- `pgusinit /fdimage <path|->` selects the floppy image (swapped in at once, reported to DOS as a media change), `/hdimage <path|->` the hard disk image (used from the next boot), `/bdopts <0-15>` the options (read-only floppy / hard disk, ROM disabled, boot the hard disk image). They are saved with `/save` (settings version 7) and shown in pgusinit's status output.
- While an image is in use, PGDFS refuses to delete, rename or write that file (access denied).

# v4.1.1

## Fixes/improvements

Fixes major issues in v4.1.0 where stale printf code in modes would cause the firmware to panic.

### SB mode

- Fixes clicks during single-cycle DMA audio playback.

### GUS mode

- Fixes one of the longest-lived bugs in GUS mode: playmidi in the GUS DOS software package now works!

# v4.1.0

## Fixes/improvements

### SB mode

- Sound Blaster ADPCM playback is now supported (4, 2.6, and 2-bit modes). This allows for sound effects in Duke Nukem 2 without needing to patch the game. Thanks to [Tube Time (@schlae)'s annotated disassembly of the SB DSP firmware](https://github.com/schlae/sb-firmware/tree/master) and [Torsten Stremlau (@TerrySoba)'s VocTool](https://github.com/TerrySoba/VocTool) for an MIT-licensed C implementation to use as a basis.
- Sample rates >44100Hz are now supported, for example 45454Hz, the fastest supported by SB16.
- SBMIDI is supported in addition to MPU-401 in SB mode.
- Fake ADC (recording) is supported. This records garbage data but should help SB16 sound card detection in some OSes.
- Fixes bug in passing DMA from BLASTER variable when running pgusinit. Thanks @andreacampanella for the fix in PR #134.
- More helpful error messages when the BLASTER variable does not match the port/IRQ/DMA settings stored on the PicoGUS.

### MPU-401

- Behavior of the MPU-401 emulation is now much more in line with a real MPU-401: it has a 256 byte ring buffer for MIDI out data, and flow control is done via bit 6 of the status port. Previously, MPU support had no flow control and used a pretty enormous buffer to make up for that. The SRAM savings from the smaller buffer will allow for more PicoGUS features in the future.
- Sysex delay is now accurately calculated (we were using microseconds, not milliseconds).
- Re-introduces the song change fix for Frederik Pohl's Gateway.

### CD-ROM

- Read multiple sectors at a time during CD audio playback. Should help with pops/distortion on marginal USB drives.
- Fixes loading .iso images in Win9x w/ MKEPanasonic driver by handling lead-out.
- The loaded image is printed after a successful `pgusinit /cdload`.

### General

- SRAM usage is saved across the board by completely eliminating debug prints in release builds, as well as eliminating use of sscanf() type functions. These debug prints didn't go anywhere in release builds (since the UART is taken by MIDI out, and USB by joystick), but they still had runtime overhead in calling printf(), etc.

# v4.0.0

## New features/changes

### Sound Blaster 16

SB mode now emulates a Sound Blaster 16. I had a somewhat-working implementation of the SB16 DSP in late 2024 but was discouraged by poor compatibility in Windows. Recently the ISA analyzer firmware (see below) gave me an easier way to compare PicoGUS to how a real SB16 behaves when detected by Windows and fix the long-standing bugs. Massive thanks to [Artem Vasilev (wbcbz7)](https://github.com/wbcbz7) who implemented proper mixer support and implemented a ton of additional fixes, including support for DMA controller demand mode, all of which made SB16 and SBPro support truly usable.

OPL3 support is provided by the dbopl OPL3 emulator (this was the default OPL3 emulator in DOSbox until somewhat recently). The previous emu8950 OPL2 emulator is still available in Adlib mode, and has some improvements thanks to [Daniel Arnold (Delphius)](https://github.com/RetroLoom): fixes to timer 2 and disabling of some of the optimizations made to emu8950 for rp2040-doom that affect sound quality. Delphius also experimented with Aaron Giles's [ymfm](https://github.com/aaronsgiles/ymfm) for OPL2/OPL3 emulation but it has some issues with RAM and CPU usage so it's not used for now.

Because PicoGUS is an 8-bit card, it does not support high DMA. This is actually a mostly-supported configuration for SB16: several versions could be jumpered to disable high DMA, and the Creative Vibra 16X/16XV does not support high DMA at all. Almost all SB16-supporting software is fine working without high DMA, or configuring the same DMA channel for both low and high DMA.

SB mode also supports Sound Blaster Pro stereo properly and still supports SB 2.0. `pgusinit` can be used to set the DSP version reported by PicoGUS. The Line In channel in the SB mixer also controls the volume of the wavetable header.

### ISA analyzer firmware

PicoGUS now has an ISA analyzer firmware that captures and logs ISA bus activity. This was inspired by the IDE analyzer firmware I wrote for PicoIDE. Having a tool like this brings a ton of insight into what's going on in the bus. Note that this firmware is made for the PicoGUS 1.x board with the RP2350-based Pico 2 or Pimoroni Pico Plus 2.

## Fixes/improvements

### CD-ROM support

- The stock Win9x MKEPanasonic driver can now be used with PicoGUS. This driver does not peg the CPU like the Creative driver, which should give much more acceptable performance. Credit to 86Box as a reference for this fix.
- CD-ROM speed in SB mode is even faster again - I've gotten speeds between 3.75X and 4.75X in DOS.
- Lots of general fixes & improvements to CD-ROM support, thanks to [Daniel Arnold (Delphius)](https://github.com/RetroLoom): protocol correctness fixes, pgusinit /cdlist stability, CUE parsing, and larger CD audio buffer.

### GUS mode

- The audio rendering in GUS mode is now interrupt-driven like SB mode. This allows for finer grained handling of IRQs which should help random freezes in GUS titles, and frees up CPU to allow more titles to work with forced 44.1kHz sampling rate.
- Fixes volume ramp rate calculation in force 44.1kHz mode.
- Fixes a race condition when updating volume ramp, again helping random freezes.

### General

- Reverted back to the pre-v3.2.0 method of overclocking the RP2040. This should hopefully fix the "doesn't come back after changing modes" issue reported by some people.

# v3.2.1

## Fixes/improvements

### pgusinit

Fixes several regressions in pgusinit:

- Fixes issue where port settings are parsed as decimal, not hex (fixes /mpuport, /gusport, /cdport, etc.)
- Fixes /sbport and /gusport commands not passing through option
- Fixes /wifistatus command
- Restores /defaults command

### General

- Gives VREG a bit more time to settle at bootup/reset. Should improve stability on initial poweron, after changing modes, or flashing firmware.

# v3.2.0

## Fixes/improvements

### General

- Settings saved in flash with `pgusinit /save` are now preserved when upgrading to a firmware version that introduces new settings
- Volume control is now available for all sources. For example, in SB mode, the SB DSP, OPL2, and CD-ROM audio volumes can be independently controlled. Thanks to [Daniel Arnold (Delphius)](https://github.com/RetroLoom) for contributing this!
- DualShock 4 gamepad support has been fixed

### SB mode

Sound Blaster playback has been almost completely rewritten, removing a major bottleneck and freeing up way more CPU time.

- Crashing on titles with simultaneous SB DSP & OPL2 fixed
- High-quality assembly optimized FIR polyphase resampler for much better sounding OPL2 output. Huge thanks to [korneliuszo](https://github.com/korneliuszo/) for contributing this and other optimizations!
- Direct DAC mode is back after being dropped in firmware v3.0.0
- Too-slow MPU-401 output in SB mode fixed (main symptom was long delay until music starts in Sierra titles)
- CD-ROM speed now faster in SB mode - improved from 2x to 3x

### pgusinit

pgusinit has been almost completely refactored, thanks again to [Daniel Arnold (Delphius)](https://github.com/RetroLoom). It not only helps future maintainability but brings new quality of life features:

- Long output like CD image listing and extended help text now pauses instead of scrolling off the screen
- Progress bar when flashing firmware instead of filling the screen with dots
- More helpful text if there are missing arguments
- Values can be set back to their default values with a `default` argument. Example: `pgusinit /cdport default`
- Added support for volume control via commands like /sbvol, /cdvol, etc.

# v3.1.0

## Fixes

### CD-ROM emulation

Many fixes/improvements to CD image handling:

- Add ability to load image by name
- Fix memory leak when changing images (file handle not freed, causing crash after switching images several times)
- Less memory usage all over
- Longer max file length limit (127 chars)
- Better errors when USB not present
- Fix polling of CD status register when listing images
- Many weird edge cases with image loading state fixed

# v3.0.1

## Fixes

### SB and USB modes

Fixes MPU-401 output in SB and USB modes. It was broken by the introduction of CD-ROM emulation in SB mode and it never actually worked in USB mode!

# v3.0.0

## New features/changes

### CD-ROM emulation

PicoGUS now supports CD-ROM emulation (in other words, PicoGUS is now an ODE)! It emulates a [Panasonic/MKE interface and drive](https://en.wikipedia.org/wiki/Panasonic_CD_interface) and supports CD images in ISO or BIN/CUE stored on a USB drive plugged into the USB port on the PicoGUS. CD-ROM emulation has been tested in DOS and Windows 9x and CD audio playback is fully supported.

CD-ROM emulation is available in Sound Blaster and USB modes. Sound Blaster mode really pushes the limit of the RP2040: it mixes CD audio, SB DSP, and OPL sound while simultaneously supporting CD data and MPU-401 emulation. The emulated drive is approximately 2x speed in SB mode and 3x-4x speed in USB mode. Disc images can be swapped on the fly with pgusinit, and multi-disc games are supported by removing and reinserting the USB drive to advance the current disc image.

For more information and a guide on how to use CD-ROM emulation on PicoGUS with recommended drivers, known limitations, etc., visit the new [CD-ROM emulation wiki page](https://github.com/polpo/picogus/wiki/CD%E2%80%90ROM-Emulation).

Massive thanks to [Kevin Moonlight (yyzkevin)](https://github.com/yyzkevin) for reverse engineering the Panasonic/MKE interface and contributing the bulk of the underlying code for this emulation.

Also major thanks to [rppicomidi](https://github.com/rppicomidi) for greatly improving mass storage speed for the RP2040 in TinyUSB and [Artem Vasilev (wbcbz7)](https://github.com/wbcbz7) for additional fixes and rebasing on a more recent state of the repository. Without their work, USB mass storage would not be nearly fast enough to support CD-ROM emulation on the RP2040. These improvements are still not merged into the upstream project, so here's hoping that can be completed.

And thanks to all who tested this firmware before release to surface bugs and edge cases I wouldn't have been able to find myself. Cue sheets are the wild west of formats!

### Tandy/CMS modes combined into new PSG (programmable sound generator) mode

To reduce firmware size and prepare for future support for other [PSG sound chips](https://en.wikipedia.org/wiki/Programmable_sound_generator) (here's a hint, it's the [AY-3](https://en.wikipedia.org/wiki/General_Instrument_AY-3-8910) as used on the [Mindscape Music Board](https://www.youtube.com/watch?v=Eeo4INoGyRY)), Tandy and CMS modes have been combined into a single PSG mode. It can be selected with `pgusinit /mode psg`, but the old `/mode tandy` and `/mode cms` switches still work for backwards compatibility.

## Fixes

### pgusinit

When pgusinit couldn't detect a PicoGUS, it would erroneously continue trying to configure the card. This would result in a strange firmware version mismatch error. This has now been fixed.

## Known issues

### Sound Blaster mode

Due to the addition of CD-ROM emulation to SB mode, SB DSP audio now runs through a FIFO. This may result in some playback issues that are being worked on. Also "Direct DAC" mode (mostly used by older titles) is not currently supported.

### General

Due to the addition of new settings, any saved settings done with `/pgusinit save` on previous firmware versions will be reset to defaults when upgrading to firmware v3.0.0.

# v2.2.0

## New features/changes

### NE2000 emulation/WiFi

*Please note* that this mode is not supported on PicoGUS 2.0! It needs a v1.1, v1.2, or Femto version of the PicoGUS that takes a Raspberry Pi Pico and requires a Pico W! I made this mode mainly just so I could use WiFi on my Pocket386 with a Femto card plugged into it. At least for now, NE2K mode comes in its own separate firmware file (`pg-ne2k.uf2`) and no other emulation is enabled when this firmware is loaded. Due to this limitation and the fact that the PCB design of the PicoGUS 1.x is not ideal for WiFI reception, consider this mode just a bit of a nice bonus. Config options have been added to pgusinit for NE2000 and WiFi SSID/password settings.

## Fixes

### Sound Blaster 2.0 emulation

* Fixes detection in Windows 9x, allowing SB mode to work in Windows 9x. Thanks to Ian Hanschen (@ianhan) for contributing the fix.
* Fixes detection in Tyrian and Dig-It! Thanks again to Ian Hanschen for the fix.
* Fixes detection in STMIK-based demos (Mental Surgery by Future Crew, SX by Substance, Min Monitor Briner by Syntax Error, probably others)

### GUS emulation

* Fixes intelligent mode MIDI buffer overrun and slow MIDI output in GUS mode. Usually showed up as an "Exc. Checksum Error" on the MT-32 screen. 

### General

* Fixes issue with setting port numbers less than 0x100 or ending in 00. This fixes common port settings like 0c0 for Tandy or 0x300 for NE2000
* Refactors timers to be less jittery; shouldn't be noticeable in practice but may fix some GUS emulation edge cases.

# v2.1.0

## New features/changes

### MPU-401 simultaneous with all modes

MPU-401 emulation is now available in all modes. This can enable simultaneous digital sound effects in SB or GUS modes with MIDI output. If you have another MPU-401 card in the system, to prevent conflicts this can be disabled or moved to a different port with the `/mpuport` option to pgusinit.

The original MPU mode is still available for titles that require MPU interrupts (titles on [this list](https://github.com/bjt42/softmpu/wiki/Compatible-Intelligent-Mode-Games) marked with a 1 require MPU interrupts).

# v2.0.0

## New features/changes

### Serial mouse emulation

Now you can use a USB mouse as a serial mouse on your PC. Features a configurable report rate defaulting to 60Hz so the emulated serial mouse is much smoother and more responsive than a real serial mouse. Also supports configurable sensitivity and protocol support, including Microsoft, Logitech, Mouse Systems, and Intellimouse with wheel support. Note that being a serial port, this does use an IRQ so the IRQ jumper on the PicoGUS must be set to IRQ 4 or 3 depending on which serial port is configured, or use a mouse driver like ctmouse that can use a custom IRQ. Serial mouse can be emulated simultaneously with sound card modes that do not require IRQ such as AdLib, CMS, and Tandy (MPU coming in future firmware for games that don't need MPU IRQ).

Thanks to [Artem Vasilev (wbcbz7)](https://github.com/wbcbz7) for implementing mouse and 8250 UART emulation.

### "Multifw" - all modes in one firmware

All emulation modes (GUS, SB, MPU, etc.) are now contained within the same firmware. This means switching between modes is much faster than before, taking 1-2 seconds on average. Switching also no longer involves writing new firmware to the card's flash, alleviating flash wear concerns (each sector on the flash is rated for at least 100,000 cycles, so there wasn't not much to worry about, but it's still nice for peace of mind).

Many thanks to [Jeroen Taverne](https://github.com/jeroentaverne) for developing [the original proof of concept](https://github.com/jeroentaverne/pico_multi_firmware) and [smymm](https://github.com/smymm) for implementing it within the PicoGUS codebase.

### Card settings can now be saved in flash

Once you're satisfied with your PicoGUS's settings, they can now be saved in the card's flash. Saved settings persist across reboots or power cycle without needing to run pgusinit each boot.

For example, when using serial mouse emulation, some BIOSes like MRBIOS need to see the emulated serial port right at boot. Also as a bonus if you want to use emulation modes outside of DOS, settings will apply in those other operating systems. Want to use GUS in OS/2 or Linux, or serial mouse when setting up NeXTStep? This will help!

### Overhaul of pgusinit

To support the above new features, adding more options to pgusinit meant I ran out of single letters for its various switches that make mnemonic sense. I've moved to longer yet hopefully still fast to type names for each of the switches.

Also, each pgusinit option now persists between invocations of pgusinit. Previously, most but not all options had to be given in the same invocation of pgusinit. Each option that would enable a feature (e.g. joystick support) has been turned into an on/off option so it can be turned off as well as on.

Running pgusinit by itself will now show all the currently applied settings for the current firmware mode.

See the [pgusinit README](https://github.com/polpo/picogus/blob/v2.0.0/pgusinit/README.md) for more details on running pgusinit.

## Fixes

### Sound Blaster 2.0:

* Added speaker on/off commands
* Greatly increased quality of output in "Direct DAC" mode

### OPL2 emulation

* Fixed "missing notes" issue, most commonly heard in Prince of Persia. Thank you to [TerryFi](https://github.com/TerryFi) for discovering the issue and coming up with a preliminary fix, then incorporating the final fix from the upstream emu8950 repository.

# v1.2.0

## New features/fixes

### Sound Blaster 2.0 emulation:

The AdLib mode (`pg-adlib.uf2`) has been replaced with a _new_ Sound Blaster 2.0 mode (`pg-sb.uf2`)! Code to emulate the Sound Blaster DSP was contributed by [Kevin Moonlight](https://github.com/yyzkevin) - huge thanks to him.

* Sound Blaster 2.0 DSP support is pretty well tested but you may run into issues. Please consult the [Compatibility List](https://github.com/polpo/picogus/wiki/Compatibility-list) for titles with known issues, and feel free to [file an issue on GitHub](https://github.com/polpo/picogus/issues/new) to report any problems.
* AdLib/OPL2 emulation has been improved, fixing issues with missing/wrong notes.
* The SB base port can be set with pgusinit with the `/p` option, and the OPL/AdLib base port with the new `/o` option.
* Some older titles supporting AdLib are "speed sensitive" and have weird playback on fast systems (even with a genuine OPL2/OPL3). A new `/w` option in pgusinit can work around these issues in most circumstances.

### MPU-401 emulation:

* Fixes an issue reported by zuldan on Vogons where running pgusinit in MPU-401 mode wouldn't work on certain systems. Fixed by initing the MPU-401 and sending the reset MIDI data asynchronously, preventing IOCHRDY from being held low for too long.
* Sysex delay handled without busy wait. Shouldn't have much effect presently, but may allow MPU-401 to be emulated simultaneously with other modes in the future.

### General:

* Allows the volume of the wavetable header to be set with the `/v` option in pgusinit in all modes. This is useful if you want to use the wavetable header to mix in other external audio sources like a CD-ROM drive (connection guide coming to the Wiki).

# v1.1.0

## New features/fixes

### GUS emulation:
* Works around a hardware bug in the PCM510xA DAC that results in ~10% of chips to be silent at 22.05kHz sampling rate. This is the rate produced by the GUS at 28 channels, and is used by Doom and the demo "Dope". The workaround is to run the DAC at 44.1kHz, linearly interpolating the 22.05kHz output.
* Increased fractional precision of wave addresses to 10 bits from 9.
* New EXPERIMENTAL fixed 44.1kHz output. Normally the GF1 varies its output sample rate from 44.1kHz at 14 voices to 19.2kHz at 32 voices. Using this option enables 44.1kHz output for all numbers of voices, similar to the Interwave. This gives much higher quality output when playing lots of channels.  This will result in stuttering in most games that use streaming DMA for sound effects like Doom, hence it is EXPERIMENTAL. It can be enabled with the `/4` switch in pgusinit. Thanks to [wbcbz7](https://github.com/wbcbz7) for contributing this support along with the increased wave address precision.
* Known issue: Impulse Tracker constantly re-inits the GUS to get the best sampling rate and if it passes through 28 channels rapidly, audio artifacts can be heard. To work around, run PicoGUS in fixed 44.1kHz output mode.

### pgusinit
* New `/4` switch when in GUS mode to enable fixed 44.1kHz output.

# v1.0.2

## New features/fixes

### General:
* New bus timing, fixes compatibility with IBM PC/AT 5170.
* Faster IOCHRDY timing to improve compatibility and spend less time on ISA bus.
* Less aggressive overclock and different startup timing to improve stability on reset.
* Added support for Xbox 360 wireless adapter dongle.

# v1.0.1

As always immediately after I do a big release, a significant bugfix comes soon after! Don't forget to look at the notes for firmware v1.0.0.

### General:
* Increase stability upon startup on PicoGUS 2.0 boards.

# v1.0.0

The PicoGUS 2.0 hardware brings v1.0.0 of the PicoGUS firmware! This firmware runs on _all_ released revisions of the PicoGUS hardware: 1.1, 1.1.1, 1.2, and 2.0.

## New features/fixes

### General:
* Support for PicoGUS 2.0 hardware and its software-controlled wavetable header volume (`/v xxx` pgusinit option).
* A preview of game port joystick emulation using USB joysticks is included in all sound card emulation modes, enabled with the `/j` pgusinit option. There is also a "joystick exclusive" firmware (`pg-joyex.uf2`) for when you only want to use a USB joystick and not emluate any sound cards. This is considered a preview because only a few USB joystick types are supported: wired Xbox 360 (and third party clone) controllers and the Sony DualShock 4. More joysticks will be supported in the future! See the [Compatibility List](https://github.com/polpo/picogus/wiki/Compatibility-list) wiki page for more information about this feature.
* Much more reliable firmware flashing from DOS. The previous method abused IOCHRDY to hold the ISA bus far longer than usual, and some chipsets would release the bus before certain flash operations were complete.
* A more robust startup sequence to improve firmware boot stability. All firmwares have the same LED sequence when starting so you will know when the firmware is ready.
* Compatibility with slower PSRAM chips that are rated for only 104MHz, such as the Vilsion Tech VTI7064MSME and ISSI IS66WVS1M8BLL-104NLI. This widens available options for those DIYing their own PicoGUS boards.

### pgusinit

pgusinit has been updated to version v2.0.0, featuring:

* Updates to pgusinit to support the new firmware flashing protocol, as well as support upgrading from v0.x.x firmware to v1.x.x firmware. If you have a v0.x.x version of firmware running on your PicoGUS, you can upgrade to v1.0.0 with the latest version of pgusinit included with the firmware release package.
* Detects the current card mode and only shows options applicable to that mode when using `/?` to ask for help.

### Adlib emulation:
* Fixes an issue where some software would incorrectly detect PicoGUS as an OPL3 instead of an OPL2.

### MPU-401 emulation:
* Sysex delay can be enabled with the `/s` pgusinit option. This will prevent buffer overflows on older MPU-401 revisions.
* Fake all-notes-off for the Roland RA-50 can be enabled with the `/n` pgusinit option.
* Fixes song change issue in Frederik Pohl's Gateway. PicoGUS will detect when Gateway is running and enable a hack in how the version and ack are returned. Run pgusinit to restore default operation after you're done playing Gateway.
* Running pgusinit will silence any stuck notes if a program exits unceremoniously.

# v0.7.0

## _Note:_ Please use the version of pgusinit.exe that comes with this firmware!

Version v0.7.0 of the firmware has a much smaller default GUS audio buffer size of 4 samples, thanks to the higher RP2040 clock speed. If you run an older version of pgusinit.exe, it will set the buffer size to 16 samples, negating many of the improvements that this version brings for GUS emulation.

## Release notes:

### General:
* Runs the RP2040 at 400MHz. This allows for faster reaction to ISA events, holding IOCHRDY low for shorter time periods. This allows better performance for other ISA cards and may help run on faster ISA bus speeds.
* Fixes from @SuperIlu for pgusinit to fix usage message and improve command line parsing.

### GUS emulation:
* Higher clock speed enables much shorter interval before checking for IRQs. This should improve compatibility in titles that use IRQs and DMA.
* Fixes for Hand386 and other M6117D-based systems.
* Changes to pgusinit to default to the new GUS buffer size of 4 samples, and support setting the buffer size below 8 samples. Please use the new version of pgusinit that ships with this firmware!

### Tandy emulation:
* New emulation core contributed by [Aaron Giles](https://aarongiles.com/). This is the same core used in [DREAMM](https://aarongiles.com/dreamm/) and should result in better accuracy across all titles. or example, sound effects such as crickets chirping and meteor crash in Maniac Mansion and snoring in Zak McKracken sound much better.

### CMS emulation:
* New emulation core contributed by [Aaron Giles](https://aarongiles.com/). This is the same core used in [DREAMM](https://aarongiles.com/dreamm/) and should result in better accuracy across all titles.
* Fixes issue with pitch of CMS sound being too high.

### MPU-401 emulation:
* Misc optimizations might improve compatibility in some titles.

For known issues, please see the [Compatibility List](https://github.com/polpo/picogus/wiki/Compatibility-list) wiki page.

# v0.6.1

Another bugfix release! This release fixes a bug introduced in firmware [v0.5.0](https://github.com/polpo/picogus/releases/tag/v0.5.0) that caused Descent to freeze on the `Loading...` indicator when running setup and starting the game. 

### GUS emulation:
* Fixes freeze when starting Descent. This patch release uses a smaller/simpler 4-byte DMA buffer that solves the freeze with Descent while also hopefully still preventing stuttering in Doom introduced by level changes (the reason for the DMA buffer in the first place).

For known issues, please see the [Compatibility List](https://github.com/polpo/picogus/wiki/Compatibility-list) wiki page.

# v0.6.0

### CMS emulation:
* New emulation mode: **CMS/Game Blaster**.

For known issues, please see the [Compatibility List](https://github.com/polpo/picogus/wiki/Compatibility-list) wiki page.

# v0.5.1

Bugfix release! All of the new features of [v0.5.0](https://github.com/polpo/picogus/releases/tag/v0.5.0) plus the following fixes:

### Tandy emulation:

* Fixed reporting of base port when running pgusinit when on Tandy firmware
* Fixed firmware flashing from DOS when on Tandy firmware

# v0.5.0

### General:
* More reliable firmware flashing from pgusinit by clocking down the Pico and disabling interrupts. Many thanks to JazeFox at Vogons for debugging this issue and suggesting a fix.

### Tandy emulation:
* New emulation mode: **Tandy 3-Voice**. This emulation is on port 2C0h by default, to avoid conflicts or masked IO on the default Tandy port of 0C0h in non-Tandy systems. This is the same alternate port that [Matze79's "TNDY" card](https://www.vogons.org/viewtopic.php?f=62&t=54249) can use. Use the [TNDY driver program](https://github.com/JKnipperts/TNDY) to redirect port 0C0h to 2C0h. Also [many games need to be patched](https://www.vogons.org/viewtopic.php?t=77679) to allow for Tandy sound on non-Tandy systems with CGA, EGA, or VGA graphics. Note that this mode has not received much optimization, so accuracy and compatibility can be improved.

### GUS emulation:
* Resets DMA status bit to 0 on completion of DMA handler. Fixes some Demoscene titles.
* Buffers uploaded DMA samples instead of writing 1 byte at a time. Currently this buffer is 8 bytes, and may be configurable in future releases. Should help stuttering/slowdown issues in games that use streaming DMA audio like Doom.
* Bails out on sound rendering when sample rate changes. This should eliminate any "warbling" sounds when Impulse Tracker resets the channel count on the fly.
* Uses the [RP2040 hardware interpolation](https://people.ece.cornell.edu/land/courses/ece4760/RP2040/C_SDK_interpolator/index_interpolator.html) unit to interpolate samples and clamp output to 16 bits.

For known issues, please see the [Compatibility List](https://github.com/polpo/picogus/wiki/Compatibility-list) wiki page.

# v0.4.0

### General:
* New version (v1.0.1) of pgusinit.exe - DMA interval is in µs, not ms

### GUS emulation:
* Refactored DMA transfer completion handler: this results in much higher compatibility with titles that use streaming DMA. Overriding the DMA transfer interval is not necessary in most circumstances now.
  * Fixes games: Quake, Doom (and Doom engine games), Duke3D, Descent, Hocus Pocus (partially); Demo: Inside
* Fixed bug where DMA control register was not properly reset between transfers. Fixes garbage samples when uploading mixed 16 & 8 bit samples.
  * Fixes music players/trackers: Open Cubic Player (with `gusFastUpload=on`), Fast Tracker 2

# v0.3.0

### General:
* Firmware can now be programmed from DOS (requires FW v0.3.0 or above - upgrading from previous versions must be done by USB)
   * Emulation mode can be changed "on the fly" by uploading different firmwares
* New version (v1.0.0) of pgusinit.exe - Firmware versions v0.3.0+ require this new version of pgusinit.exe!

### GUS emulation:
* Major DMA improvements!
  * DMA PIO state machine rewrite to solve sample glitches (fixes Star Control II)
  * Asynchronous writing to PSRAM of DMAed samples (fixes Doom)
  * Smarter sample cache (fixes Doom)
  * Adjustable DMA interval (fixes Doom)
* One firmware for all ports - base port is now configured with `ULTRASND` environment variable and pgusinit.exe

### MPU-401 emulation:
* Intelligent mode emulation is now working in all but a few titles
* Base port now configured with pgusinit.exe (defaults to 330)

### AdLib emulation:
* Base port now configured with pgusinit.exe (defaults to 388) 

# v0.2.0

* Solved a regression where lots of channels playing 16-bit samples would cause audio stuttering (example: the demo Aeon Drift by Disaster Area). Added a super simple sample pair buffer per channel to solve this.
* Super-unstable DMA support preview. Count on it to fail, but feel free to celebrate when it works! 😅
* Fixed a small bug in pgusinit.exe that didn't set the audio buffer size to 16 if the `/a` option was not given on the command line.
* Includes firmwares for GUS port 220, 240, and 260.
* Built with a new automatic release script.

For firmware programming instructions, see the ["Programming the Pico" part of the build guide](https://github.com/polpo/picogus/wiki/Building-your-PicoGUS#programming-the-pico).

# v0.1.0

* New release format: a ZIP file containing firmware UF2 files and PGUSINIT.EXE.
* Features all IRQ fixes shown in the [November 2022 update video](https://youtu.be/CkJvkJVRscQ) and then some – regressions introduced by those fixes have now been fixed. 😅
* New version of PicoGUSinit (PGUSINIT.EXE) to allow the audio buffer size on the PicoGUS to be configured via the `/a n` option, where `n` is the size of the buffer in samples. Some productions may still freeze, or have audio glitches, and configuring the buffer size can help. Please see the [Compatibility List](https://github.com/polpo/picogus/wiki/Compatibility-list) for the flag to use for any problematic programs.
* Preview firmware for Adlib and MPU-401 emulation.

For firmware programming instructions, see the ["Programming the Pico" part of the build guide](https://github.com/polpo/picogus/wiki/Building-your-PicoGUS#programming-the-pico).

# v0.0.1

Contents:
`picogus.uf2` - Firmware with Gravis Ultrasound emulation core, port 240
`PGUSINIT.EXE` - DOS executable to detect and initialize the PicoGUS

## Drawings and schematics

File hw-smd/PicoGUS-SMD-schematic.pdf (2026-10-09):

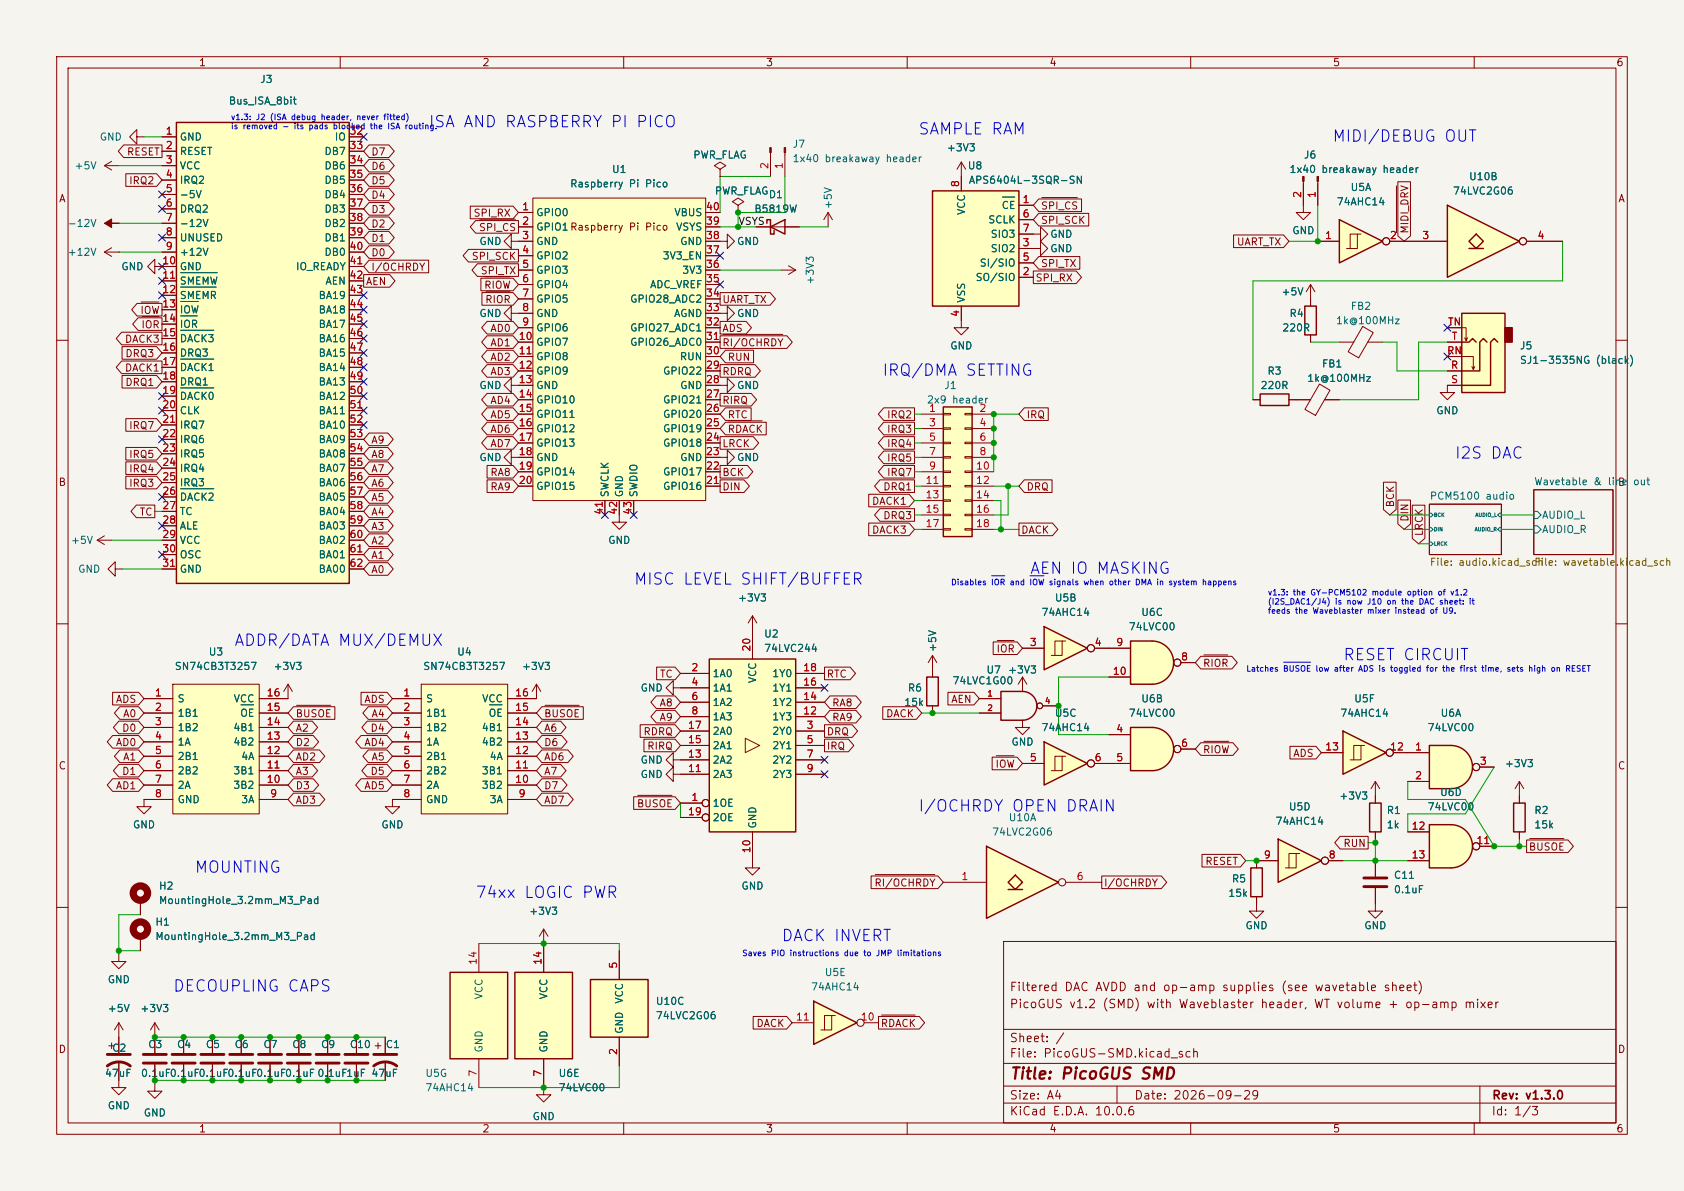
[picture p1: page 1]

v1.3: J2 (ISA debug header, never fitted)

ISA AND RASPBERRY PI PICO

feeds the Waveblaster mixer instead of U9. IRQ/DMA SETTING

AUDIO_L AUDIO_R Wavetable & line out File: wavetable.kicad_sch

Disables IOR and IOW signals when other DMA in system happens MOUNTING

v1.3: the GY-PCM5102 module option of v1.2
(I2S_DAC1/J4) is now J10 on the DAC sheet: it

ADDR/DATA MUX/DEMUX

Latches BUSOE low after ADS is toggled for the first time, sets high on RESET

Saves PIO instructions due to JMP limitations DACK INVERT

Filtered DAC AVDD and op-amp supplies (see wavetable sheet)
PicoGUS v1.2 (SMD) with Waveblaster header, WT volume + op-amp mixer

Size: A4 | Rev: v1.3.0
KiCad E.D.A. 10.0.6 | Id: 1/3

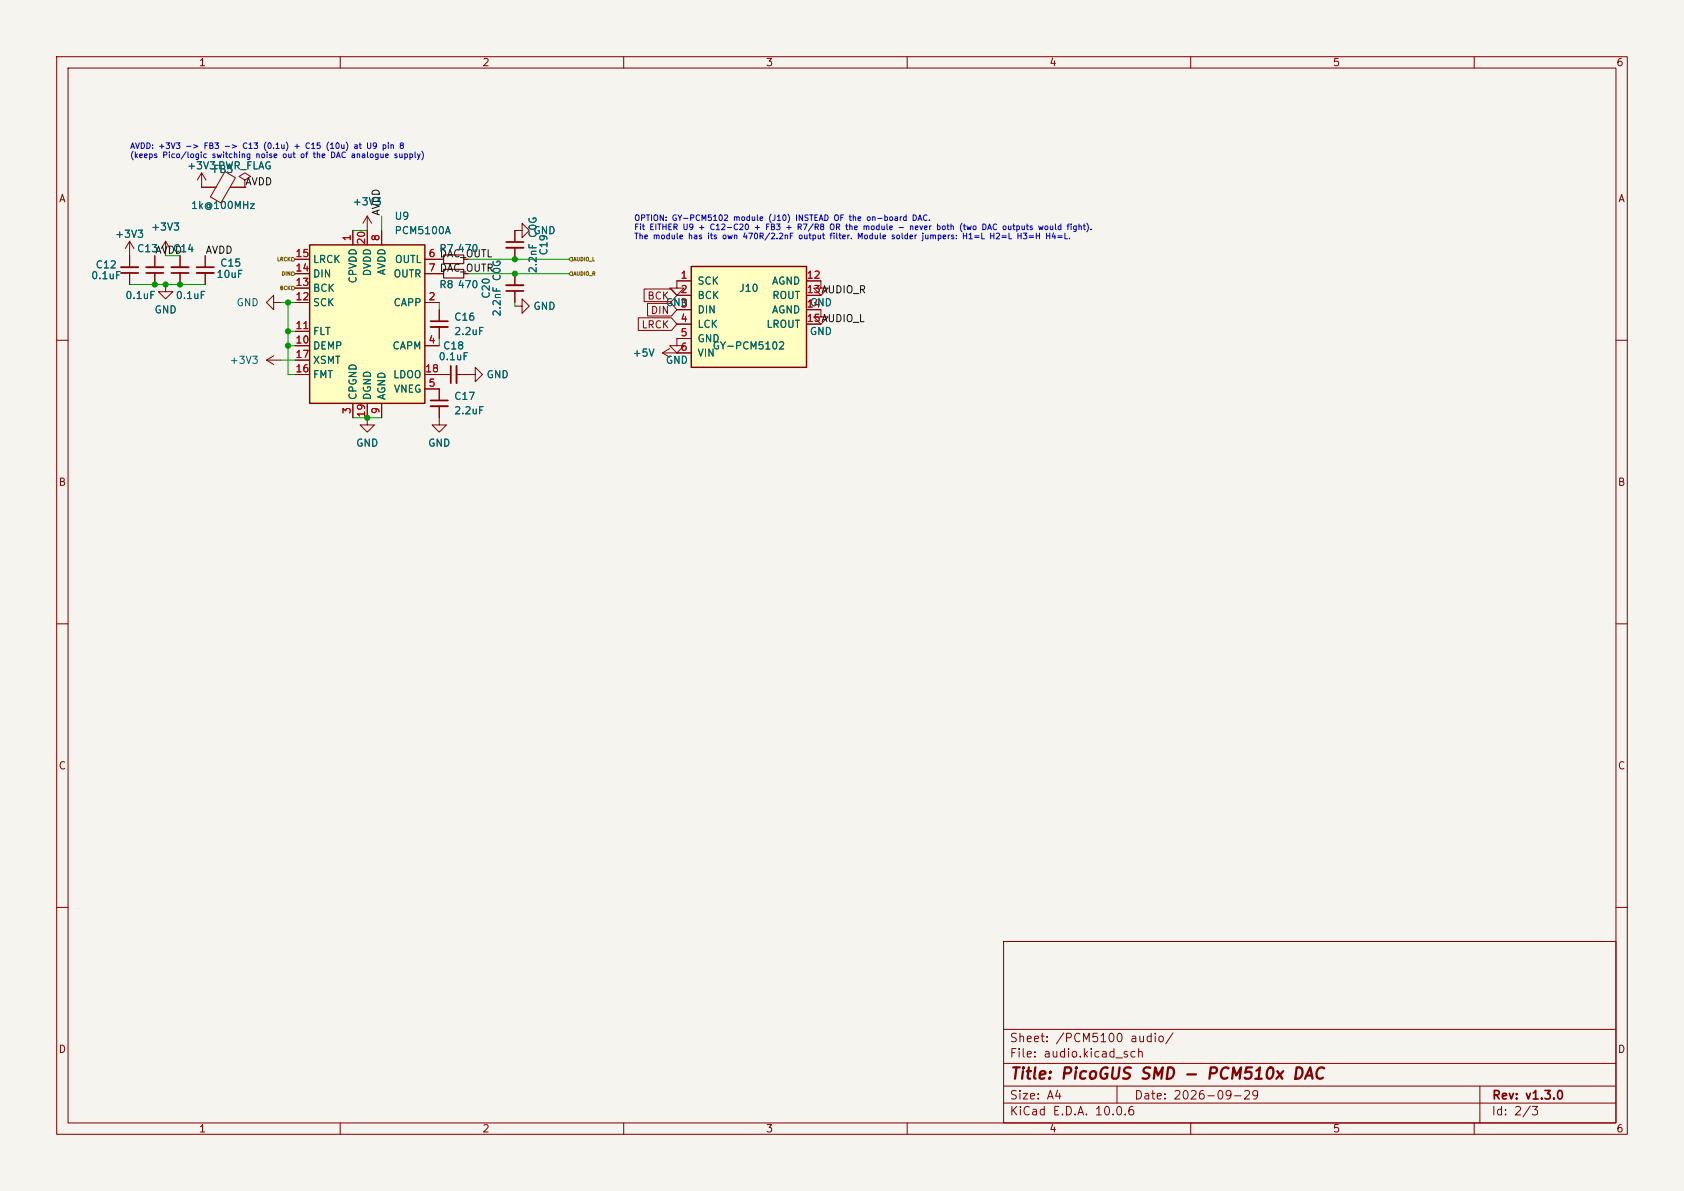
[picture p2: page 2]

(keeps Pico/logic switching noise out of the DAC analogue supply) C15

SCK 12 BCK 13 DIN 14 LRCK 15

Sheet: /PCM5100 audio/
File: audio.kicad_sch
Title: PicoGUS SMD - PCM510x DAC

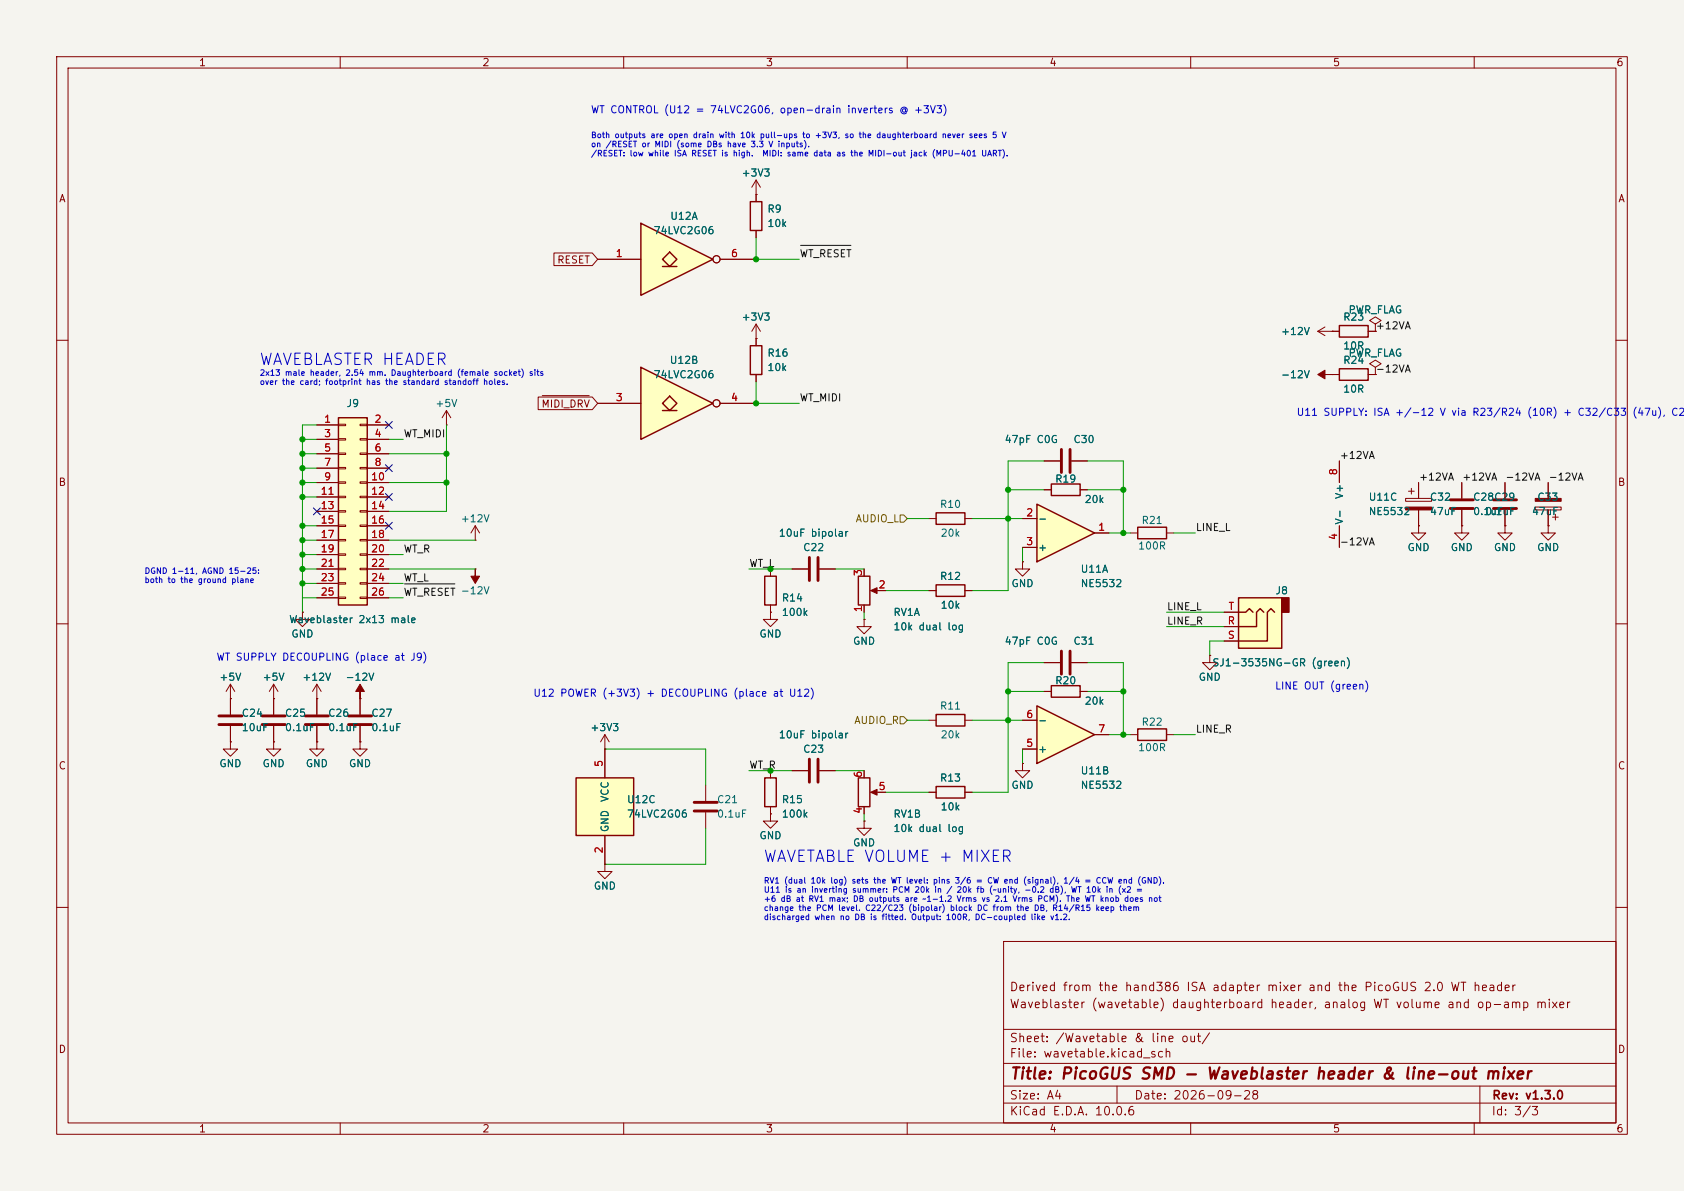
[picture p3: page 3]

2x13 male header, 2.54 mm. Daughterboard (female socket) sits over the card; footprint has the standard standoff holes. DGND 1-11, AGND 15-25: both to the ground plane WAVEBLASTER HEADER

Derived from the hand386 ISA adapter mixer and the PicoGUS 2.0 WT header C28
47uF GND

discharged when no DB is fitted. Output: 100R, DC-coupled like v1.2. WAVETABLE VOLUME + MIXER

RV1 (dual 10k log) sets the WT level: pins 3/6 = CW end (signal), 1/4 = CCW end (GND). U11 is an inverting summer: PCM 20k in / 20k fb (~unity, -0.2 dB), WT 10k in (x2 =

+6 dB at RV1 max; DB outputs are ~1-1.2 Vrms vs 2.1 Vrms PCM). The WT knob does not change the PCM level. C22/C23 (bipolar) block DC from the DB, R14/R15 keep them

Waveblaster (wavetable) daughterboard header, analog WT volume and op-amp mixer

Sheet: /Wavetable & line out/
File: wavetable.kicad_sch
Title: PicoGUS SMD - Waveblaster header & line-out mixer

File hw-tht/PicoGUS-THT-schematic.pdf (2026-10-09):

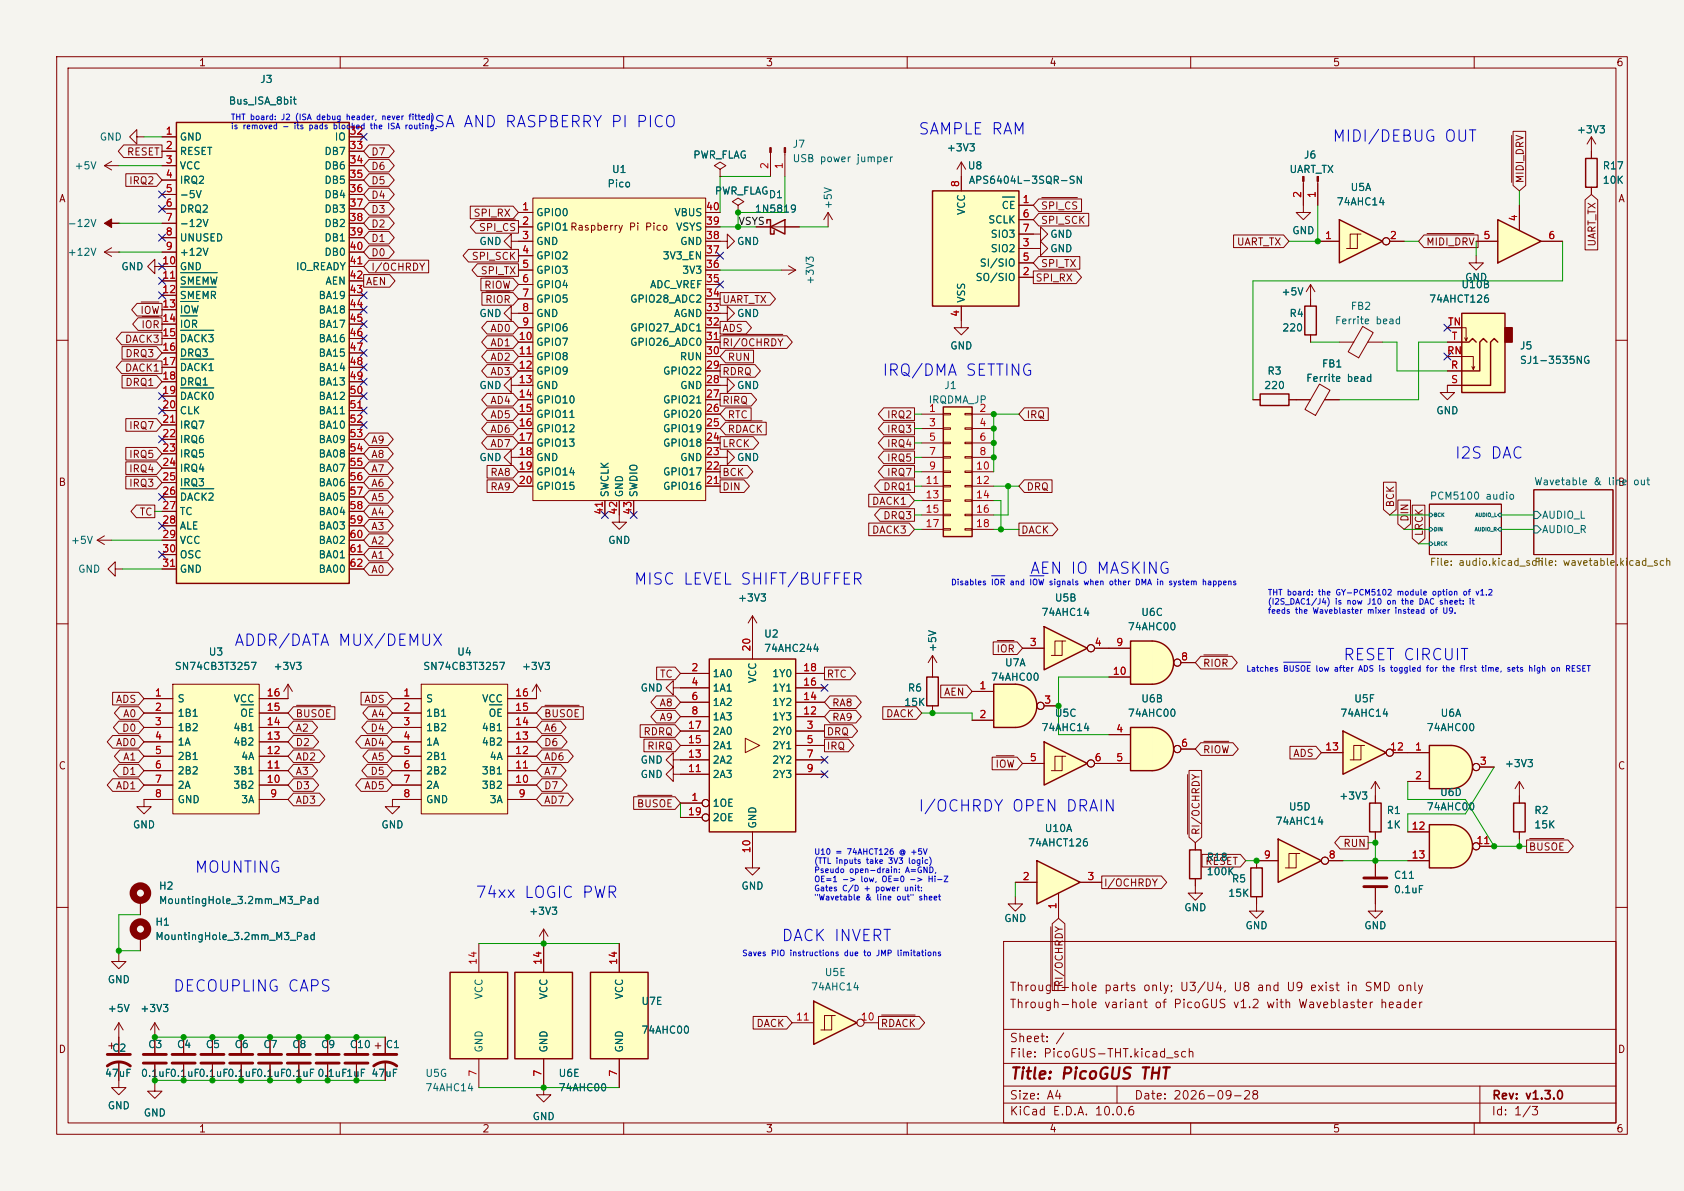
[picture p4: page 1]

THT board: J2 (ISA debug header, never fitted)

ISA AND RASPBERRY PI PICO

Latches BUSOE low after ADS is toggled for the first time, sets high on RESET MIDI/DEBUG OUT

AUDIO_L AUDIO_R Wavetable & line out File: wavetable.kicad_sch

THT board: the GY-PCM5102 module option of v1.2
(I2S_DAC1/J4) is now J10 on the DAC sheet: it

feeds the Waveblaster mixer instead of U9. MOUNTING

(TTL inputs take 3V3 logic) Pseudo open-drain: A=GND, OE=1 -> low, OE=0 -> Hi-Z Gates C/D + power unit: "Wavetable & line out" sheet DACK INVERT

Saves PIO instructions due to JMP limitations

Through-hole parts only; U3/U4, U8 and U9 exist in SMD only
Through-hole variant of PicoGUS v1.2 with Waveblaster header

Size: A4 | Rev: v1.3.0
KiCad E.D.A. 10.0.6 | Id: 1/3

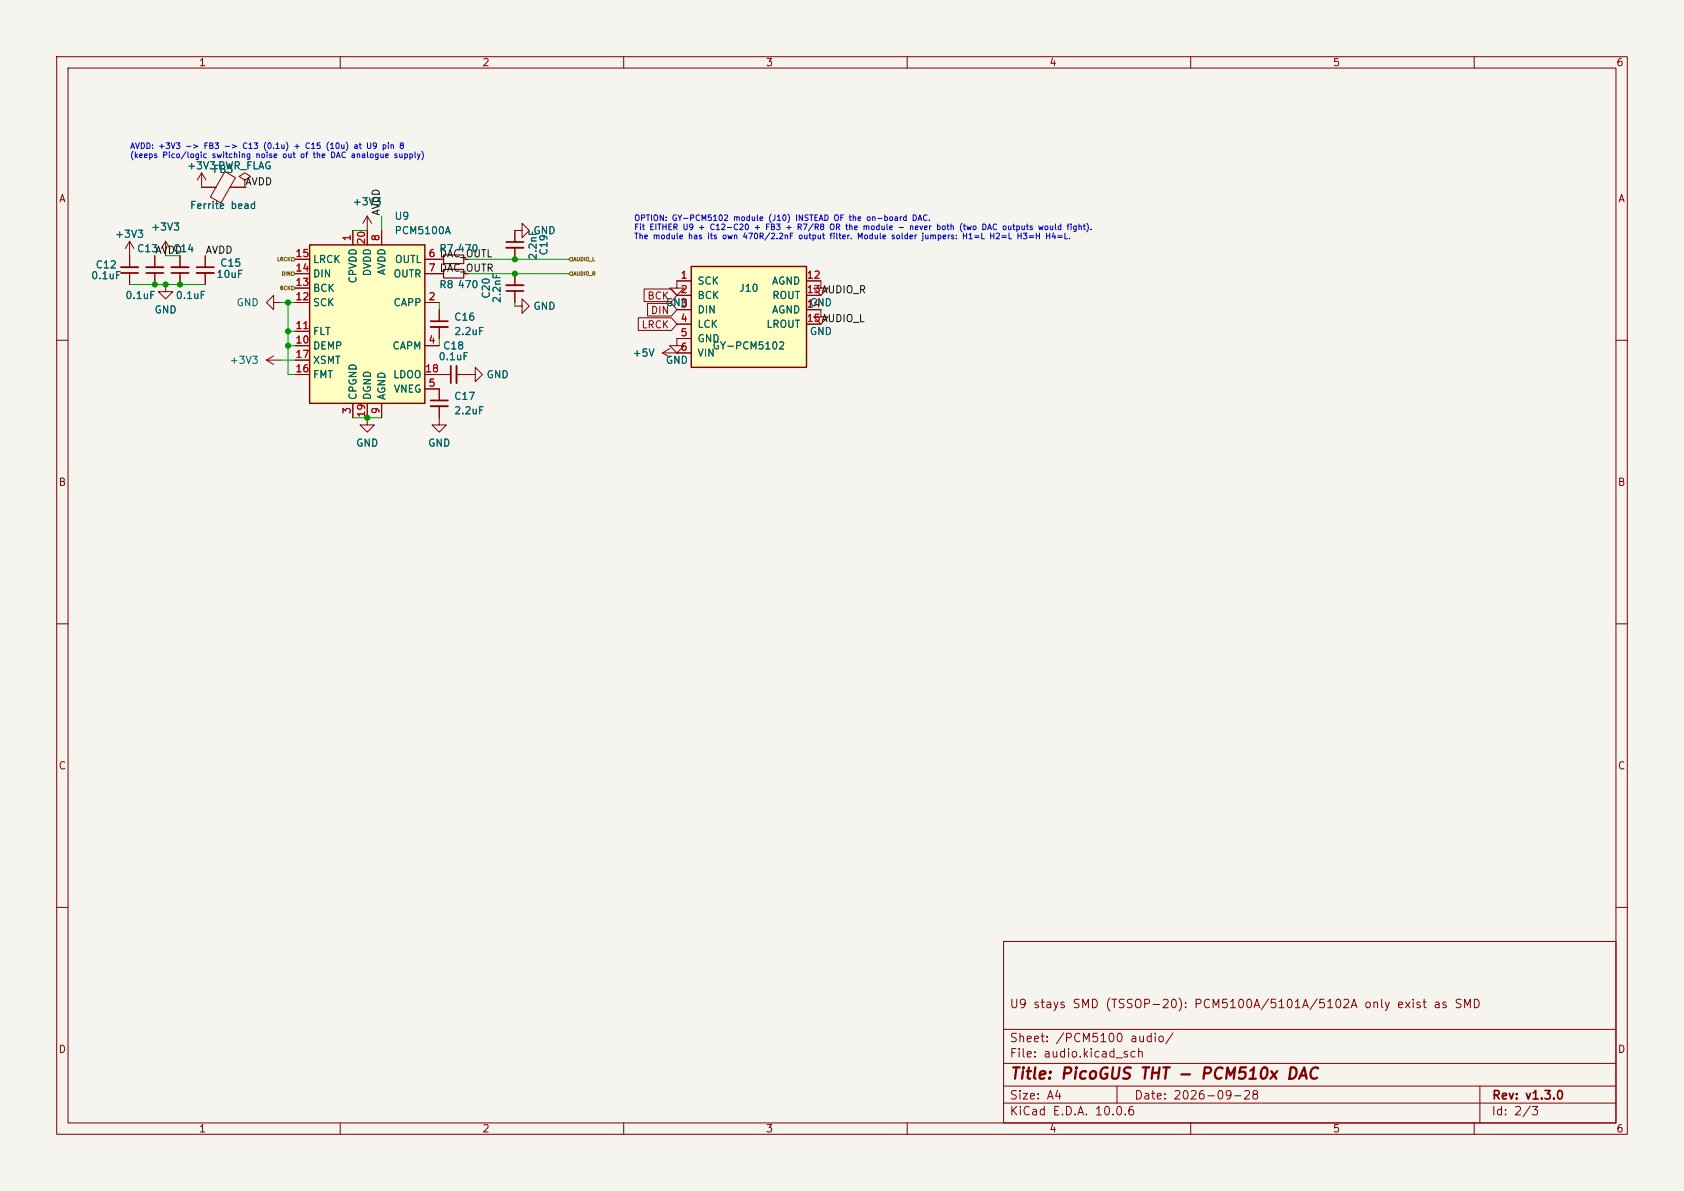
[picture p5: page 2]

(keeps Pico/logic switching noise out of the DAC analogue supply) C15
LDOO 18 DGND 19 DVDD 20 GND
2.2uF R8 470 CPVDD

SCK 12 BCK 13 DIN 14 LRCK 15
AUDIO_L DIN

U9 stays SMD (TSSOP-20): PCM5100A/5101A/5102A only exist as SMD

Sheet: /PCM5100 audio/
File: audio.kicad_sch
Title: PicoGUS THT - PCM510x DAC

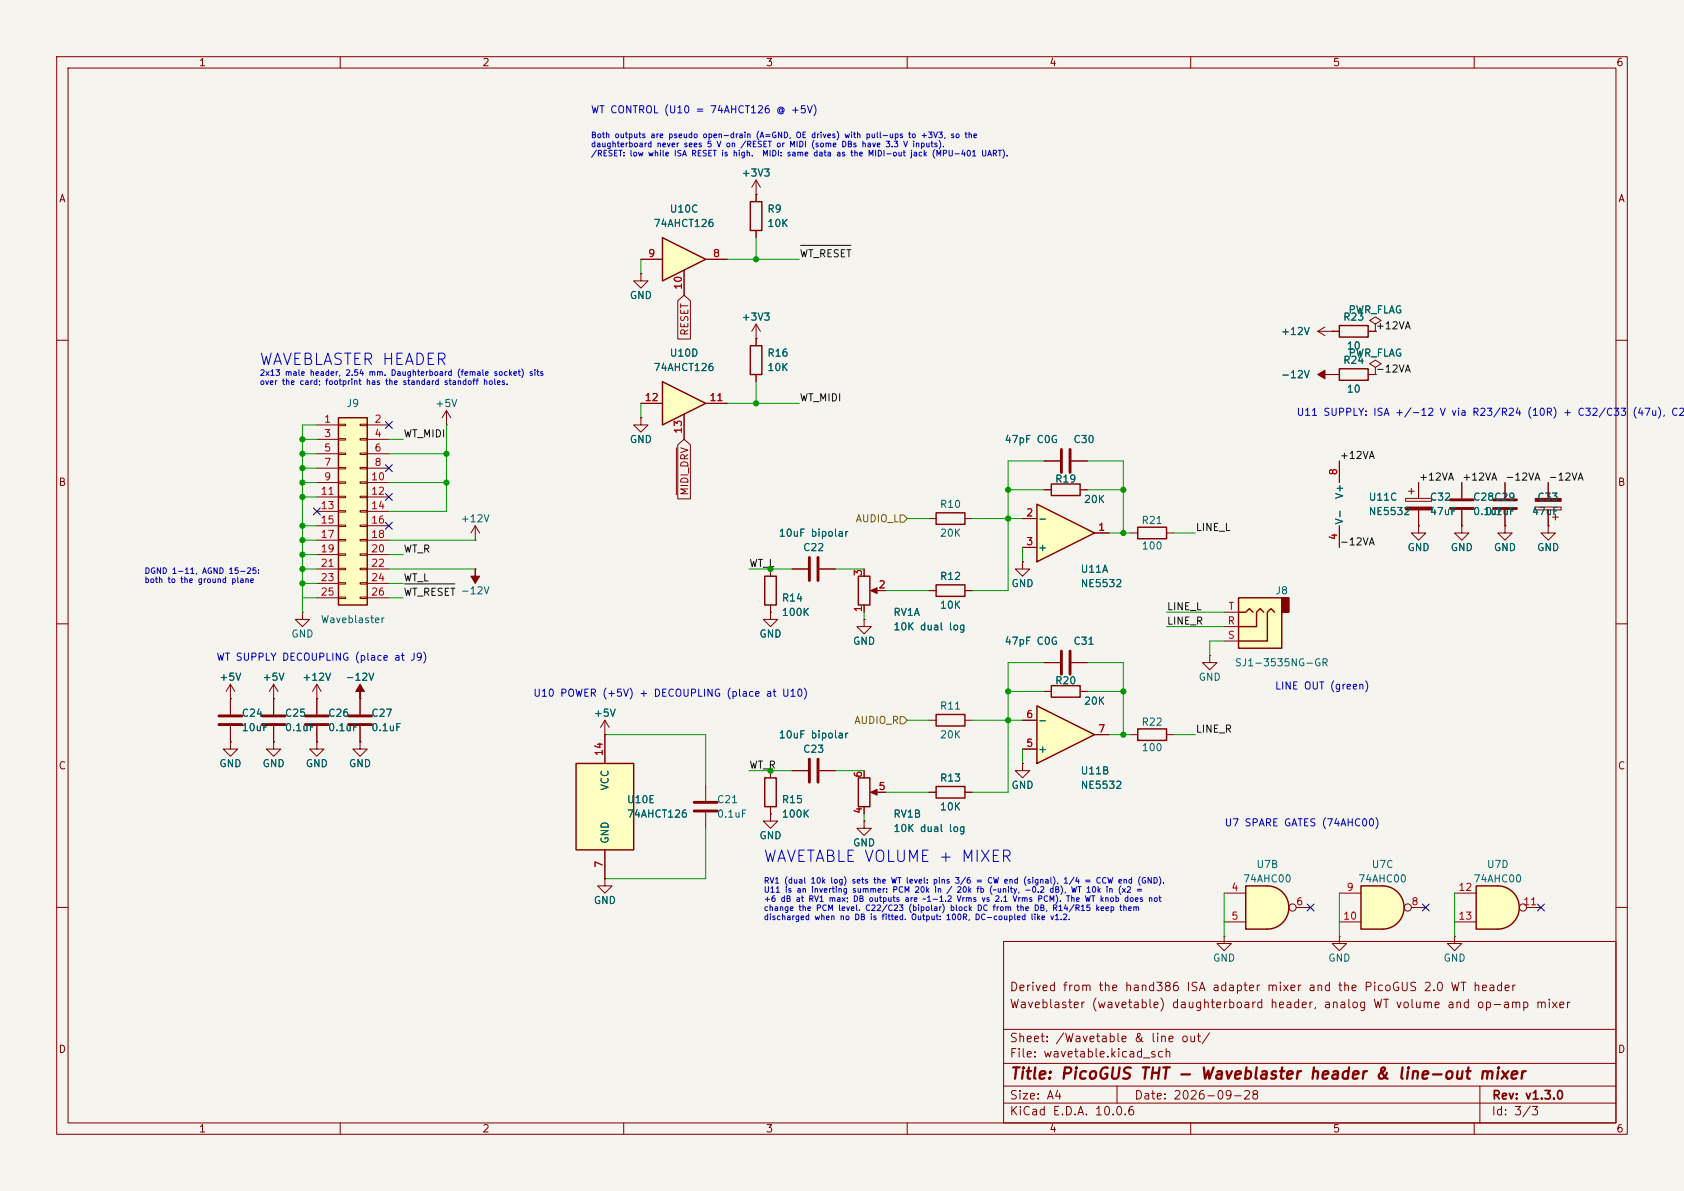
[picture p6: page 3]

RV1 (dual 10k log) sets the WT level: pins 3/6 = CW end (signal), 1/4 = CCW end (GND). U11 is an inverting summer: PCM 20k in / 20k fb (~unity, -0.2 dB), WT 10k in (x2 =

+6 dB at RV1 max; DB outputs are ~1-1.2 Vrms vs 2.1 Vrms PCM). The WT knob does not change the PCM level. C22/C23 (bipolar) block DC from the DB, R14/R15 keep them

discharged when no DB is fitted. Output: 100R, DC-coupled like v1.2.

Waveblaster (wavetable) daughterboard header, analog WT volume and op-amp mixer

Sheet: /Wavetable & line out/
File: wavetable.kicad_sch
Title: PicoGUS THT - Waveblaster header & line-out mixer

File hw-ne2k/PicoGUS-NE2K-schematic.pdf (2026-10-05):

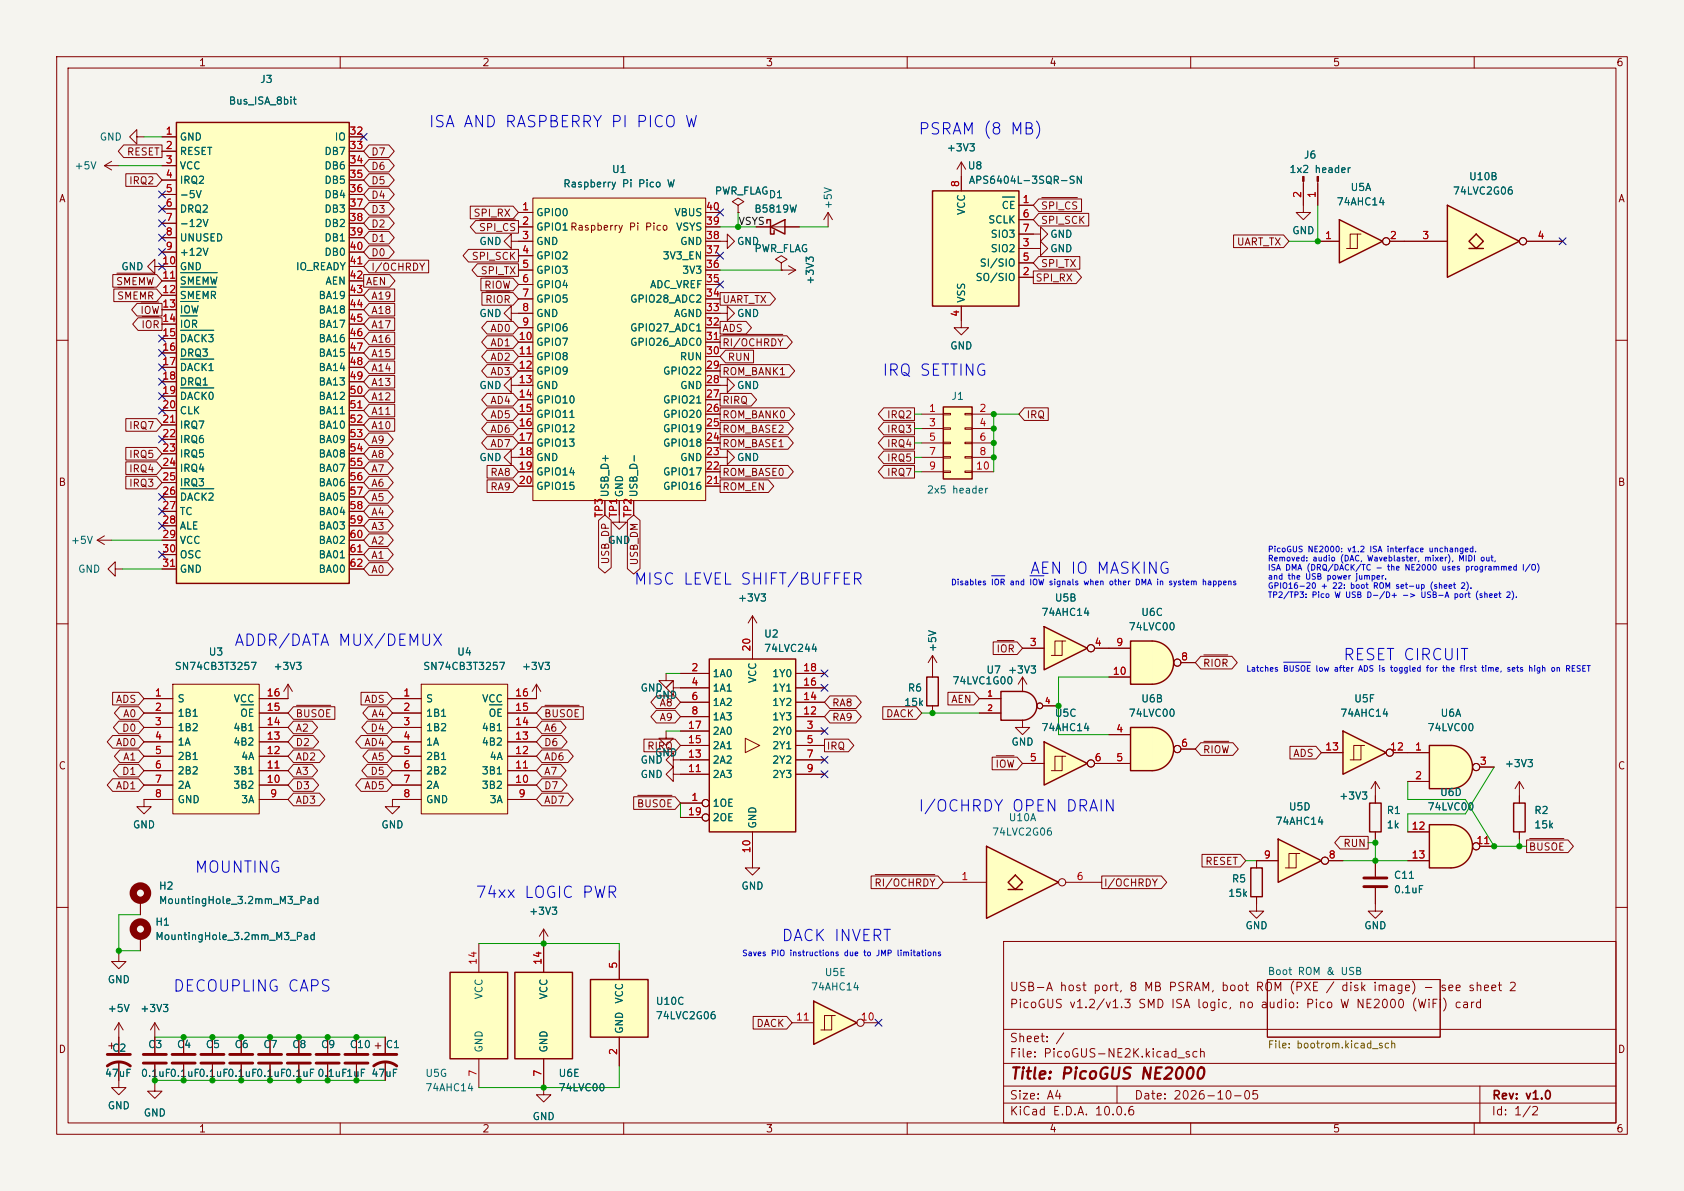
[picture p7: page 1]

ISA AND RASPBERRY PI PICO W

PicoGUS NE2000: v1.2 ISA interface unchanged. Removed: audio (DAC, Waveblaster, mixer), MIDI out,

Disables IOR and IOW signals when other DMA in system happens AEN IO MASKING MISC LEVEL SHIFT/BUFFER

ISA DMA (DRQ/DACK/TC - the NE2000 uses programmed I/O) and the USB power jumper. GPIO16-20 + 22: boot ROM set-up (sheet 2). TP2/TP3: Pico W USB D-/D+ -> USB-A port (sheet 2).

ADDR/DATA MUX/DEMUX
Latches BUSOE low after ADS is toggled for the first time, sets high on RESET MOUNTING

Saves PIO instructions due to JMP limitations

PicoGUS v1.2/v1.3 SMD ISA logic, no audio: Pico W NE2000 (WiFi) card

Size: A4 | Rev: v1.0
KiCad E.D.A. 10.0.6 | Id: 1/2

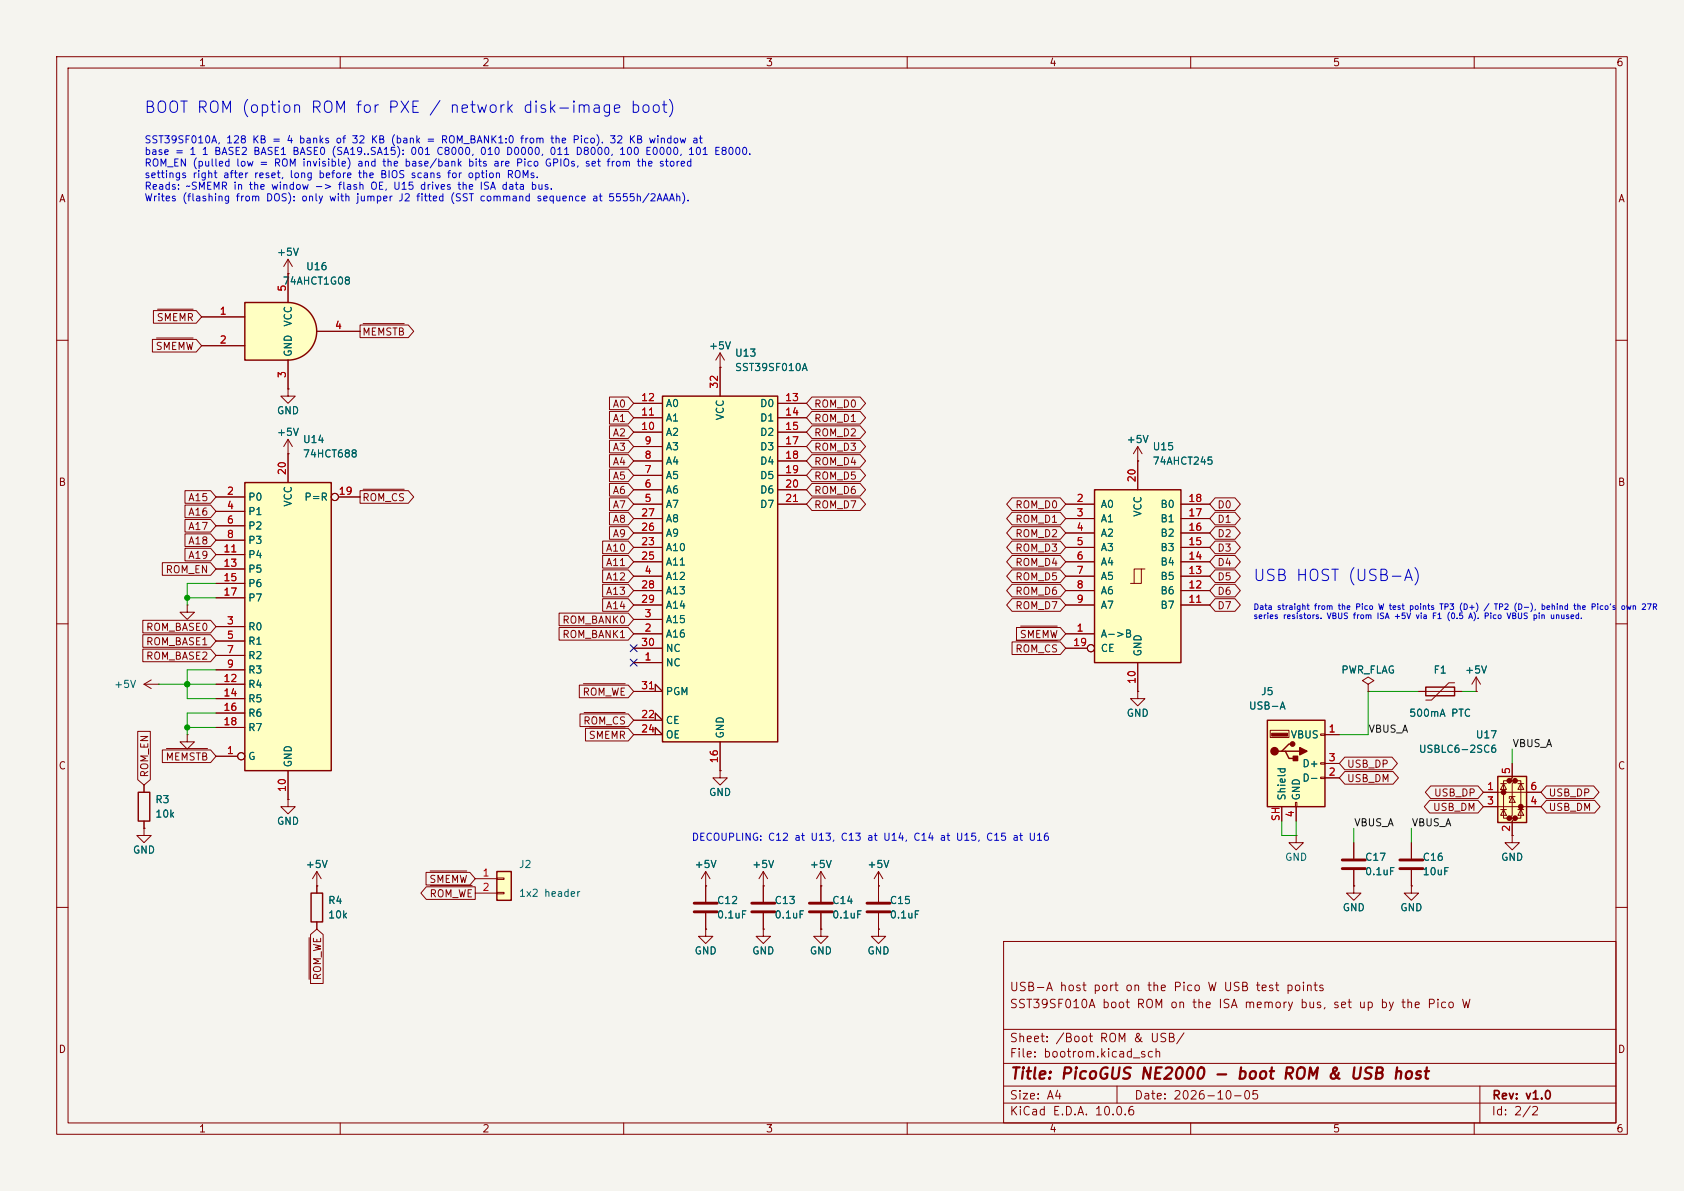
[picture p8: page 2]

series resistors. VBUS from ISA +5V via F1 (0.5 A). Pico VBUS pin unused. SST39SF010A, 128 KB = 4 banks of 32 KB (bank = ROM_BANK1:0 from the Pico). 32 KB window at base = 1 1 BASE2 BASE1 BASE0 (SA19..SA15): 001 C8000, 010 D0000, 011 D8000, 100 E0000, 101 E8000. ROM_EN (pulled low = ROM invisible) and the base/bank bits are Pico GPIOs, set from the stored

settings right after reset, long before the BIOS scans for option ROMs. Reads: ~SMEMR in the window -> flash OE, U15 drives the ISA data bus. Writes (flashing from DOS): only with jumper J2 fitted (SST command sequence at 5555h/2AAAh).

Data straight from the Pico W test points TP3 (D+) / TP2 (D-), behind the Pico's own 27R

USB-A host port on the Pico W USB test points
SST39SF010A boot ROM on the ISA memory bus, set up by the Pico W

Sheet: /Boot ROM & USB/
File: bootrom.kicad_sch
Title: PicoGUS NE2000 - boot ROM & USB host

Size: A4 | Rev: v1.0
KiCad E.D.A. 10.0.6 | Id: 2/2

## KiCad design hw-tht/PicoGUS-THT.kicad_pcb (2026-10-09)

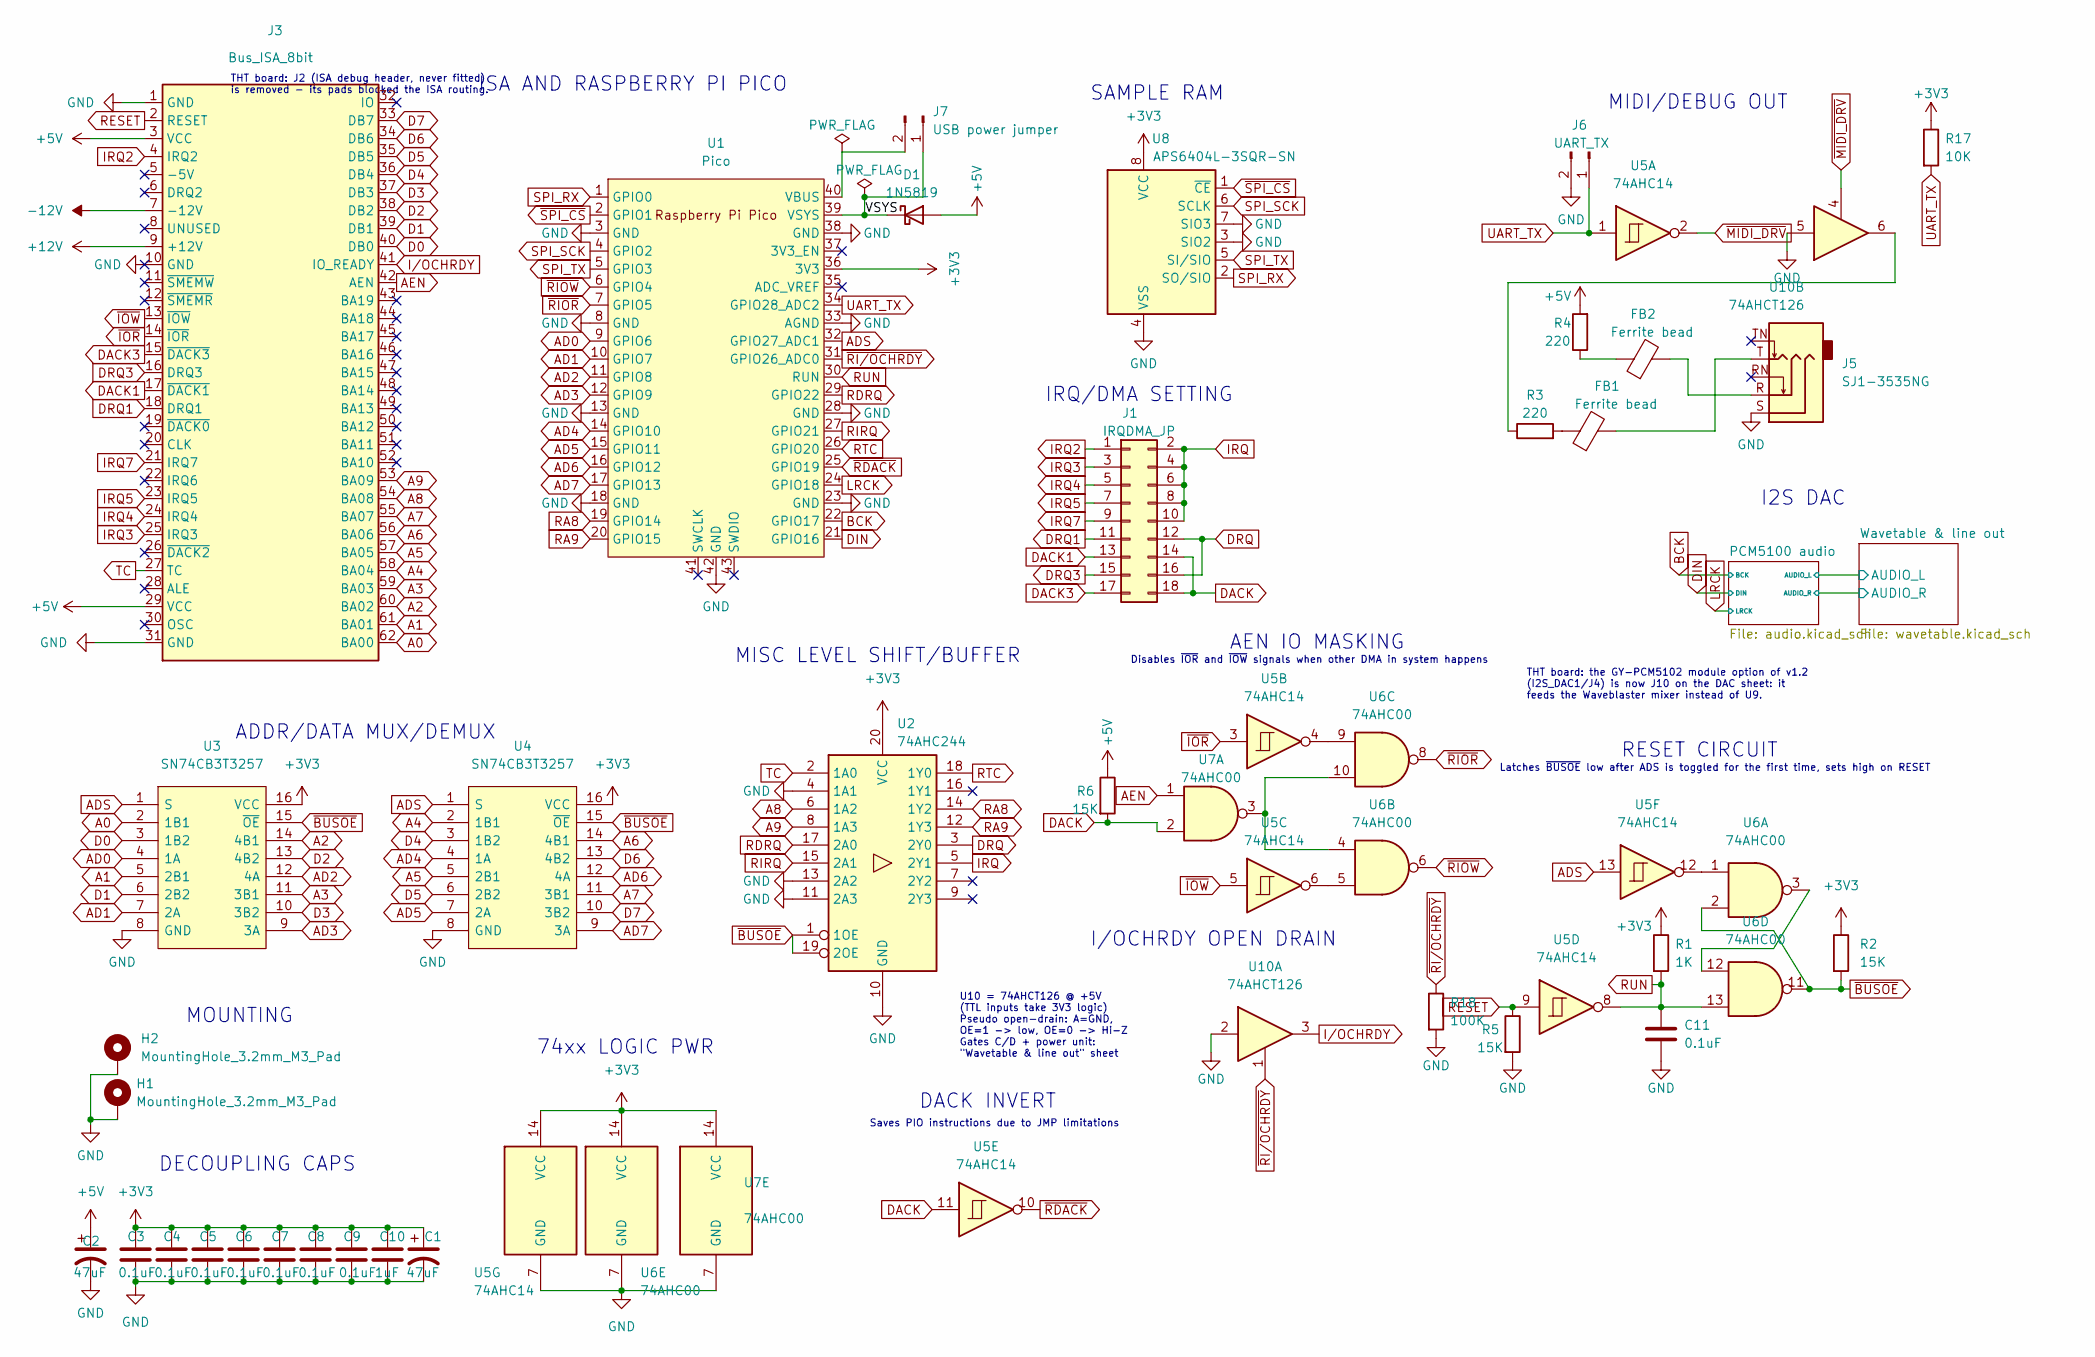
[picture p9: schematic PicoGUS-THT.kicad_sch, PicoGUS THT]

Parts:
C1, C2: 47uF; CP_Radial_D5.0mm_P2.00mm; MPN 35YXJ47M5X11; DigiKey 1189-2919-ND
C3, C4, C5, C6, C7, C8, C9, C11: 0.1uF; C_Disc_D5.0mm_W2.5mm_P5.00mm; MPN RDER71H104K0M1H03A; DigiKey 490-9144-1-ND
C10: 1uF; C_Disc_D5.0mm_W2.5mm_P5.00mm; MPN RDER71H105K2M1H03A; DigiKey 490-9146-1-ND
D1: 1N5819; D_DO-41_SOD81_P10.16mm_Horizontal; MPN 1N5819RLG; DigiKey 1N5819RLGOSCT-ND
FB1, FB2: Ferrite bead; R_Axial_DIN0309_L9.0mm_D3.2mm_P12.70mm_Horizontal; MPN 2743002112; DigiKey 1934-1477-1-ND
H1, H2: MountingHole_3.2mm_M3_Pad
J1: IRQDMA_JP; PinHeader_2x09_P2.54mm_Vertical; MPN 10129381-918001BLF; DigiKey 609-10129381-918001BLF-ND
J3: Bus_ISA_8bit; BUS_PC_chamfer
J5: SJ1-3535NG; Jack_3.5mm_CUI_SJ1-3535NG_Horizontal; MPN SJ1-3535NG; DigiKey CP1-3535NG-ND
J6: UART_TX; PinHeader_1x02_P2.54mm_Vertical; MPN PREC040SAAN-RC; DigiKey S1012EC-40-ND
J7: USB power jumper; PinHeader_1x02_P2.54mm_Vertical; MPN PREC040SAAN-RC; DigiKey S1012EC-40-ND
R1: 1K; R_Axial_DIN0207_L6.3mm_D2.5mm_P10.16mm_Horizontal; MPN MFR-25FBF52-1K; DigiKey 1.00KXBK-ND
R2, R5, R6: 15K; R_Axial_DIN0207_L6.3mm_D2.5mm_P10.16mm_Horizontal; MPN MFR-25FBF52-15K; DigiKey 15.0KXBK-ND
R3, R4: 220; R_Axial_DIN0207_L6.3mm_D2.5mm_P10.16mm_Horizontal; MPN RNMF14FTC220R; DigiKey S220CACT-ND
R17: 10K; R_Axial_DIN0207_L6.3mm_D2.5mm_P10.16mm_Horizontal; MPN MFR-25FBF52-10K; DigiKey 10.0KXBK-ND
R18: 100K; R_Axial_DIN0207_L6.3mm_D2.5mm_P10.16mm_Horizontal; MPN MFR-25FBF52-100K; DigiKey 100KXBK-ND
U1: Pico; RPi_Pico_SMD_TH; MPN SC0915; DigiKey 2648-SC0915CT-ND
U2: 74AHC244; DIP-20_W7.62mm; MPN SN74AHC244N; DigiKey 296-4585-5-ND
U3, U4: SN74CB3T3257; TSSOP-16_4.4x5mm_P0.65mm; MPN SN74CB3T3257PWR; DigiKey 296-17850-1-ND
U5: 74AHC14; DIP-14_W7.62mm; MPN SN74AHC14N; DigiKey 296-4550-5-ND
U6, U7: 74AHC00; DIP-14_W7.62mm; MPN SN74AHC00N; DigiKey 296-4510-5-ND
U8: APS6404L-3SQR-SN; SOIC-8_3.9x4.9mm_P1.27mm; MPN APS6404L-3SQR-SN; DigiKey 1528-4677-ND (Adafruit 4677 (64Mbit QSP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
U10: 74AHCT126; DIP-14_W7.62mm; MPN SN74AHCT126N; DigiKey 296-4659-5-ND

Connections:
+3V3: C1.1, C3.1, C4.1, C5.1, C6.1, C7.1, C8.1, C9.1, C10.1, R1.1, R2.1, R17.1, U1.36 (3V3), U2.20 (VCC), U3.16 (VCC), U4.16 (VCC), U5.14 (VCC), U6.14 (VCC), U7.14 (VCC), U8.8 (VCC); also elsewhere on the board
+5V: C2.1, D1.2 (A), J3.3 (VCC), J3.29 (VCC), R4.2, R6.1; also elsewhere on the board
+12V: J3.9 (+12V); also elsewhere on the board
-12V: J3.7 (-12V); also elsewhere on the board
/VSYS: D1.1 (K), J7.1, U1.39 (VSYS)
A0: J3.62 (BA00), U3.2 (1B1)
A1: J3.61 (BA01), U3.5 (2B1)
A2: J3.60 (BA02), U3.14 (4B1)
A3: J3.59 (BA03), U3.11 (3B1)
A4: J3.58 (BA04), U4.2 (1B1)
A5: J3.57 (BA05), U4.5 (2B1)
A6: J3.56 (BA06), U4.14 (4B1)
A7: J3.55 (BA07), U4.11 (3B1)
A8: J3.54 (BA08), U2.6 (1A2)
A9: J3.53 (BA09), U2.8 (1A3)
AD0: U1.9 (GPIO6), U3.4 (1A)
AD1: U1.10 (GPIO7), U3.7 (2A)
AD2: U1.11 (GPIO8), U3.12 (4A)
AD3: U1.12 (GPIO9), U3.9 (3A)
AD4: U1.14 (GPIO10), U4.4 (1A)
AD5: U1.15 (GPIO11), U4.7 (2A)
AD6: U1.16 (GPIO12), U4.12 (4A)
AD7: U1.17 (GPIO13), U4.9 (3A)
ADS: U1.32 (GPIO27_ADC1), U3.1 (S), U4.1 (S), U5.13
AEN: J3.42 (AEN), U7.1
BCK: U1.22 (GPIO17); also elsewhere on the board
D0: J3.40 (DB0), U3.3 (1B2)
D1: J3.39 (DB1), U3.6 (2B2)
D2: J3.38 (DB2), U3.13 (4B2)
D3: J3.37 (DB3), U3.10 (3B2)
D4: J3.36 (DB4), U4.3 (1B2)
D5: J3.35 (DB5), U4.6 (2B2)
D6: J3.34 (DB6), U4.13 (4B2)
D7: J3.33 (DB7), U4.10 (3B2)
DACK: J1.14, J1.18, R6.2, U5.11, U7.2
DACK1: J1.13, J3.17 (~DACK1)
DACK3: J1.17, J3.15 (~DACK3)
DIN: U1.21 (GPIO16); also elsewhere on the board
DRQ: J1.12, J1.16, U2.3 (2Y0)
DRQ1: J1.11, J3.18 (DRQ1)
DRQ3: J1.15, J3.16 (DRQ3)
GND: C1.2, C2.2, C3.2, C4.2, C5.2, C6.2, C7.2, C8.2, C9.2, C10.2, C11.2, H1.1, H2.1, J3.1 (GND), J3.10 (GND), J3.31 (GND), J5.S, J6.2, R5.2, R18.2, U1.3 (GND), U1.8 (GND), U1.13 (GND), U1.18 (GND), U1.23 (GND), U1.28 (GND), U1.33 (AGND), U1.38 (GND), U1.42 (GND), U2.4 (1A1), U2.10 (GND), U2.11 (2A3), U2.13 (2A2), U3.8 (GND), U4.8 (GND), U5.7 (GND), U6.7 (GND), U7.7 (GND), U8.3 (SIO2), U8.4 (VSS), U8.7 (SIO3), U10.2, U10.5; also elsewhere on the board
IRQ: J1.2, J1.4, J1.6, J1.8, J1.10, U2.5 (2Y1)
IRQ2: J1.1, J3.4 (IRQ2)
IRQ3: J1.3, J3.25 (IRQ3)
IRQ4: J1.5, J3.24 (IRQ4)
IRQ5: J1.7, J3.23 (IRQ5)
IRQ7: J1.9, J3.21 (IRQ7)
I/OCHRDY: J3.41 (IO_READY), U10.3
LRCK: U1.24 (GPIO18); also elsewhere on the board
unnamed: FB1.1, R3.2
unnamed: FB1.2, J5.T
unnamed: FB2.1, R4.1
unnamed: FB2.2, J5.R
unnamed: J7.2, U1.40 (VBUS)
unnamed: R3.1, U10.6
unnamed: U5.4, U6.9
unnamed: U5.6, U6.5
unnamed: U5.12, U6.1
unnamed: U6.4, U6.10, U7.3
unnamed: U6.3, U6.12
RA8: U1.19 (GPIO14), U2.14 (1Y2)
RA9: U1.20 (GPIO15), U2.12 (1Y3)
RDRQ: U1.29 (GPIO22), U2.17 (2A0)
RESET: J3.2 (RESET), R5.1, U5.9; also elsewhere on the board
RIRQ: U1.27 (GPIO21), U2.15 (2A1)
RTC: U1.26 (GPIO20), U2.18 (1Y0)
RUN: C11.1, R1.2, U1.30 (RUN), U5.8, U6.13
SPI_RX: U1.1 (GPIO0), U8.2 (SO/SIO)
SPI_SCK: U1.4 (GPIO2), U8.6 (SCLK)
SPI_TX: U1.5 (GPIO3), U8.5 (SI/SIO)
TC: J3.27 (TC), U2.2 (1A0)
UART_TX: J6.1, R17.2, U1.34 (GPIO28_ADC2), U5.1
~BUSOE: R2.2, U2.1 (1OE), U2.19 (2OE), U3.15 (~OE), U4.15 (~OE), U6.2, U6.11
~IOR: J3.14 (~IOR), U5.3
~IOW: J3.13 (~IOW), U5.5
~MIDI_DRV: U5.2, U10.4; also elsewhere on the board
~RDACK: U1.25 (GPIO19), U5.10
~RIOR: U1.7 (GPIO5), U6.8
~RIOW: U1.6 (GPIO4), U6.6
~RI/OCHRDY: R18.1, U1.31 (GPIO26_ADC0), U10.1
~SPI_CS: U1.2 (GPIO1), U8.1 (~CE)

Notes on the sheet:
Saves PIO instructions due to JMP limitations
DECOUPLING CAPS
I2S DAC
Disables ~{IOR} and ~{IOW} signals when other DMA in system happens
Latches ~{BUSOE} low after ADS is toggled for the first time, sets high on RESET
MIDI/DEBUG OUT
MOUNTING
MISC LEVEL SHIFT/BUFFER
IRQ/DMA SETTING
DACK INVERT
ADDR/DATA MUX/DEMUX
SAMPLE RAM
AEN IO MASKING
ISA AND RASPBERRY PI PICO
RESET CIRCUIT
I/OCHRDY OPEN DRAIN
74xx LOGIC PWR
U10 = 74AHCT126 @ +5V (TTL inputs take 3V3 logic) Pseudo open-drain: A=GND, OE=1 -> low, OE=0 -> Hi-Z Gates C/D + power unit: "Wavetable & line out" sheet
THT board: the GY-PCM5102 module option of v1.2 (I2S_DAC1/J4) is now J10 on the DAC sheet: it feeds the Waveblaster mixer instead of U9.
THT board: J2 (ISA debug header, never fitted) is removed - its pads blocked the ISA routing.

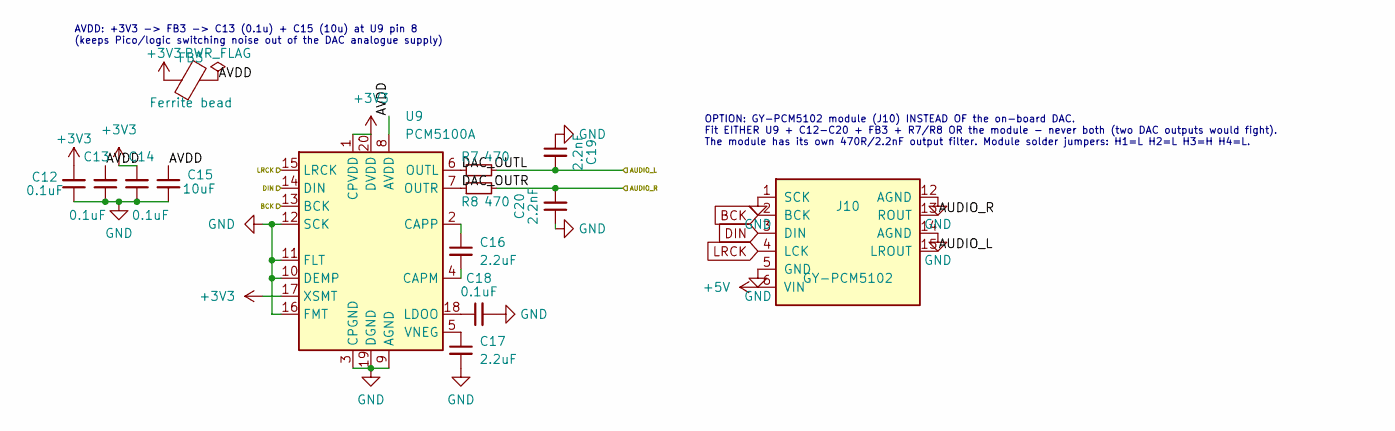
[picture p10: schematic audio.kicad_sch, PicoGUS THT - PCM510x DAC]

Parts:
C12, C13, C14, C18: 0.1uF; C_Disc_D5.0mm_W2.5mm_P5.00mm; MPN RDER71H104K0M1H03A; DigiKey 490-9144-1-ND
C15: 10uF; C_Disc_D5.0mm_W2.5mm_P5.00mm; MPN RCER71H106MWM1H03A; DigiKey 490-7518-1-ND
C16, C17: 2.2uF; C_Disc_D5.0mm_W2.5mm_P5.00mm; MPN FG24X7R1H225KRT06; DigiKey 445-173378-1-ND
C19, C20: 2.2nF; C_Disc_D5.0mm_W2.5mm_P5.00mm; MPN FG28C0G1H222JNT06; DigiKey 445-173487-1-ND
FB3: Ferrite bead; R_Axial_DIN0309_L9.0mm_D3.2mm_P12.70mm_Horizontal; MPN 2743002112; DigiKey 1934-1477-1-ND
J10: GY-PCM5102; GY-PCM5102_Module; MPN GY-PCM5102
R7, R8: 470; R_Axial_DIN0207_L6.3mm_D2.5mm_P10.16mm_Horizontal; MPN RNMF14FTC470R; DigiKey S470CACT-ND
U9: PCM5100A; TSSOP-20_4.4x6.5mm_P0.65mm; MPN PCM5100APWR; DigiKey 296-36705-1-ND

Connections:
+3V3: C12.2, C14.2, FB3.1, U9.1 (CPVDD), U9.17 (XSMT), U9.20 (DVDD); also elsewhere on the board
+5V: J10.6 (VIN); also elsewhere on the board
/PCM5100 audio/AUDIO_L: C19.2, R7.2; also elsewhere on the board
/PCM5100 audio/AUDIO_R: C20.2, R8.2; also elsewhere on the board
/PCM5100 audio/AVDD: C13.2, C15.1, FB3.2, U9.8 (AVDD)
BCK: J10.2 (BCK), U9.13 (BCK); also elsewhere on the board
DIN: J10.3 (DIN), U9.14 (DIN); also elsewhere on the board
GND: C12.1, C13.1, C14.1, C15.2, C17.2, C18.2, C19.1, C20.1, J10.1 (SCK), J10.5 (GND), J10.12 (AGND), J10.14 (AGND), U9.3 (CPGND), U9.9 (AGND), U9.10 (DEMP), U9.11 (FLT), U9.12 (SCK), U9.16 (FMT), U9.19 (DGND); also elsewhere on the board
LRCK: J10.4 (LCK), U9.15 (LRCK); also elsewhere on the board
unnamed: C16.2, U9.4 (CAPM)
unnamed: C16.1, U9.2 (CAPP)
unnamed: C18.1, U9.18 (LDOO)
unnamed: C17.1, U9.5 (VNEG)

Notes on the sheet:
AVDD: +3V3 -> FB3 -> C13 (0.1u) + C15 (10u) at U9 pin 8 (keeps Pico/logic switching noise out of the DAC analogue supply)
OPTION: GY-PCM5102 module (J10) INSTEAD OF the on-board DAC. Fit EITHER U9 + C12-C20 + FB3 + R7/R8 OR the module - never both (two DAC outputs would fight). The module has its own 470R/2.2nF output filter. Module solder jumpers: H1=L H2=L H3=H H4=L.

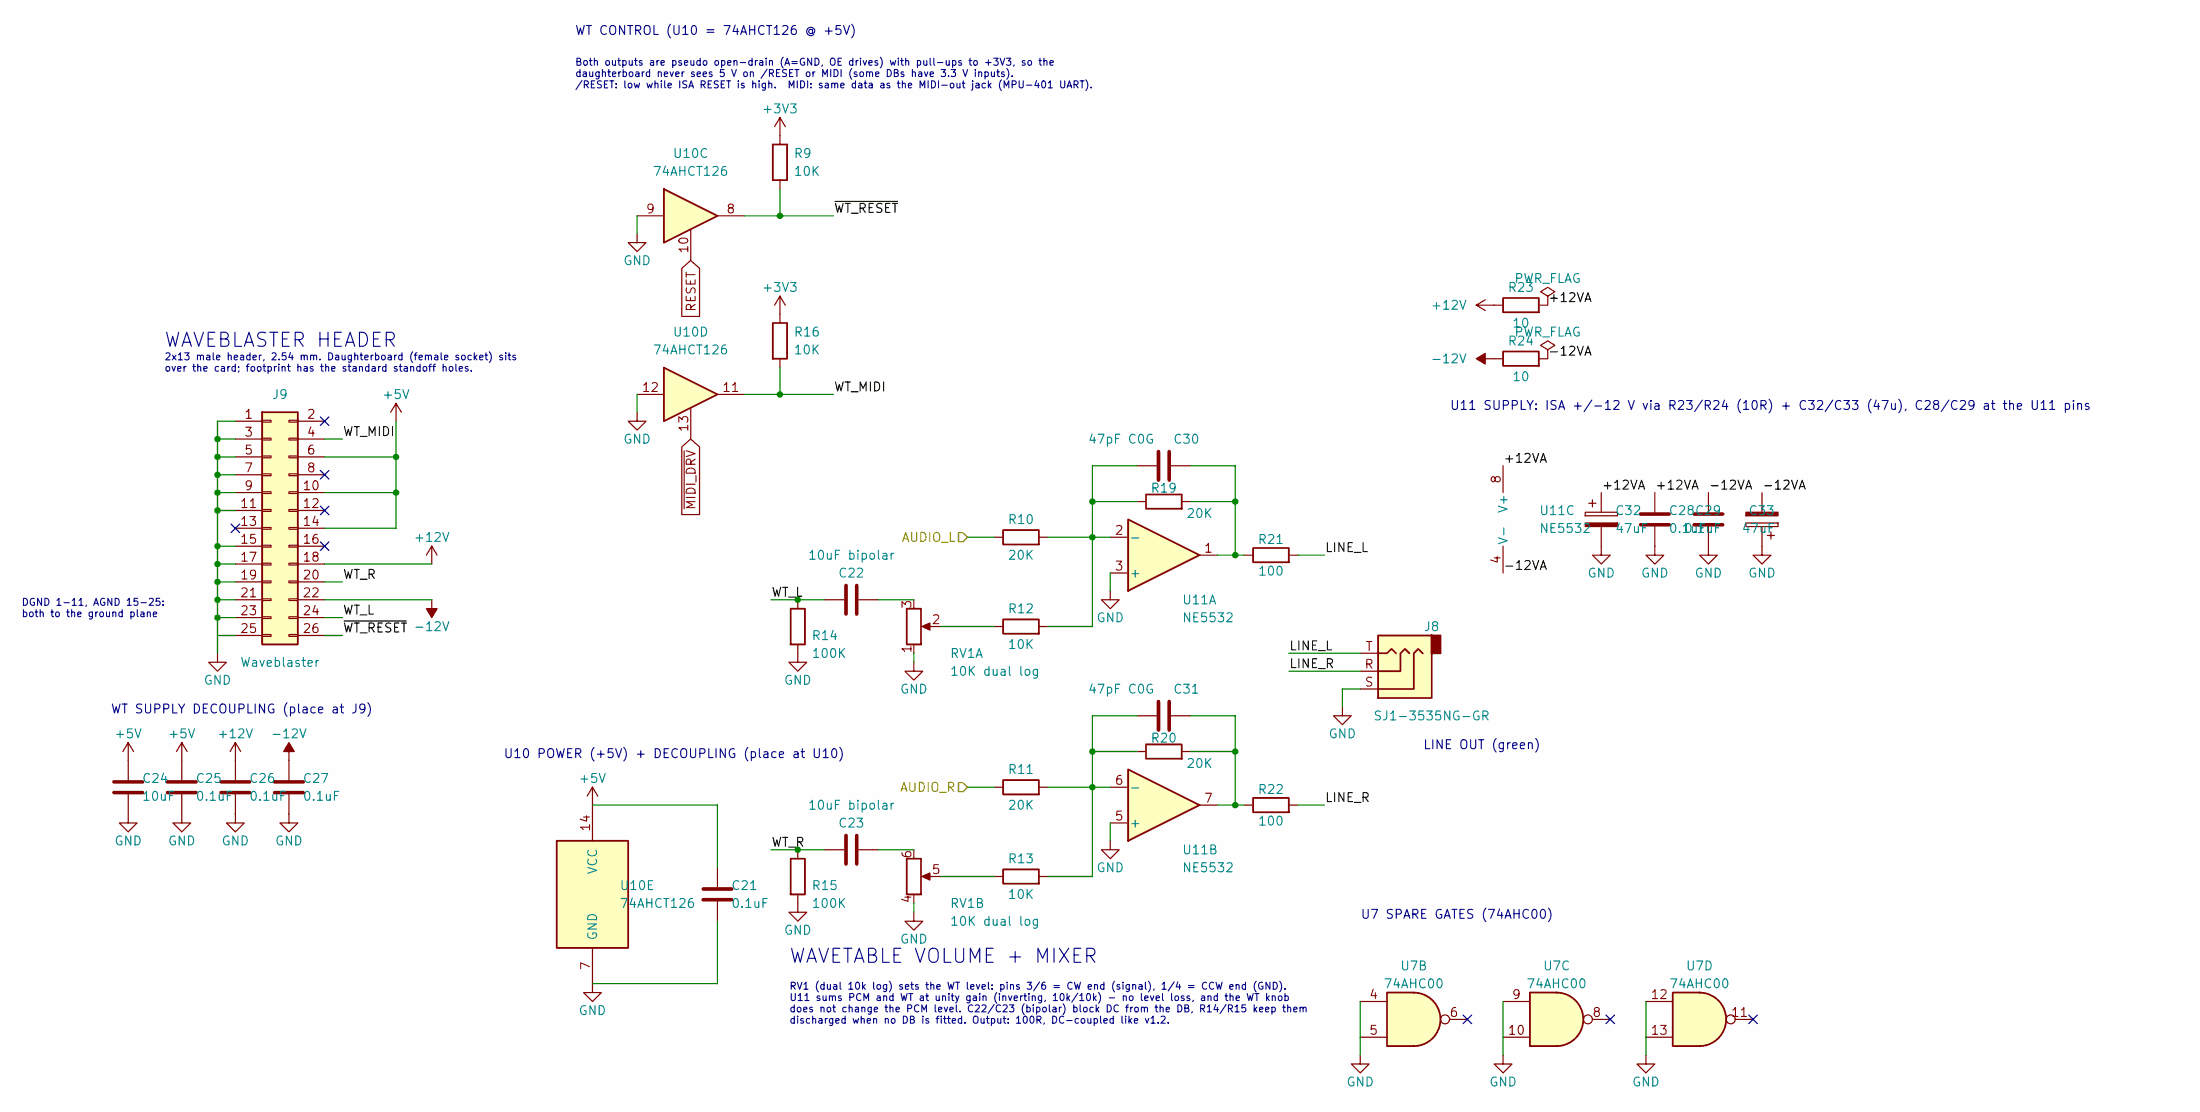
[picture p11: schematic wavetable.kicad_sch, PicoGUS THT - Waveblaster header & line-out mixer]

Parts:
C21, C25, C26, C27, C28, C29: 0.1uF; C_Disc_D5.0mm_W2.5mm_P5.00mm; MPN RDER71H104K0M1H03A; DigiKey 490-9144-1-ND
C22, C23: 10uF bipolar; C_Radial_D6.3mm_H11.0mm_P2.50mm; MPN ECE-A1HN100U; DigiKey P1280-ND
C24: 10uF; C_Disc_D5.0mm_W2.5mm_P5.00mm; MPN RCER71H106MWM1H03A; DigiKey 490-7518-1-ND
C30, C31: 47pF C0G; C_Disc_D5.0mm_W2.5mm_P5.00mm; MPN K470J15C0GF5TH5; DigiKey BC1038CT-ND
C32, C33: 47uF; CP_Radial_D5.0mm_P2.00mm; MPN 35YXJ47M5X11; DigiKey 1189-2919-ND
J8: SJ1-3535NG-GR; Jack_3.5mm_CUI_SJ1-3535NG_Horizontal; MPN SJ1-3535NG-GR; DigiKey CP1-3535NG-GR-ND
J9: Waveblaster; Wavetable; MPN PEC13DAAN; DigiKey 35-PEC13DAAN-ND
R9, R12, R13, R16: 10K; R_Axial_DIN0207_L6.3mm_D2.5mm_P10.16mm_Horizontal; MPN MFR-25FBF52-10K; DigiKey 10.0KXBK-ND
R10, R11, R19, R20: 20K; R_Axial_DIN0207_L6.3mm_D2.5mm_P10.16mm_Horizontal; MPN MFR-25FBF52-20K; DigiKey 20.0KXBK-ND
R14, R15: 100K; R_Axial_DIN0207_L6.3mm_D2.5mm_P10.16mm_Horizontal; MPN MFR-25FBF52-100K; DigiKey 100KXBK-ND
R21, R22: 100; R_Axial_DIN0207_L6.3mm_D2.5mm_P10.16mm_Horizontal; MPN MFR-25FBF52-100R; DigiKey 100XBK-ND
R23, R24: 10; R_Axial_DIN0207_L6.3mm_D2.5mm_P10.16mm_Horizontal; MPN MFR-25FBF52-10R; DigiKey 10.0XBK-ND
RV1: 10K dual log; Potentiometer_Alps_RK097_Dual_Horizontal_Switch; MPN PTD902-2020K-A103; DigiKey PTD902-2020K-A103-ND
U7: 74AHC00; DIP-14_W7.62mm; MPN SN74AHC00N; DigiKey 296-4510-5-ND
U10: 74AHCT126; DIP-14_W7.62mm; MPN SN74AHCT126N; DigiKey 296-4659-5-ND
U11: NE5532; DIP-8_W7.62mm; MPN NE5532P; DigiKey 296-1410-5-ND

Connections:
+3V3: R9.1, R16.1; also elsewhere on the board
+5V: C21.1, C24.1, C25.1, J9.6, J9.10, J9.14, U10.14 (VCC); also elsewhere on the board
+12V: C26.1, J9.18, R23.1; also elsewhere on the board
-12V: C27.1, J9.22, R24.1; also elsewhere on the board
/PCM5100 audio/AUDIO_L: R10.1; also elsewhere on the board
/PCM5100 audio/AUDIO_R: R11.1; also elsewhere on the board
/Wavetable & line out/+12VA: C28.1, C32.1, R23.2, U11.8 (V+)
/Wavetable & line out/-12VA: C29.2, C33.2, R24.2, U11.4 (V-)
/Wavetable & line out/LINE_L: J8.T, R21.2
/Wavetable & line out/LINE_R: J8.R, R22.2
/Wavetable & line out/WT_L: C22.1, J9.24, R14.1
/Wavetable & line out/WT_MIDI: J9.4, R16.2, U10.11
/Wavetable & line out/WT_R: C23.1, J9.20, R15.1
/Wavetable & line out/~WT_RESET: J9.26, R9.2, U10.8
GND: C21.2, C24.2, C25.2, C26.2, C27.2, C28.2, C29.1, C32.2, C33.1, J8.S, J9.1, J9.3, J9.5, J9.7, J9.9, J9.11, J9.15, J9.17, J9.19, J9.21, J9.23, J9.25, R14.2, R15.2, RV1.1, RV1.4, U7.4, U7.5, U7.9, U7.10, U7.12, U7.13, U10.7 (GND), U10.9, U10.12, U11.3 (+), U11.5 (+); also elsewhere on the board
unnamed: C22.2, RV1.3
unnamed: C23.2, RV1.6
unnamed: C30.2, R19.2, R21.1, U11.1
unnamed: C31.2, R20.2, R22.1, U11.7
unnamed: R12.1, RV1.2
unnamed: R13.1, RV1.5
unnamed: C30.1, R10.2, R12.2, R19.1, U11.2 (-)
unnamed: C31.1, R11.2, R13.2, R20.1, U11.6 (-)
RESET: U10.10; also elsewhere on the board
~MIDI_DRV: U10.13; also elsewhere on the board

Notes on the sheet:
DGND 1-11, AGND 15-25: both to the ground plane
WAVEBLASTER HEADER
2x13 male header, 2.54 mm. Daughterboard (female socket) sits over the card; footprint has the standard standoff holes.
WT SUPPLY DECOUPLING (place at J9)
U10 POWER (+5V) + DECOUPLING (place at U10)
WT CONTROL (U10 = 74AHCT126 @ +5V)
Both outputs are pseudo open-drain (A=GND, OE drives) with pull-ups to +3V3, so the daughterboard never sees 5 V on /RESET or MIDI (some DBs have 3.3 V inputs). /RESET: low while ISA RESET is high. MIDI: same data as the MIDI-out jack (MPU-401 UART).
U11 SUPPLY: ISA +/-12 V via R23/R24 (10R) + C32/C33 (47u), C28/C29 at the U11 pins
WAVETABLE VOLUME + MIXER
RV1 (dual 10k log) sets the WT level: pins 3/6 = CW end (signal), 1/4 = CCW end (GND). U11 sums PCM and WT at unity gain (inverting, 10k/10k) - no level loss, and the WT knob does not change the PCM level. C22/C23 (bipolar) block DC from the DB, R14/R15 keep them discharged when no DB is fitted. Ou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
LINE OUT (green)
U7 SPARE GATES (74AHC00)

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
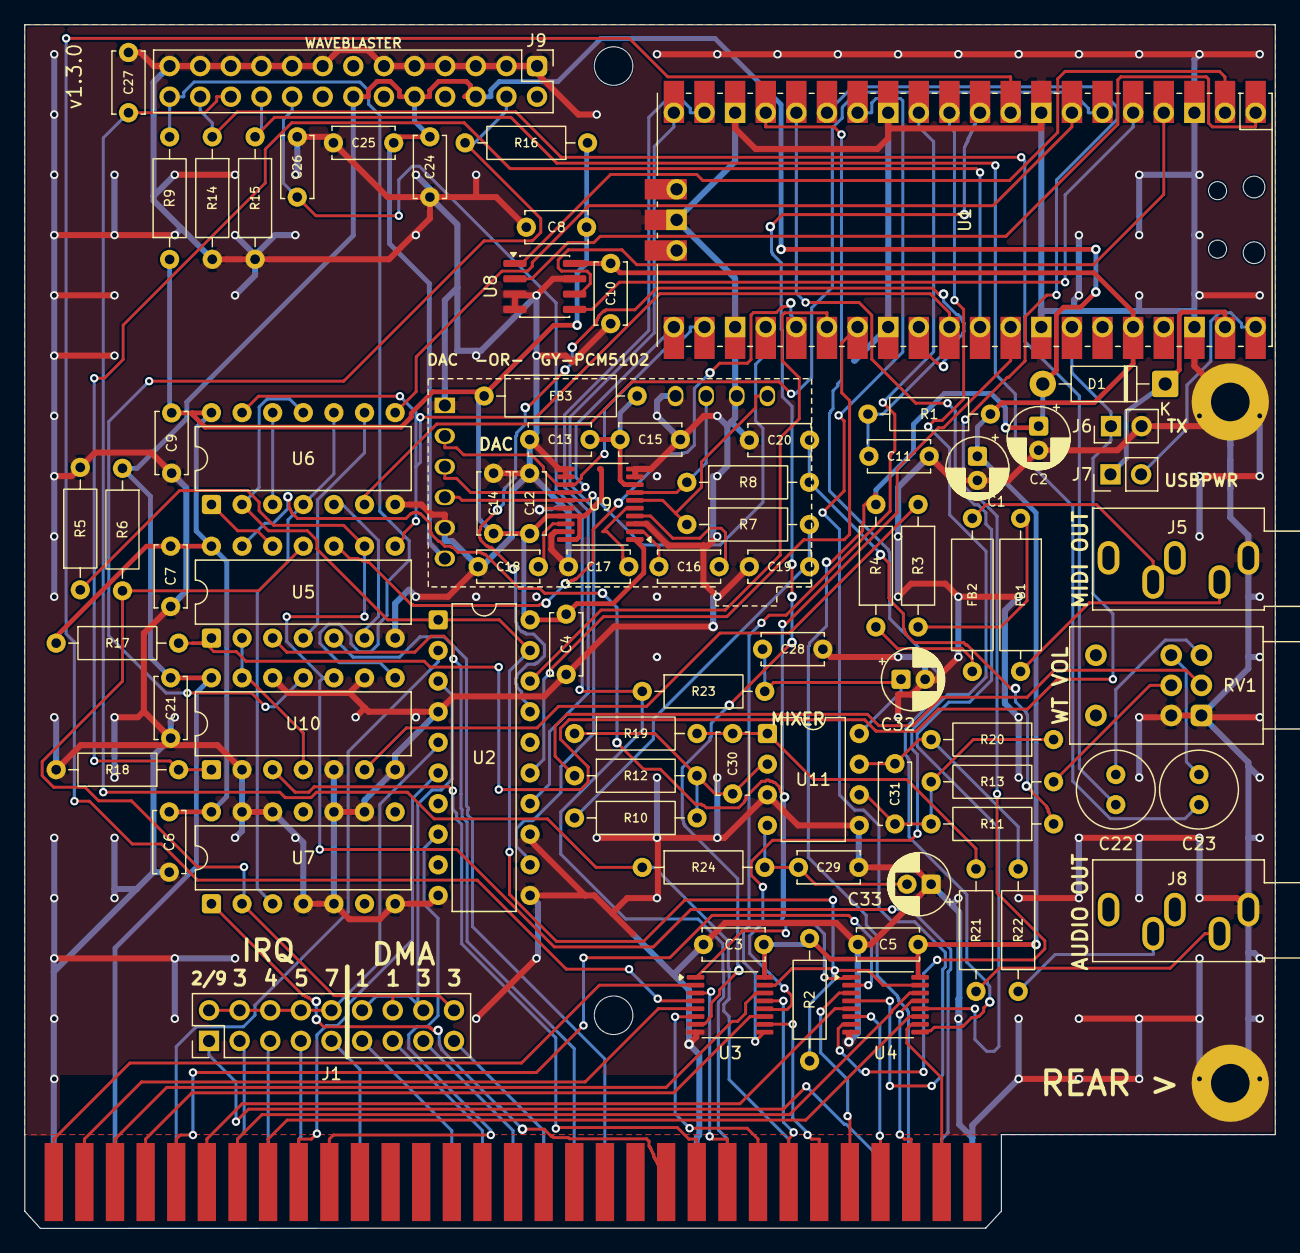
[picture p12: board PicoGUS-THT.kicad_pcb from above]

Board: 2 copper layers, 103.7 x 99.8 mm, 83 parts (0 on the bottom side), 107 nets.

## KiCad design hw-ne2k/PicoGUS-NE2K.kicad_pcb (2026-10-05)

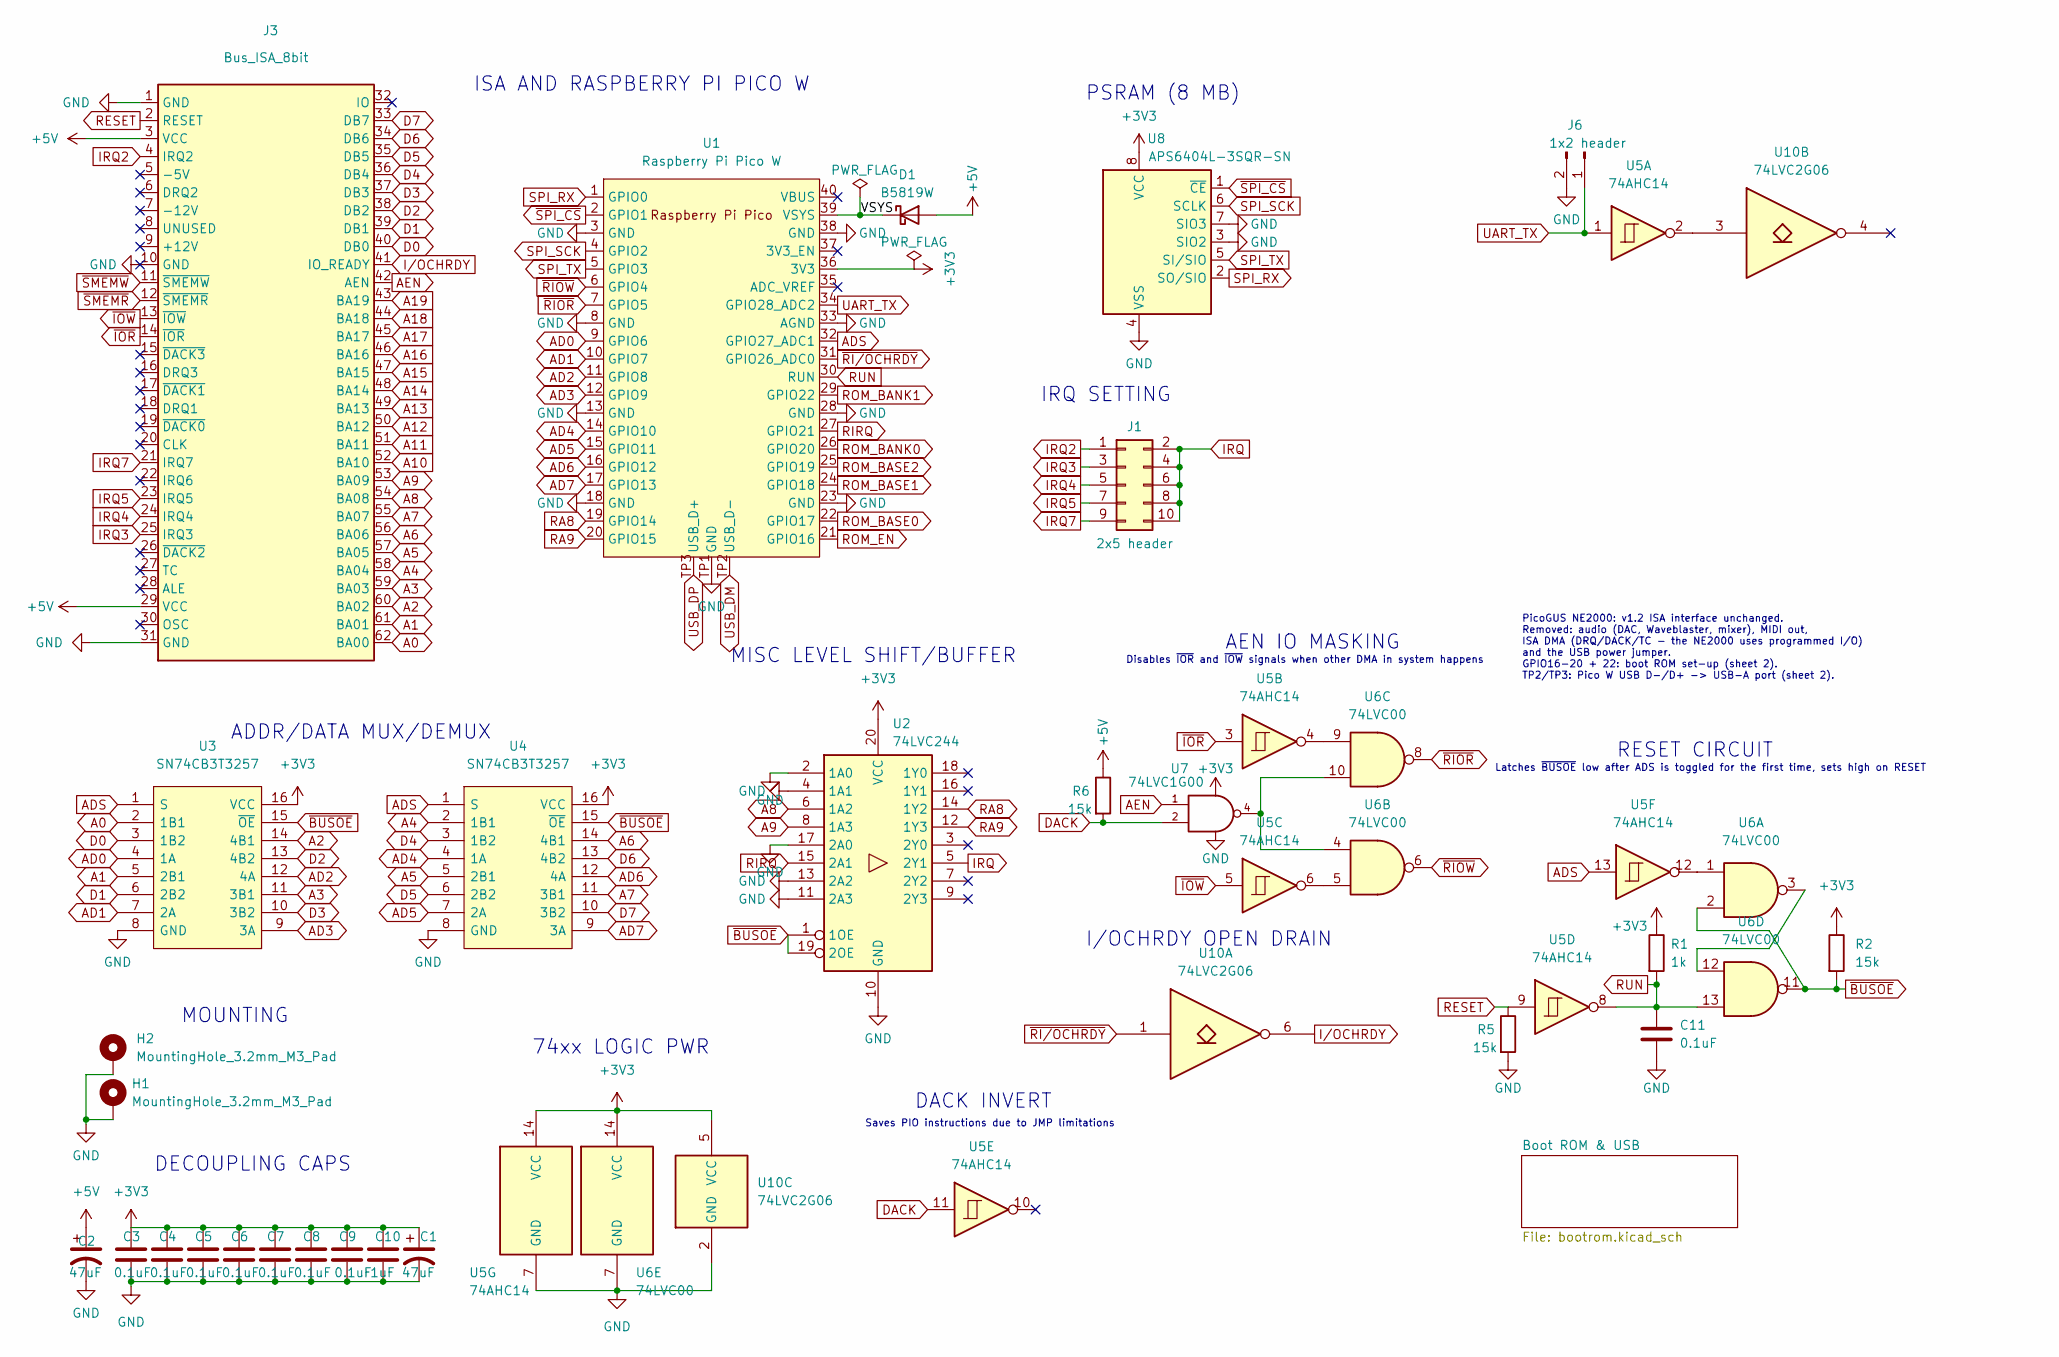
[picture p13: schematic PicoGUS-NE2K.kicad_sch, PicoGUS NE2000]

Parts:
C1, C2: 47uF; C_1206_3216Metric; MPN C3216X5R1A476M160AB; DigiKey 445-6006-1-ND
C3, C4, C5, C6, C7, C8, C9, C11: 0.1uF; C_0805_2012Metric; MPN CL21B104KBCNNNC; DigiKey 1276-1003-1-ND
C10: 1uF; C_0805_2012Metric; MPN C2012X7R1H105K125AB; DigiKey 445-7547-1-ND
D1: B5819W; D_SOD-123; MPN B5819W; DigiKey 5399-B5819WCT-ND
H1, H2: MountingHole_3.2mm_M3_Pad
J1: 2x5 header; PinHeader_2x05_P2.54mm_Vertical; MPN 10129381-910001BLF; DigiKey 10129381-910001BLF-ND
J3: Bus_ISA_8bit; BUS_PC_chamfer
J6: 1x2 header; PinHeader_1x02_P2.54mm_Vertical; MPN 77311-118-02LF; DigiKey 609-4434-ND
R1: 1k; R_0805_2012Metric; MPN RC0805FR-071KL; DigiKey 311-1.00KCRCT-ND
R2, R5, R6: 15k; R_0805_2012Metric; MPN RC0805FR-0715KL; DigiKey 311-15.0KCRCT-ND
U1: Raspberry Pi Pico W; RPi_PicoW_SMD_TH_USB; MPN SC0918; DigiKey 2648-SC0918CT-ND
U2: 74LVC244; TSSOP-20_4.4x6.5mm_P0.65mm; MPN SN74LVC244APW; DigiKey 296-26609-5-ND
U3, U4: SN74CB3T3257; TSSOP-16_4.4x5mm_P0.65mm; MPN SN74CB3T3257PWR; DigiKey 296-17850-1-ND
U5: 74AHC14; SOIC-14_3.9x8.7mm_P1.27mm; MPN 74AHC14S14-13; DigiKey 31-74AHC14S14-13CT-ND
U6: 74LVC00; SOIC-14_3.9x8.7mm_P1.27mm; MPN 74LVC00AS14-13; DigiKey 31-74LVC00AS14-13CT-ND
U7: 74LVC1G00; SOT-23-5; MPN SN74LVC1G00DBVR; DigiKey 296-9845-1-ND
U8: APS6404L-3SQR-SN; SOIC-8_3.9x4.9mm_P1.27mm; MPN APS6404L-3SQR-SN; DigiKey 1528-4677-ND
U10: 74LVC2G06; TSOP-6_1.65x3.05mm_P0.95mm; MPN SN74LVC2G06DBVR; DigiKey 296-13492-1-ND

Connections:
+3V3: C1.1, C3.1, C4.1, C5.1, C6.1, C7.1, C8.1, C9.1, C10.1, R1.1, R2.1, U1.36 (3V3), U2.20 (VCC), U3.16 (VCC), U4.16 (VCC), U5.14 (VCC), U6.14 (VCC), U7.5 (VCC), U8.8 (VCC), U10.5 (VCC)
+5V: C2.1, D1.2 (A), J3.3 (VCC), J3.29 (VCC), R6.1; also elsewhere on the board
/VSYS: D1.1 (K), U1.39 (VSYS)
A0: J3.62 (BA00), U3.2 (1B1); also elsewhere on the board
A1: J3.61 (BA01), U3.5 (2B1); also elsewhere on the board
A2: J3.60 (BA02), U3.14 (4B1); also elsewhere on the board
A3: J3.59 (BA03), U3.11 (3B1); also elsewhere on the board
A4: J3.58 (BA04), U4.2 (1B1); also elsewhere on the board
A5: J3.57 (BA05), U4.5 (2B1); also elsewhere on the board
A6: J3.56 (BA06), U4.14 (4B1); also elsewhere on the board
A7: J3.55 (BA07), U4.11 (3B1); also elsewhere on the board
A8: J3.54 (BA08), U2.6 (1A2); also elsewhere on the board
A9: J3.53 (BA09), U2.8 (1A3); also elsewhere on the board
A10: J3.52 (BA10); also elsewhere on the board
A11: J3.51 (BA11); also elsewhere on the board
A12: J3.50 (BA12); also elsewhere on the board
A13: J3.49 (BA13); also elsewhere on the board
A14: J3.48 (BA14); also elsewhere on the board
A15: J3.47 (BA15); also elsewhere on the board
A16: J3.46 (BA16); also elsewhere on the board
A17: J3.45 (BA17); also elsewhere on the board
A18: J3.44 (BA18); also elsewhere on the board
A19: J3.43 (BA19); also elsewhere on the board
AD0: U1.9 (GPIO6), U3.4 (1A)
AD1: U1.10 (GPIO7), U3.7 (2A)
AD2: U1.11 (GPIO8), U3.12 (4A)
AD3: U1.12 (GPIO9), U3.9 (3A)
AD4: U1.14 (GPIO10), U4.4 (1A)
AD5: U1.15 (GPIO11), U4.7 (2A)
AD6: U1.16 (GPIO12), U4.12 (4A)
AD7: U1.17 (GPIO13), U4.9 (3A)
ADS: U1.32 (GPIO27_ADC1), U3.1 (S), U4.1 (S), U5.13
AEN: J3.42 (AEN), U7.1
D0: J3.40 (DB0), U3.3 (1B2); also elsewhere on the board
D1: J3.39 (DB1), U3.6 (2B2); also elsewhere on the board
D2: J3.38 (DB2), U3.13 (4B2); also elsewhere on the board
D3: J3.37 (DB3), U3.10 (3B2); also elsewhere on the board
D4: J3.36 (DB4), U4.3 (1B2); also elsewhere on the board
D5: J3.35 (DB5), U4.6 (2B2); also elsewhere on the board
D6: J3.34 (DB6), U4.13 (4B2); also elsewhere on the board
D7: J3.33 (DB7), U4.10 (3B2); also elsewhere on the board
DACK: R6.2, U5.11, U7.2
GND: C1.2, C2.2, C3.2, C4.2, C5.2, C6.2, C7.2, C8.2, C9.2, C10.2, C11.2, H1.1, H2.1, J3.1 (GND), J3.10 (GND), J3.31 (GND), J6.2, R5.2, U1.3 (GND), U1.8 (GND), U1.13 (GND), U1.18 (GND), U1.23 (GND), U1.28 (GND), U1.33 (AGND), U1.38 (GND), U1.TP1 (GND), U2.2 (1A0), U2.4 (1A1), U2.10 (GND), U2.11 (2A3), U2.13 (2A2), U2.17 (2A0), U3.8 (GND), U4.8 (GND), U5.7 (GND), U6.7 (GND), U7.3 (GND), U8.3 (SIO2), U8.4 (VSS), U8.7 (SIO3), U10.2 (GND); also elsewhere on the board
IRQ: J1.2, J1.4, J1.6, J1.8, J1.10, U2.5 (2Y1)
IRQ2: J1.1, J3.4 (IRQ2)
IRQ3: J1.3, J3.25 (IRQ3)
IRQ4: J1.5, J3.24 (IRQ4)
IRQ5: J1.7, J3.23 (IRQ5)
IRQ7: J1.9, J3.21 (IRQ7)
I/OCHRDY: J3.41 (IO_READY), U10.6
unnamed: U5.4, U6.9
unnamed: U5.6, U6.5
unnamed: U5.12, U6.1
unnamed: U6.4, U6.10, U7.4
unnamed: U6.3, U6.12
unnamed: U5.2, U10.3
RA8: U1.19 (GPIO14), U2.14 (1Y2)
RA9: U1.20 (GPIO15), U2.12 (1Y3)
RESET: J3.2 (RESET), R5.1, U5.9
RIRQ: U1.27 (GPIO21), U2.15 (2A1)
ROM_BANK0: U1.26 (GPIO20); also elsewhere on the board
ROM_BANK1: U1.29 (GPIO22); also elsewhere on the board
ROM_BASE0: U1.22 (GPIO17); also elsewhere on the board
ROM_BASE1: U1.24 (GPIO18); also elsewhere on the board
ROM_BASE2: U1.25 (GPIO19); also elsewhere on the board
ROM_EN: U1.21 (GPIO16); also elsewhere on the board
RUN: C11.1, R1.2, U1.30 (RUN), U5.8, U6.13
SPI_RX: U1.1 (GPIO0), U8.2 (SO/SIO)
SPI_SCK: U1.4 (GPIO2), U8.6 (SCLK)
SPI_TX: U1.5 (GPIO3), U8.5 (SI/SIO)
UART_TX: J6.1, U1.34 (GPIO28_ADC2), U5.1
USB_DM: U1.TP2 (USB_D-); also elsewhere on the board
USB_DP: U1.TP3 (USB_D+); also elsewhere on the board
~BUSOE: R2.2, U2.1 (1OE), U2.19 (2OE), U3.15 (~OE), U4.15 (~OE), U6.2, U6.11
~IOR: J3.14 (~IOR), U5.3
~IOW: J3.13 (~IOW), U5.5
~RIOR: U1.7 (GPIO5), U6.8
~RIOW: U1.6 (GPIO4), U6.6
~RI/OCHRDY: U1.31 (GPIO26_ADC0), U10.1
~SMEMR: J3.12 (~SMEMR); also elsewhere on the board
~SMEMW: J3.11 (~SMEMW); also elsewhere on the board
~SPI_CS: U1.2 (GPIO1), U8.1 (~CE)

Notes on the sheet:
Saves PIO instructions due to JMP limitations
DECOUPLING CAPS
Disables ~{IOR} and ~{IOW} signals when other DMA in system happens
Latches ~{BUSOE} low after ADS is toggled for the first time, sets high on RESET
MOUNTING
MISC LEVEL SHIFT/BUFFER
IRQ SETTING
DACK INVERT
ADDR/DATA MUX/DEMUX
PSRAM (8 MB)
AEN IO MASKING
ISA AND RASPBERRY PI PICO W
RESET CIRCUIT
I/OCHRDY OPEN DRAIN
74xx LOGIC PWR
PicoGUS NE2000: v1.2 ISA interface unchanged. Removed: audio (DAC, Waveblaster, mixer), MIDI out, ISA DMA (DRQ/DACK/TC - the NE2000 uses programmed I/O) and the USB power jumper. GPIO16-20 + 22: boot ROM set-up (sheet 2). TP2/TP3: Pico W USB D-/D+ -> USB-A port (sheet 2).

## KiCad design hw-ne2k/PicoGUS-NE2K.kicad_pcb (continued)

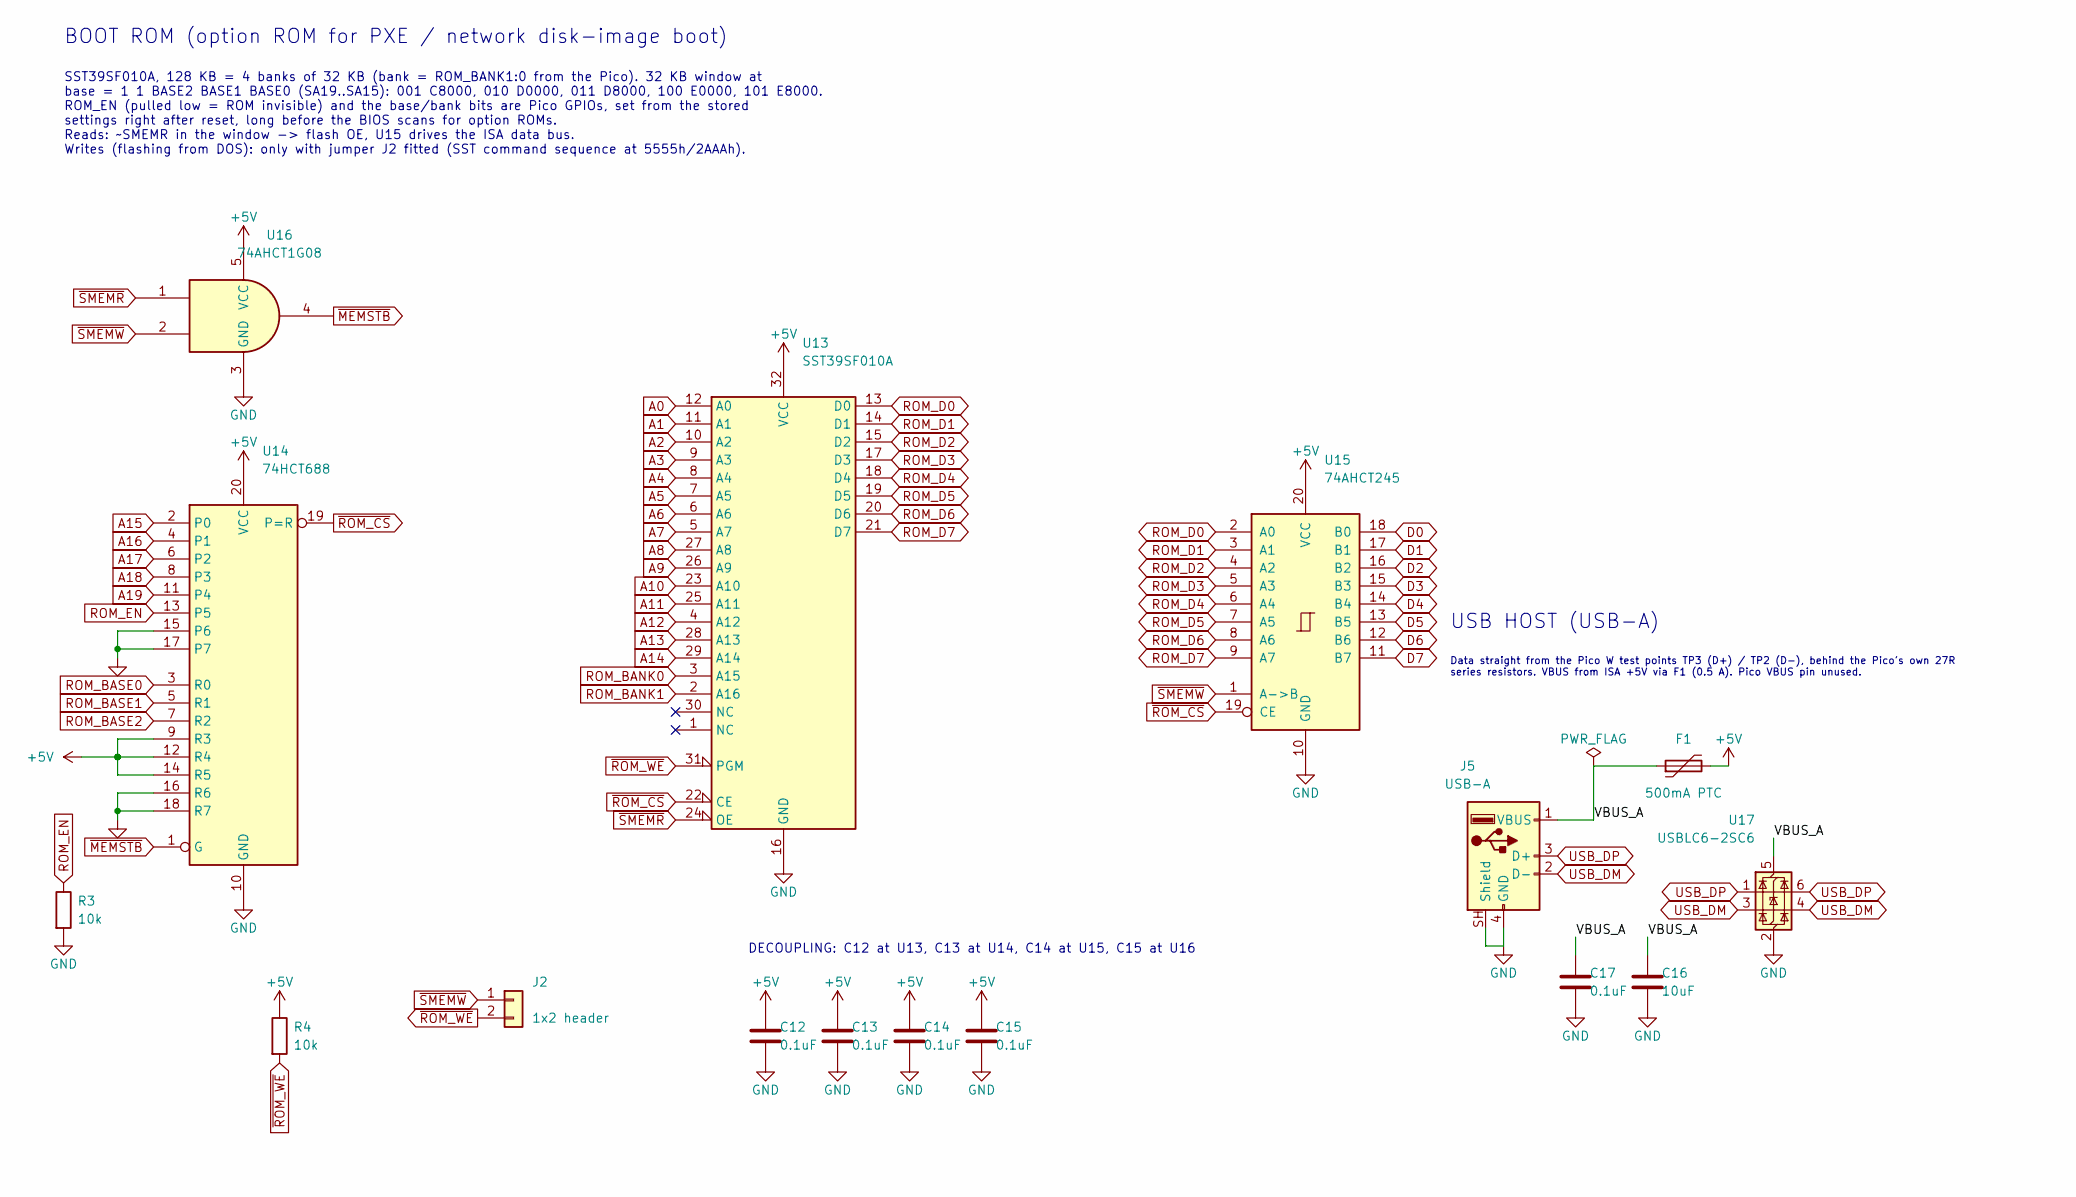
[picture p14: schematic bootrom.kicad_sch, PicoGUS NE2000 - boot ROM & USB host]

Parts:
C12, C13, C14, C15, C17: 0.1uF; C_0805_2012Metric; MPN CL21B104KBCNNNC; DigiKey 1276-1003-1-ND
C16: 10uF; C_1206_3216Metric; MPN CL31A106KAHNNNE; DigiKey 1276-1075-1-ND
F1: 500mA PTC; Fuse_1206_3216Metric; MPN MF-NSMF050-2; DigiKey MF-NSMF050-2CT-ND
J2: 1x2 header; PinHeader_1x02_P2.54mm_Vertical; MPN 77311-118-02LF; DigiKey 609-4434-ND
J5: USB-A; USB_A_Molex_67643_Horizontal; MPN 0676432910; DigiKey WM11258-ND
R3, R4: 10k; R_0805_2012Metric; MPN RC0805FR-0710KL; DigiKey 311-10.0KCRCT-ND
U13: SST39SF010A; PLCC-32_11.4x14.0mm_P1.27mm; MPN SST39SF010A-70-4C-NHE; DigiKey SST39SF010A-70-4C-NHE-ND
U14: 74HCT688; SOIC-20W_7.5x12.8mm_P1.27mm; MPN CD74HCT688M96; DigiKey 296-24357-1-ND
U15: 74AHCT245; TSSOP-20_4.4x6.5mm_P0.65mm; MPN SN74AHCT245PWR; DigiKey 296-1118-1-ND
U16: 74AHCT1G08; SOT-23-5; MPN SN74AHCT1G08DBVR; DigiKey 296-1113-1-ND
U17: USBLC6-2SC6; SOT-23-6; MPN USBLC6-2SC6; DigiKey 497-5235-1-ND

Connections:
+5V: C12.1, C13.1, C14.1, C15.1, F1.2, R4.1, U13.32 (VCC), U14.9 (R3), U14.12 (R4), U14.14 (R5), U14.20 (VCC), U15.20 (VCC), U16.5 (VCC); also elsewhere on the board
/Boot ROM & USB/VBUS_A: C16.1, C17.1, F1.1, J5.1 (VBUS), U17.5 (VBUS)
A0: U13.12 (A0); also elsewhere on the board
A1: U13.11 (A1); also elsewhere on the board
A2: U13.10 (A2); also elsewhere on the board
A3: U13.9 (A3); also elsewhere on the board
A4: U13.8 (A4); also elsewhere on the board
A5: U13.7 (A5); also elsewhere on the board
A6: U13.6 (A6); also elsewhere on the board
A7: U13.5 (A7); also elsewhere on the board
A8: U13.27 (A8); also elsewhere on the board
A9: U13.26 (A9); also elsewhere on the board
A10: U13.23 (A10); also elsewhere on the board
A11: U13.25 (A11); also elsewhere on the board
A12: U13.4 (A12); also elsewhere on the board
A13: U13.28 (A13); also elsewhere on the board
A14: U13.29 (A14); also elsewhere on the board
A15: U14.2 (P0); also elsewhere on the board
A16: U14.4 (P1); also elsewhere on the board
A17: U14.6 (P2); also elsewhere on the board
A18: U14.8 (P3); also elsewhere on the board
A19: U14.11 (P4); also elsewhere on the board
D0: U15.18 (B0); also elsewhere on the board
D1: U15.17 (B1); also elsewhere on the board
D2: U15.16 (B2); also elsewhere on the board
D3: U15.15 (B3); also elsewhere on the board
D4: U15.14 (B4); also elsewhere on the board
D5: U15.13 (B5); also elsewhere on the board
D6: U15.12 (B6); also elsewhere on the board
D7: U15.11 (B7); also elsewhere on the board
GND: C12.2, C13.2, C14.2, C15.2, C16.2, C17.2, J5.4 (GND), J5.SH (Shield), R3.2, U13.16 (GND), U14.10 (GND), U14.15 (P6), U14.16 (R6), U14.17 (P7), U14.18 (R7), U15.10 (GND), U16.3 (GND), U17.2 (GND); also elsewhere on the board
ROM_BANK0: U13.3 (A15); also elsewhere on the board
ROM_BANK1: U13.2 (A16); also elsewhere on the board
ROM_BASE0: U14.3 (R0); also elsewhere on the board
ROM_BASE1: U14.5 (R1); also elsewhere on the board
ROM_BASE2: U14.7 (R2); also elsewhere on the board
ROM_D0: U13.13 (D0), U15.2 (A0)
ROM_D1: U13.14 (D1), U15.3 (A1)
ROM_D2: U13.15 (D2), U15.4 (A2)
ROM_D3: U13.17 (D3), U15.5 (A3)
ROM_D4: U13.18 (D4), U15.6 (A4)
ROM_D5: U13.19 (D5), U15.7 (A5)
ROM_D6: U13.20 (D6), U15.8 (A6)
ROM_D7: U13.21 (D7), U15.9 (A7)
ROM_EN: R3.1, U14.13 (P5); also elsewhere on the board
USB_DM: J5.2 (D-), U17.3 (I/O2), U17.4 (I/O2); also elsewhere on the board
USB_DP: J5.3 (D+), U17.1 (I/O1), U17.6 (I/O1); also elsewhere on the board
~MEMSTB: U14.1 (G), U16.4
~ROM_CS: U13.22 (CE), U14.19 (P=R), U15.19 (CE)
~ROM_WE: J2.2, R4.2, U13.31 (PGM)
~SMEMR: U13.24 (OE), U16.1; also elsewhere on the board
~SMEMW: J2.1, U15.1 (A->B), U16.2; also elsewhere on the board

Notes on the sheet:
DECOUPLING: C12 at U13, C13 at U14, C14 at U15, C15 at U16
BOOT ROM (option ROM for PXE / network disk-image boot)
SST39SF010A, 128 KB = 4 banks of 32 KB (bank = ROM_BANK1:0 from the Pico). 32 KB window at base = 1 1 BASE2 BASE1 BASE0 (SA19..SA15): 001 C8000, 010 D0000, 011 D8000, 100 E0000, 101 E8000. ROM_EN (pulled low = ROM invisible) and the base/bank bits are Pico GPIOs, set from the stored settings right 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
USB HOST (USB-A)
Data straight from the Pico W test points TP3 (D+) / TP2 (D-), behind the Pico's own 27R series resistors. VBUS from ISA +5V via F1 (0.5 A). Pico VBUS pin unused.

Board: 2 copper layers, 46 parts (0 on the bottom side), 94 nets, no tracks yet.

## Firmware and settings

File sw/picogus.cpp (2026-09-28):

/*
 *  Copyright (C) 2022-2024  Ian Scott
 *
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
 *  You should have received a copy of the GNU General Public License along
 *  with this program; if not, write to the Free Software Foundation, Inc.,
 *  51 Franklin Street, Fifth Floor, Boston, MA 02110-1301, USA.
 */

#include <string.h>
#include "include/pg_debug.h"
#include "pico/stdlib.h"
#include "pico/multicore.h"
#include "hardware/adc.h"
#include "hardware/pio.h"
#include "hardware/irq.h"
#include "hardware/vreg.h"
#include "hardware/clocks.h"

#include "system/platform.h"
#include "system/overclock.h"
#include "system/pico_reflash.h"
#include "system/flash_settings.h"

// For multifw
#include "hardware/watchdog.h"
#include "hardware/structs/watchdog.h"

#include "../common/picogus.h"

board_type_t BOARD_TYPE;

#ifdef PSRAM
#include "psram_spi.h"
psram_spi_inst_t psram_spi;
psram_spi_inst_t* async_spi_inst;
#endif
#include "isa_io.pio.h"

#ifdef ASYNC_UART
#include "stdio_async_uart.h"
#endif 
// UART_TX_PIN is defined in isa_io.pio.h
#define UART_RX_PIN (-1)
#define UART_ID     uart0
#define BAUD_RATE   230400

uint LED_PIN;

#include "M62429/M62429.h"
M62429* m62429;


#ifdef SOUND_SB
#ifdef SOUND_WSS
#include "ad1848/ad1848.h"
static constexpr uint16_t wss_port_test = 0x13;
static uint8_t wss_config = 0b00001010; // DMA 1 and IRQ 7
#else
#include "sbdsp/sbdsp.h"
#endif
static uint16_t sb_port_test;
#endif
#ifdef SOUND_OPL
#include "opl.h"
void play_adlib(void);
#if OPL_CMD_BUFFER
#include "include/cmd_buffers.h"
cms_buffer_t opl_cmd_buffer = { {0}, 0, 0 };
#else
extern "C" void OPL_Pico_WriteRegister(unsigned int reg_num, unsigned int value);
static uint16_t opl_addr;
#endif // OPL_CMD_BUFFER
#if AUDIO_CALLBACK_CORE0
extern void audio_sample_handler(void);
#endif // AUDIO_CALLBACK_CORE0
#endif // SOUND_OPL

#ifdef CDROM
static uint16_t cdrom_port_test;
extern "C" void MKE_WRITE(uint16_t address, uint8_t value);
extern "C" uint8_t MKE_READ(uint16_t address);
extern "C" void mke_init();

#include "cdrom/cdrom.h"
#include "cdrom/cdrom_image_manager.h"
cdrom_t cdrom;

static uint32_t cur_read_idx;
#endif

#ifdef SOUND_GUS
#include "gus/gus-x.cpp"
#include "isa/isa_dma.h"
dma_inst_t dma_config;
static uint16_t gus_port_test;
void play_gus(void);
#endif


#ifdef SOUND_MPU
#include "mpu401/export.h"
#ifdef MPU_ONLY
void play_mpu(void);
#endif
#endif

#if SOUND_TANDY || SOUND_CMS
#include "include/cmd_buffers.h"
#include "square/square.h"
void play_psg(void);
#endif
#if SOUND_TANDY
tandy_buffer_t tandy_buffer = { {0}, 0, 0 };
#endif
#if SOUND_CMS
static uint8_t cms_detect = 0xFF;
cms_buffer_t cms_buffer = { {0}, 0, 0 };
#endif


#ifdef NE2000
extern "C" {
#include "ne2000/ne2000.h"
}
void play_ne2000(void);
#endif


#ifdef USB_JOYSTICK
#include "usb_hid/joy.h"
extern "C" joystate_struct_t joystate_struct;
uint8_t joystate_bin;
#include "hardware/pwm.h"
#endif
#ifdef USB_MOUSE
#include "mouse/8250uart.h"
#include "mouse/sermouse.h"
#endif
#ifdef USB_ONLY
void play_usb(void);
#endif

#if SOUND_GUS || SOUND_SB || SOUND_OPL || CDROM || SOUND_TANDY || SOUND_CMS
#include "audio/volctrl.h"
#endif


// PicoGUS control and data ports
static bool control_active = false;
static uint8_t sel_reg = 0;
static uint32_t cur_read = 0;
static uint32_t cur_write = 0;
static bool queueSaveSettings = false;
static bool queueReboot = false;

Settings settings;
void processSettings(void);

static void wtvol_from_mixer(uint8_t volume) {
    settings.Global.waveTableVolume = volume;
    if (BOARD_TYPE == PICOGUS_2) {
        m62429->setVolume(M62429_BOTH, volume);
    }
}

#define IOW_PIO_SM 0
#define IOR_PIO_SM 1

const char* firmware_string = PICO_PROGRAM_NAME " v" PICO_PROGRAM_VERSION_STRING PICOGUS_FW_STRING_SUFFIX;

static uint8_t basePort_low;
static uint8_t mouseSensitivity_low;
static uint8_t picogus_dataLatch_low;

__force_inline void select_picogus(uint8_t value) {
    // printf("select picogus %x\n", value);
    sel_reg = value;
    switch (sel_reg) {
    case CMD_MAGIC: // Magic string
    case CMD_PROTOCOL: // Protocol version
        break;
    case CMD_FWSTRING: // Firmware string
        cur_read = 0;
        break;
    case CMD_BOOTMODE: // Mode (GUS, OPL, MPU, etc...)
        break;
    case CMD_GUSPORT: // GUS Base port
    case CMD_OPLPORT: // Adlib Base port
    case CMD_SBPORT: // SB Base port
    case CMD_MPUPORT: // MPU Base port
    case CMD_TANDYPORT: // Tandy Base port
    case CMD_CMSPORT: // CMS Base port
        basePort_low = 0;
        break;
    case CMD_JOYEN: // enable joystick
        break;
    case CMD_GUSBUF: // Audio buffer size
    case CMD_GUSDMA: // DMA interval
    case CMD_GUS44K: // Force 44k
        break;
    case CMD_WTVOL: // Wavetable mixer volume
        break;
    case CMD_MPUDELAY: // MPU sysex delay
    case CMD_MPUFAKE: // MPU fake all notes off
        break;
    case CMD_OPLWAIT: // Adlib speed sensitive fix
        break;
    case CMD_MOUSEPORT:
        basePort_low = 0;
        break;
    case CMD_MOUSEPROTO:
    case CMD_MOUSERATE:
    case CMD_MOUSESEN:
        break;
    case CMD_NE2KPORT:
        basePort_low = 0;
        break;
    case CMD_WIFISSID:
        memset(settings.WiFi.ssid, 0, sizeof(settings.WiFi.ssid));
        cur_write = 0;
        break;
    case CMD_WIFIPASS:
        memset(settings.WiFi.password, 0, sizeof(settings.WiFi.password));
        cur_write = 0;
        break;
    case CMD_WIFIAPPLY:
    case CMD_WIFISTAT:
        break;
    case CMD_CDPORT: // CMS Base port
        basePort_low = 0;
        break;
    case CMD_CDLIST:
#ifdef CDROM
        if (cdrom.image_status == CD_STATUS_IDLE || cdrom.image_status == CD_STATUS_ERROR) {
            cdrom.image_status = CD_STATUS_BUSY;
            cdrom.image_command = CD_COMMAND_IMAGE_LIST;
            // puts("cdimages start");
        }
        // puts("cdimages read");
        cur_read = 0;
        cur_read_idx = 0;
#endif
        break;
    case CMD_SBTYPE:
    case CMD_SBIRQ:
    case CMD_SBDMA:
    case CMD_SBOPTS:
    case CMD_CDSTATUS:
    case CMD_CDLOAD:
    case CMD_CDAUTOADV:
    case CMD_MAINVOL:
    case CMD_OPLVOL:
    case CMD_SBVOL:
    case CMD_CDVOL:
    case CMD_GUSVOL:
    case CMD_PSGVOL:
        break;
    case CMD_CDNAME:
        cur_write = 0;
    case CMD_CDERROR:
        cur_read = 0;
        break;
    case CMD_SAVE: // Select save settings register
    case CMD_REBOOT: // Select reboot register
    case CMD_DEFAULTS: // Select reset to defaults register
        break;
    case CMD_HWTYPE: // Hardware version
        break;
    case CMD_FLASH: // Firmware write mode
        pico_firmware_start();
        break;
    default:
        control_active = false;
        break;
    }
}

__force_inline void write_picogus_low(uint8_t value) {
    switch (sel_reg) {
    case CMD_GUSPORT: // GUS Base port
    case CMD_OPLPORT: // Adlib Base port
    case CMD_SBPORT: // SB Base port
    case CMD_MPUPORT: // MPU Base port
    case CMD_TANDYPORT: // Tandy Base port
    case CMD_CMSPORT: // CMS Base port
    case CMD_MOUSEPORT:  // USB Mouse port (0 - disabled)
    case CMD_CDPORT:  // USB Mouse port (0 - disabled)
        basePort_low = value;
        break;
    case CMD_MOUSESEN:  // USB Mouse Sensitivity (8.8 fixedpoint)
        mouseSensitivity_low = value;
        break;
    }
}

__force_inline void write_picogus_high(uint8_t value) {
    switch (sel_reg) {
    case CMD_GUSPORT: // GUS Base port
        settings.GUS.basePort = (value || basePort_low) ? ((value << 8) | basePort_low) : 0xFFFF;
#ifdef SOUND_GUS
        gus_port_test = settings.GUS.basePort >> 4 | 0x10;
#endif
        break;
    case CMD_OPLPORT: // Adlib Base port
        settings.SB.oplBasePort = (value || basePort_low) ? ((value << 8) | basePort_low) : 0xFFFF;
        break;
    case CMD_SBPORT: // SB Base port
        settings.SB.basePort = (value || basePort_low) ? ((value << 8) | basePort_low) : 0xFFFF;
#ifdef SOUND_SB
        sb_port_test = settings.SB.basePort >> 4;
#endif
        break;
    case CMD_MPUPORT: // MPU Base port
        settings.MPU.basePort = (value || basePort_low) ? ((value << 8) | basePort_low) : 0xFFFF;
        break;
    case CMD_TANDYPORT: // Tandy Base port
        settings.Tandy.basePort = (value || basePort_low) ? ((value << 8) | basePort_low) : 0xFFFF;
        break;
    case CMD_CMSPORT: // CMS Base port
        settings.CMS.basePort = (value || basePort_low) ? ((value << 8) | basePort_low) : 0xFFFF;
        break;
    case CMD_JOYEN: // enable joystick
        settings.Joy.basePort = value ? 0x201u : 0xffff;
        break;
    case CMD_GUSBUF: // GUS audio buffer size
        // Value is sent by pgusinit as the size - 1, so we need to add 1 back to it
        settings.GUS.audioBuffer = value + 1;
#ifdef SOUND_GUS
        GUS_SetAudioBuffer(settings.GUS.audioBuffer);
#endif
        break;
    case CMD_GUSDMA: // GUS DMA interval
        settings.GUS.dmaInterval = value;
#ifdef SOUND_GUS
        GUS_SetDMAInterval(settings.GUS.dmaInterval);
#endif
        break;
    case CMD_GUS44K: // Force 44k output
        settings.GUS.force44k = value;
#ifdef SOUND_GUS
        GUS_SetFixed44k(settings.GUS.force44k);
#endif
        break;
    case CMD_WTVOL: // Wavetable mixer volume
        wtvol_from_mixer(value);
        break;
    case CMD_MPUDELAY: // MPU SYSEX delay
        settings.MPU.delaySysex = value;
#ifdef SOUND_MPU
        MPU401_Init(settings.MPU.delaySysex, settings.MPU.fakeAllNotesOff);
#endif
        break;
    case CMD_MPUFAKE: // MPU fake all notes off
        settings.MPU.fakeAllNotesOff = value;
#ifdef SOUND_MPU
        MPU401_Init(settings.MPU.delaySysex, settings.MPU.fakeAllNotesOff);
#endif
        break;
    case CMD_OPLWAIT: // Adlib speed sensitive fix
        settings.SB.oplSpeedSensitive = value;
        break;
        
    case CMD_SBTYPE:
        settings.SB16.sbType = value;
#ifdef SOUND_SB
        sbdsp_set_type(value);
#endif
        break;
    case CMD_SBIRQ:
        settings.SB16.irq = value;
#ifdef SOUND_SB
        sbdsp_set_irq(value);
#endif
        break;
    case CMD_SBDMA:
        settings.SB16.dma = value;
#ifdef SOUND_SB
        sbdsp_set_dma(value);
#endif
        break;
    case CMD_SBOPTS:
        settings.SB16.options = value;
#ifdef SOUND_SB
        sbdsp_set_options(value);
#endif
        break;
    case CMD_MOUSEPORT:  // USB Mouse port (0 - disabled)
        settings.Mouse.basePort = (value || basePort_low) ? ((value << 8) | basePort_low) : 0xFFFF;
        break;
    case CMD_MOUSEPROTO:  // USB Mouse protocol
        settings.Mouse.protocol = value;
#ifdef USB_MOUSE
        sermouse_set_protocol(settings.Mouse.protocol);
#endif
        break;
    case CMD_MOUSERATE:  // USB Mouse Report Rate
        settings.Mouse.reportRate = value;
#ifdef USB_MOUSE
        sermouse_set_report_rate_hz(settings.Mouse.reportRate);
#endif
        break;
    case CMD_MOUSESEN:  // USB Mouse Sensitivity (8.8 fixedpoint)
        settings.Mouse.sensitivity = (value << 8) | (mouseSensitivity_low & 0xFF);
#ifdef USB_MOUSE
        sermouse_set_sensitivity(settings.Mouse.sensitivity);
#endif
        break;
    case CMD_NE2KPORT: // NE2000 Base port
        settings.NE2K.basePort = (value || basePort_low) ? ((value << 8) | basePort_low) : 0xFFFF;
        break;
    case CMD_WIFISSID:
        settings.WiFi.ssid[cur_write++] = value;
        break;
    case CMD_WIFIPASS:
        settings.WiFi.password[cur_write++] = value;
        /* printf("%s\n", settings.WiFi.password); */
        break;
    case CMD_WIFIAPPLY:
        DBG_PRINTF("Applying wifi settings: %s %s\n", settings.WiFi.ssid, settings.WiFi.password);
#ifdef PICOW
        PG_Wifi_Connect(settings.WiFi.ssid, settings.WiFi.password);
#endif
        break;
    case CMD_WIFISTAT:
#ifdef PICOW
        multicore_fifo_push_blocking(FIFO_WIFI_STATUS);
#endif
        break;
    case CMD_CDPORT: // CD Base port
        settings.CD.basePort = (value || basePort_low) ? ((value << 8) | basePort_low) : 0xFFFF;
#ifdef CDROM
        cdrom_port_test = settings.CD.basePort >> 4;
#endif
        break;
#ifdef CDROM
    case CMD_CDLOAD: // Load CD image
        cdrom.image_data = value;
        cdrom.image_status = CD_STATUS_BUSY;
        cdrom.image_command = CD_COMMAND_IMAGE_LOAD_INDEX;
        break;
    case CMD_CDNAME:
        if (!cur_write) {
            memset(cdrom.image_path, 0, sizeof(cdrom.image_path));
        }
        cdrom.image_path[cur_write++] = value;
        if (!value) {
            cur_write = 0;
            cdrom.image_status = CD_STATUS_BUSY;
            cdrom.image_command = CD_COMMAND_IMAGE_LOAD;
        }
        break;
#endif
    case CMD_CDAUTOADV: // enable auto advance of CD image on USB reinsert
        settings.CD.autoAdvance = value;
#ifdef CDROM
        cdman_set_autoadvance(settings.CD.autoAdvance);
#endif
        break;
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
int main()
{
    busy_wait_ms(250);
    overclock_370mhz();
#ifdef ASYNC_UART
    stdio_async_uart_init_full(UART_ID, BAUD_RATE, UART_TX_PIN, UART_RX_PIN);
#else
    stdio_init_all();
#endif
    DBG_PUTS(firmware_string);
    io_rw_32 *reset_reason = &PLATFORM_CHIP_RESET_REG;
    if (*reset_reason & PLATFORM_CHIP_RESET_HAD_POWER_ON_BITS) {
        DBG_PUTS("I was reset due to power on reset or brownout detection.");
    } else if (*reset_reason & PLATFORM_CHIP_RESET_HAD_RUN_PIN_BITS) {
        DBG_PUTS("I was reset due to the RUN pin (either manually or due to ISA RESET signal)");
    } else if(*reset_reason & PLATFORM_CHIP_RESET_HAD_DEBUG_BITS) {
        DBG_PUTS("I was reset due the debug port");
    }

    // Load settings from flash
    loadSettings(&settings, true /* migrate */);
    platform_disable_xip_cache();

    // Determine board type. GPIO 29 is grounded on PicoGUS v2.0, and on a Pico, it's VSYS/3 (~1.666V)
    // GPIO 25 must be high to read GPIO 29 on the Pico W
    gpio_init(25);
    gpio_set_dir(25, GPIO_OUT);
    gpio_put(25, 1);
    adc_init();
    adc_gpio_init(29);
    // Select ADC input 3 (GPIO29)
    adc_select_input(3);
    // Read several times to let ADC stabilize
    adc_read(); adc_read(); adc_read(); adc_read(); adc_read();
    uint16_t result = adc_read();
    DBG_PRINTF("ADC value: 0x%03x... ", result);
    gpio_put(25, 0);
    gpio_deinit(25);

    if (result > 0x100) {
        DBG_PUTS("Running on Pico-based board (PicoGUS v1.1+, PicoGUS Femto)");
        // On Pico-based board (PicoGUS v1.1+, PicoGUS Femto)
#ifndef PICOW        
        LED_PIN = 1 << PICO_DEFAULT_LED_PIN;
        gpio_init(PICO_DEFAULT_LED_PIN);
        gpio_set_dir(PICO_DEFAULT_LED_PIN, GPIO_OUT);
#endif
        BOARD_TYPE = PICO_BASED;
    } else {
        // On chipdown board (PicoGUS v2.0)
        DBG_PUTS("Running on PicoGUS v2.0");
        LED_PIN = 1 << 23;
        gpio_init(23);
        gpio_set_dir(23, GPIO_OUT);
        BOARD_TYPE = PICOGUS_2;
    }
    gpio_set_mask(LED_PIN);

    if (BOARD_TYPE == PICOGUS_2) {
        // Create new interface to M62429 digital volume control
        m62429 = new M62429();
        // Data pin = GPIO24, data pin = GPIO25
#ifdef M62429_PIO
        m62429->begin(24, 25, pio1, -1);
#else
        m62429->begin(24, 25);
        // Initial volume is set in processSettings()
#endif // M62429_PIO
    }

    gpio_init(IRQ_PIN);
    gpio_set_dir(IRQ_PIN, GPIO_OUT);
    gpio_set_drive_strength(IRQ_PIN, GPIO_DRIVE_STRENGTH_12MA);

#ifdef SOUND_MPU
    DBG_PUTS("Initing MIDI UART...");
    uart_init(UART_ID, 31250);
    uart_set_translate_crlf(UART_ID, false);
    uart_set_format(UART_ID, 8, 1, UART_PARITY_NONE);
    if (BOARD_TYPE == PICO_BASED) {
        // Original hardware drives MIDI directly from RP2040. Newer HW uses an open drain inverter
        // PicoGUS v1.2 also uses an open drain but we can't detect that particular board
        gpio_set_drive_strength(UART_TX_PIN, GPIO_DRIVE_STRENGTH_12MA);
    }
    gpio_set_function(UART_TX_PIN, GPIO_FUNC_UART);
#endif // SOUND_MPU

#ifdef PSRAM_CORE0
#ifdef PSRAM
    DBG_PUTS("Initing PSRAM...");
    // Try different PSRAM strategies
    if (BOARD_TYPE == PICOGUS_2) {
        psram_spi = psram_spi_init_clkdiv(pio1, -1, psram_clkdiv /* clkdiv */, false /* fudge */);
#if TEST_PSRAM
        // Only bother to test every 97th address
        if (test_psram(&psram_spi, 97) == 1) {
            DBG_PRINTF("Default PSRAM strategy of no fudge not working, switching to fudge\n");
            psram_spi_uninit(psram_spi, false /* fudge */);
            psram_spi = psram_spi_init_clkdiv(pio1, -1, psram_clkdiv /* clkdiv */, true /* fudge */);
            if (test_psram(&psram_spi, 97) == 1) { 
                ERR_PUTS("Error: No PSRAM strategies found to work!");
                err_blink();
            }
        }
#endif // TEST_PSRAM
    } else {
        psram_spi = psram_spi_init_clkdiv(pio1, -1, psram_clkdiv /* clkdiv */, true /* fudge */);
#if TEST_PSRAM
        if (test_psram(&psram_spi, 97) == 1) {
            psram_spi_uninit(psram_spi, true /* fudge */);
            psram_spi = psram_spi_init_clkdiv(pio1, -1, psram_clkdiv /* clkdiv */, false /* fudge */);
            if (test_psram(&psram_spi, 97) == 1) { 
                ERR_PUTS("Error: No PSRAM strategies found to work!");
                err_blink();
            }
        }
#endif // TEST_PSRAM
    }
#endif // PSRAM
#endif // PSRAM_CORE0


#ifdef SOUND_SB
#ifdef SOUND_WSS
    DBG_PUTS("Initializing WSS AD1848");
#else
    DBG_PUTS("Initializing SoundBlaster DSP");
#endif
    // init actually happens on core 1 in play_adlib()
#endif // SOUND_SB
#ifdef SOUND_OPL
    DBG_PUTS("Creating OPL");
    OPL_Pico_Init(0);
    multicore_launch_core1(&play_adlib);
#endif

#ifdef CDROM
    cdrom_global_init();
    mke_init();
#endif

#ifdef SOUND_GUS
    DBG_PUTS("Creating GUS");
    GUS_OnReset();
    multicore_launch_core1(&play_gus);
#endif // SOUND_GUS

#ifdef SOUND_MPU
#ifdef MPU_ONLY
    multicore_launch_core1(&play_mpu);
#endif // MPU_ONLY
#endif // SOUND_MPU

#if (SOUND_TANDY || SOUND_CMS)
    DBG_PUTS("Creating psgsound");
    multicore_launch_core1(&play_psg);
#endif // (SOUND_TANDY || SOUND_CMS)

#ifdef NE2000
extern void PIC_ActivateIRQ(void);
extern void PIC_DeActivateIRQ(void);

    DBG_PUTS("Creating NE2000");
    multicore_launch_core1(&play_ne2000);
#endif

#ifdef USB_JOYSTICK
    // Init joystick as centered with no buttons pressed
    joystate_struct = {127, 127, 127, 127, 0xf};
    DBG_PUTS("Config joystick PWM");
    pwm_config pwm_c = pwm_get_default_config();
    // TODO better calibrate this
    pwm_config_set_clkdiv(&pwm_c, pwm_clkdiv);
    // Start the PWM off constantly looping at 0
    pwm_config_set_wrap(&pwm_c, 0);
    pwm_init(0, &pwm_c, true);
    pwm_init(1, &pwm_c, true);
    pwm_init(2, &pwm_c, true);
    pwm_init(3, &pwm_c, true);
#endif // USB_JOYSTICK
#ifdef USB_MOUSE
    DBG_PUTS("Config USB Mouse emulation");
    uartemu_init(0);
    sermouse_init(settings.Mouse.protocol, settings.Mouse.reportRate, settings.Mouse.sensitivity);
    sermouse_attach_uart();
#endif // USB_MOUSE
#ifdef USB_ONLY
    multicore_launch_core1(&play_usb);
#endif // USBONLY

    for(int i=AD0_PIN; i<(AD0_PIN + 10); ++i) {
        platform_gpio_enable_input(i);
        gpio_disable_pulls(i);
    }
    platform_gpio_enable_input(IOW_PIN);
    platform_gpio_enable_input(IOR_PIN);
    platform_gpio_enable_input(DACK_PIN);
    gpio_disable_pulls(IOW_PIN);
    gpio_disable_pulls(IOR_PIN);
    gpio_pull_down(IOCHRDY_PIN);
    gpio_set_dir(IOCHRDY_PIN, GPIO_OUT);

    DBG_PUTS("Enabling bus transceivers...");
    // waggle ADS to set BUSOE latch
    gpio_init(ADS_PIN);
    gpio_set_dir(ADS_PIN, GPIO_OUT);
    gpio_put(ADS_PIN, 1);
    busy_wait_ms(10);
    gpio_put(ADS_PIN, 0);

    DBG_PUTS("Starting ISA bus PIO...");
    // gpio_set_drive_strength(ADS_PIN, GPIO_DRIVE_STRENGTH_12MA);
    gpio_set_slew_rate(ADS_PIN, GPIO_SLEW_RATE_FAST);

    uint iow_offset = pio_add_program(pio0, &iow_program);
    pio_sm_claim(pio0, IOW_PIO_SM);
    DBG_PRINTF("iow sm: %u\n", IOW_PIO_SM);

    uint ior_offset = pio_add_program(pio0, &ior_program);
    pio_sm_claim(pio0, IOR_PIO_SM);
    DBG_PRINTF("ior sm: %u\n", IOR_PIO_SM);

    iow_program_init(pio0, IOW_PIO_SM, iow_offset, iow_clkdiv);
    ior_program_init(pio0, IOR_PIO_SM, ior_offset);

#ifdef USE_IRQ
    DBG_PUTS("Enabling IRQ on ISA IOR/IOW events");
    irq_set_enabled(PIO0_IRQ_1, false);
    pio_set_irq1_source_enabled(pio0, pio_get_rx_fifo_not_empty_interrupt_source(IOW_PIO_SM), true);
    pio_set_irq1_source_enabled(pio0, pio_get_rx_fifo_not_empty_interrupt_source(IOR_PIO_SM), true);
    irq_set_priority(PIO0_IRQ_1, PICO_HIGHEST_IRQ_PRIORITY);
    irq_set_exclusive_handler(PIO0_IRQ_1, io_isr);
    irq_set_enabled(PIO0_IRQ_1, true);
#endif

    gpio_xor_mask(LED_PIN);

#if AUDIO_CALLBACK_CORE0
    pwm_c = pwm_get_default_config();
    pwm_config_set_wrap(&pwm_c, clocks_per_sample_minus_one);
    pwm_init(pwm_slice_num, &pwm_c, false);
    pwm_set_irq_enabled(pwm_slice_num, true);
    irq_set_exclusive_handler(PWM_IRQ_WRAP, audio_sample_handler);
    irq_set_priority(PWM_IRQ_WRAP, PICO_LOWEST_IRQ_PRIORITY);
    irq_set_enabled(PWM_IRQ_WRAP, true);
    pwm_set_enabled(pwm_slice_num, true);
#endif

    processSettings();

    for (;;) {
#ifndef USE_IRQ
        if (iow_has_data()) {
            handle_iow();
        }

        if (ior_has_data()) {
            handle_ior();
        }
#endif
#ifdef POLLING_DMA
        process_dma();
#endif
    }
}

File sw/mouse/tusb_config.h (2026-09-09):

/* 
 * The MIT License (MIT)
 *
 * Copyright (c) 2019 Ha Thach (tinyusb.org)
 *
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
 */

#ifndef _TUSB_CONFIG_H_
#define _TUSB_CONFIG_H_

#ifdef __cplusplus
 extern "C" {
#endif

//--------------------------------------------------------------------+
// Board Specific Configuration
//--------------------------------------------------------------------+
#define CFG_TUSB_MCU OPT_MCU_RP2040

#if CFG_TUSB_MCU == OPT_MCU_RP2040
// change to 1 if using pico-pio-usb as host controller for raspberry rp2040
#define CFG_TUH_RPI_PIO_USB   0
#define BOARD_TUH_RHPORT      CFG_TUH_RPI_PIO_USB
#endif

// RHPort number used for host can be defined by board.mk, default to port 0
#ifndef BOARD_TUH_RHPORT
#define BOARD_TUH_RHPORT      0
#endif

// RHPort max operational speed can defined by board.mk
#ifndef BOARD_TUH_MAX_SPEED
#define BOARD_TUH_MAX_SPEED   OPT_MODE_DEFAULT_SPEED
#endif

//--------------------------------------------------------------------
// COMMON CONFIGURATION
//--------------------------------------------------------------------

// defined by compiler flags for flexibility
#ifndef CFG_TUSB_MCU
#error CFG_TUSB_MCU must be defined
#endif

#ifndef CFG_TUSB_OS
#define CFG_TUSB_OS           OPT_OS_NONE
#endif

#ifndef CFG_TUSB_DEBUG
#define CFG_TUSB_DEBUG        0
#endif

// Enable Host stack
#define CFG_TUH_ENABLED       1

// Default is max speed that hardware controller could support with on-chip PHY
#define CFG_TUH_MAX_SPEED     BOARD_TUH_MAX_SPEED

/* USB DMA on some MCUs can only access a specific SRAM region with restriction on alignment.
 * Tinyusb use follows macros to declare transferring memory so that they can be put
 * into those specific section.
 * e.g
 * - CFG_TUSB_MEM SECTION : __attribute__ (( section(".usb_ram") ))
 * - CFG_TUSB_MEM_ALIGN   : __attribute__ ((aligned(4)))
 */
#ifndef CFG_TUSB_MEM_SECTION
#define CFG_TUSB_MEM_SECTION
#endif

#ifndef CFG_TUSB_MEM_ALIGN
#define CFG_TUSB_MEM_ALIGN          __attribute__ ((aligned(4)))
#endif

//--------------------------------------------------------------------
// CONFIGURATION
//--------------------------------------------------------------------

// Size of buffer to hold descriptors and other data used for enumeration
#define CFG_TUH_ENUMERATION_BUFSIZE 256

#define CFG_TUH_HUB                 1 // number of supported hubs
#define CFG_TUH_CDC                 0
#define CFG_TUH_HID                 4 // typical keyboard + mouse device can have 3-4 HID interfaces
#define CFG_TUH_MSC                 1
#define CFG_TUH_VENDOR              0

// max device support (excluding hub device)
#define CFG_TUH_DEVICE_MAX          (CFG_TUH_HUB ? 4 : 1) // hub typically has 4 ports

//------------- HID -------------//
#define CFG_TUH_HID_EPIN_BUFSIZE    64
#define CFG_TUH_HID_EPOUT_BUFSIZE   64

//------------- CDC -------------//

// Set Line Control state on enumeration/mounted:
// DTR ( bit 0), RTS (bit 1)
#define CFG_TUH_CDC_LINE_CONTROL_ON_ENUM    0x03

// Set Line Coding on enumeration/mounted, value for cdc_line_coding_t
// bit rate = 115200, 1 stop bit, no parity, 8 bit data width
#define CFG_TUH_CDC_LINE_CODING_ON_ENUM   { 115200, CDC_LINE_CONDING_STOP_BITS_1, CDC_LINE_CODING_PARITY_NONE, 8 }


#ifdef __cplusplus
 }
#endif

#endif /* _TUSB_CONFIG_H_ */

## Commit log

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2026-09-09 PGDFS: EDF5 file server on FatFs with a host test harness
    The request processor is the ethersrv-linux code (Mateusz Viste, MIT; LFN
    changes by Eric Voirin; FatFs adaptation from PicoMEM by Freddy Vetele)
    with the PGDFS 4-byte frame header and a single FatFs volume:
    - sw/dfs/dfs_server.c: dispatch for RMDIR, MKDIR, CHDIR, CLOSE, READ,
    WRITE, LOCK/UNLOCK, DISKSPACE, GETATTR/SETATTR, RENAME, DELETE with
    wildcards, OPEN/CREATE/SPOPNFIL with INT 21h/6Ch action codes,
    FINDFIRST/FINDNEXT, SEEKFROMEND, SETFILETIMESTAMP and an ECHO
    subfunction for transport tests. DOS error codes as MS-DOS expects.
    - sw/dfs/dfs_fs.c: 8-entry open-file table, LRU directory-id table with a
    cached DIR so FIND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
2026-09-09 PGDFS: DOS redirector TSR, PGDFSTST diagnostic tool, pgusinit status, CI
    - pgdfs/PGDFS.C: derived from the EtherDFS client (Mateusz Viste, MIT).
    The INT 2Fh/11h redirector logic, SDA/CDS handling and TSR layout are
    unchanged; the packet-driver transport is replaced by pgdfs/XPORT.C,
    which streams frames through port 1D3h and polls CMD_DFSSTAT. One
    4 KB frame buffer, rep insb/outsb on 186+ and IN/OUT loops on 8088.
    `PGDFS E:` maps the drive; /U unload, /Q quiet, /R read-only, /T push
    the DOS clock to the card. About 10 KB resident.
    - pgdfs/PGDFSTST.C: /INFO, /ECHO throughput, /DIR, /TYPE, /GET, /PUT,
    /TIME over the same transport, for protocol conformance on hardware.
    - pgusinit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
2026-09-09 PGDFS: fixes from the branch review
    - transport: an abort while core 1 is busy no longer hands the frame
    buffer back early. The status stays BUSY until core 1 finishes and
    moves it to ABORTED itself, so the driver's next request waits instead
    of streaming into a buffer still being written (a timed-out request
    could corrupt the following one). The DOS clock from CMD_DFSTIME is
    applied from dfs_tasks() on core 1, where the FatFs clock state lives.
    - usb_msc: TinyUSB mount/unmount callbacks only record events; the FatFs
    mount/unmount and the consumer hooks run from msc_app_task() in every
    core 1 loop, never inside a FatFs call. A transfer whose device goes
    away fails immediately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
    [gusplay.cpp]
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2026-09-12 PGDFS: configurable word-wide data port, long-name lookup, code page option
    Follows review feedback from the PicoGUS community:
    - The data port is no longer hardcoded. It is a two-port window at an even
    base held in the card's settings (CMD_DFSPORT, default 1D4h, pgusinit
    /dfsport, saved with /save; 0 disables PGDFS). Bases outside 100h-3FEh or
    overlapping the control ports are rejected; pgusinit warns when the
    window falls inside another emulated device's port range and reminds the
    user to reload a resident PGDFS.EXE after a change. The driver reads the
    port from the card at install.
    - Both ports of the window feed the same byte stream, so the driver moves
    frames with rep ins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
2026-09-15 PGDFS: disk diagnostics, write/read fault errors, untrusted FSInfo count
    First hardware run: writes answered "drive not ready" (15h) and MD answered
    "access denied" while every read worked. Nothing in the firmware had written
    to a USB drive before this branch, so the card now tells the DOS side what
    its disk path saw instead of hiding everything behind 15h.
    - New DIAG request (F2h): a 60-byte record with the USB read/write counters,
    refused, failed, timed-out and stale transfers, the last SCSI status and
    residue, the last disk write (LBA, sectors, microseconds), the last failing
    FatFs call and the free-cluster count FatFs works with. DFSDIAG /INFO
    prints it and DFSDIAG prints it aft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
2026-09-25 PGBOOT: fixes from a hardware-risk review
    Protocol: BDINFO returns an image token (offset 20) that BDREAD/BDWRITE
    must echo (10-byte request header). It hashes a per-card-boot nonce, the
    unit, the explicit open count, the path, start cluster and size, so a
    running system can never be handed a different image: a floppy mismatch
    answers 06h (media changed), a hard disk mismatch 80h. New state 5: image
    too fragmented.
    Card:
    - After a card boot no image opens until the ROM's BDINFO with OPEN (or a
    floppy name commit); a USB replug reopens the units that were open.
    Before the drive mounts, configured units read state 4 so the ROM's wait
    loop can tell "not mounted" from "not opened yet".
    -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
    [main.c, pgboot.asm]
2026-09-28 Add RP2350 (Pico 2 / Pico 2 W) support
    Build with -DPICO_PLATFORM=rp2350 (board defaults to pico2_fast, or
    pico2w_fast for NE2K). RP2040 builds are unchanged: every RP2040 image
    (multifw bundle, each mode, bootloader, NE2K) is byte-identical to before.
    RP2350 differences handled:
    - GPIO pads reset with input disabled and isolation latched, so the ISA
    bus pins that are only sampled by PIO (AD0-9, IOR, IOW, DACK, TC) are
    explicitly enabled (system/platform.h, main, ISA DMA init).
    - Reset reason comes from POWMAN.CHIP_RESET, the XIP cache has separate
    secure/non-secure enables.
    - Overclock: 1.30V core voltage, and the QMI flash clock is slowed to
    clk_sys/6 before going to 370MHz. The b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
    [isa_dma.c, overclock.h, picogus.cpp]
2026-09-28 Make in-firmware flashing safe with RP2040 and RP2350 images around
    pgusinit /flash streams a UF2 to the card, which erased flash on the
    first block and then wrote blocks back to back from offset 0 without
    looking at them. With RP2040 and RP2350 builds side by side, flashing the
    wrong one would erase the card's firmware and leave it unbootable.
    Check each block before using it, and the first block before anything
    is erased:
    - the UF2 family ID must match this chip (RP2040, or RP2350 Arm-S;
    RP2040 still accepts UF2s without a family ID)
    - 256 byte payloads addressed contiguously from the start of flash, which
    is how the blocks are programmed (this also refuses the per-mode
    -multifw UF2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
2026-09-28 hw-tht: WIP through-hole PicoGUS v1.2 variant with Waveblaster header
    Work in progress: schematic, BOM, README, hybrid DIP/TSSOP footprints and
    placed (not yet routed) PCB for a through-hole version of PicoGUS v1.2.
    - KiCad 10 project copied from hw/ (v1.2) with THT parts where they exist;
    the CB3T3257 muxes, PSRAM and PCM510x DAC stay SMD.
    - DIP-14/DIP-20 footprints also take the TSSOP version (inside or beside it).
    - New Waveblaster header with 3.3 V-safe MIDI and /RESET, WT volume (dual
    log pot) and a NE5532 inverting mixer powered from ISA +/-12 V.
    - BOM with DigiKey and LCSC part numbers and stock as of 2026-09-28.
    Claude-Ses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
    [BOM-THT.csv, PicoGUS-THT.kicad_pcb, PicoGUS-THT.kicad_sch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]
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2026-09-28 hw-tht: restore net classes and design rules in the project file
    Building on the review board without its project file saved KiCad's
    default rules over ours. Put back the pwr/GND net classes, 0.2 mm
    clearance and the DRC severities from the previous commit.
    Claude-Session: https://claude.ai/code/session_011utN3x8yYUNDvkpGCEq5yD
    [PicoGUS-THT.kicad_pcb]
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2026-09-28 hw-tht: 5 mm disc/0805 hybrid capacitors, labels inside or beside bodies
    - New C_Disc_D5.0mm_W2.5mm_P5.00mm_0805_Hybrid footprint for all ceramic
    caps: 5.0/5.08 mm radial part OR an 0805 between the holes. Replaces
    the 2.5/5.0 mm dual-pitch footprint.
    - BOM: every ceramic cap line is now 5 mm pitch at both distributors
    (2.2 nF LCSC Dersonic C22391154, 100 pF DigiKey Vishay
    K101J15C0GF5TH5) and lists an in-stock 0805 alternative.
    - Silkscreen labels: FB1/FB2 inside the body like the resistors;
    capacitor labels just outside the body, above/left, else at a free end.
    Claude-Session: https://claude.ai/code/session_011utN3x8yYUNDvk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
    [BOM-THT.csv, PicoGUS-THT.kicad_pcb, PicoGUS-THT.kicad_sch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]
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2026-09-28 hw-tht: remove the J2 ISA debug header, move U3/U4 to the gold fingers
    - J2 (2x31 ISA probe header, never fitted, carried over from v1.2) is
    removed from schematic, board and BOM. Its 62 pads formed a wall just
    above the fingers that every ISA signal had to cross, which kept the
    autorouter stuck. ISA pins that only went to J2 get no-connect flags.
    - U3/U4 (CB3T3257 bus switches) sit in the freed strip right above the
    data-line fingers, with C3/C5 2.5 mm from their supply pins; their 16
    ISA-side lines are now short, only the 8 AD lines run to the Pico.
    - Power tracks: +5V/+3V3/VSYS 0.4 mm (was 0.5 mm, barely fit between
    DIP pins); +/-12V use normal 0.25 mm tracks (a few mA).
    Co-A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
    [BOM-THT.csv, PicoGUS-THT.kicad_pcb, PicoGUS-THT.kicad_sch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]
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2026-09-28 hw-tht: remove the hybrid footprint library, update README
    With through-hole parts only, the board-specific hybrid footprints, their
    generator and the hybrid picture are no longer used. README describes
    the THT-only design, DigiKey as the source for the DIP logic ICs, the
    axial ferrite beads, the removed J2 header, 0.4 mm power tracks, and
    RV1 between the MIDI and line-out jacks.
    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
2026-09-28 hw-tht: route the through-hole board, silkscreen pass
    - Fully routed (Freerouting 1.9.0 with GND routed as a net, pours filled
    afterwards): 0 DRC errors, every net connected. Hand pre-routes for
    the DAC: GND pins 16/19 to a via under the chip, VNEG to C17.
    - GND pour on both layers with stitching vias.
    - Silkscreen: DIP labels inside the outlines, colliding labels moved,
    DAC / MIXER / WT VOL / WAVEBLASTER legends, one-arrow REAR labels
    centred on the H2 screw hole. Back: info text in the Pico area; credit
    list, pig, Colorado flag and JLC placeholder removed.
    Remaining DRC warnings are cosmetic: small label text, a few pads with
    fewer thermal spokes, silk near the board edge.
    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
    [PicoGUS-THT.kicad_pcb]
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2026-09-29 hw-tht: cleaner audio supplies, bipolar WT coupling caps, circuit-block groups
    - DAC AVDD (U9 pin 8) gets its own rail behind ferrite bead FB3, with C13/C15
    at the pin; DVDD/CPVDD stay on the Pico 3V3.
    - NE5532 +/-12 V from ISA through R23/R24 (10R) + C32/C33 (47uF) RC filters,
    C28/C29 0.1uF stay at the op-amp pins.
    - C22/C23 WT coupling caps are now 10uF bipolar (Panasonic ECE-A1HN100U):
    the DC across them depends on the daughterboard.
    - Every chip and its decoupling caps/resistors form a KiCad group.
    - DAC pre-routes reworked (VNEG via B.Cu, XSMT via); RUN RC moved out of the
    Pico fan-in. Fully routed, 0 DRC errors, 0 unconnected.
    - BOM: new lines for R23/R24, FB3, C32/C33; README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
    [BOM-THT.csv, PicoGUS-THT.kicad_pcb, PicoGUS-THT.kicad_sch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]
2026-09-29 hw-tht: PWR_FLAG on Pico VBUS, ERC now 0 errors
    VBUS is fed from the Pico's USB socket or through the USBPWR jumper J7,
    so nothing on the schematic drives it (same ERC error on v1.2).
    Schematic only, the PCB is unchanged.
    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
    [PicoGUS-THT.kicad_sch, audio.kicad_sch, wavetable.kicad_sch]
2026-09-29 hw-smd: PicoGUS v1.3.0 SMD with Waveblaster header and mixer
    SMD version of the v1.3.0 changes made on the THT board:
    - v1.2 logic unchanged; Waveblaster header J9, U12 74LVC2G06 for the
    daughterboard /RESET and MIDI (open drain, 10k to 3V3)
    - NE5532 WT/PCM mixer with RV1 WT volume, bipolar coupling caps,
    C0G + 0.1% thin film in the signal path
    - DAC AVDD behind ferrite bead FB3; op-amp +/-12 V RC filtered
    - THT board layout (taller card, rotated Pico, DAC facing the mixer),
    KiCad groups per circuit block; fully routed, 0 DRC errors
    - BOM-SMD.csv with digikey.no links, stock and NOK prices; out-of-stock
    v1.2 DigiKey lines replaced
    - GY-PCM5102 module option and J2 debug header remove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
    [BOM-SMD.csv, BOM-THT.csv, PicoGUS-SMD.kicad_pcb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]
2026-09-29 hw-tht: adopt the new hand-made component placement; label clean-up
    - THT board rebuilt on the uploaded layout: every part position,
    rotation and reference label kept as placed (R17 moved 0.5 mm down to
    clear C7's courtyard), texts/logo kept; fully re-routed, GND stitched,
    0 DRC errors, 0 unconnected, schematic parity OK. No schematic change
    needed: every cap/resistor sits at the pins it serves.
    - Pico pin-name / SWD silkscreen texts removed (THT and SMD).
    - WAVEBLASTER, DAC, MIXER and WT VOL labels in Futura bold; WT VOL now
    sits beside RV1 exactly as MIDI OUT / AUDIO OUT sit beside their jacks.
    - hw-smd: same label treatment; C23 moved 1.8 mm left to clear WT VOL,
    board re-rout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
    [PicoGUS-SMD.kicad_pcb, PicoGUS-THT.kicad_pcb]
2026-09-29 JLCPCB export flow; hw-smd re-synced to the new THT placement
    - hw-common/tools/jlcpcb.sh: DRC gate (incl. schematic parity), Gerbers
    (Protel ext., no X2) + Excellon drill zipped for upload, JLC assembly
    BOM + CPL for SMD parts.
    - .github/workflows/hardware.yml: runs it for hw-tht and hw-smd in the
    kicad/kicad:10.0 container and uploads the files as artifacts.
    - hw-smd: parts moved to the new hand-made THT layout (SMD part at the
    THT part's centre), decoupling caps re-seated at their own chips,
    C22/C23 re-placed next to RV1; U10 GND pre-routed to a via; fully
    re-routed, 0 DRC errors, 0 unconnected, schematic parity OK.
    - READMEs: JLCPCB ordering section.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
    [PicoGUS-SMD.kicad_pcb]
2026-09-29 Experimental 2nd IRQ (J10/J11), DMA label fix, labels grouped
    - U2's spare channel (2A2 pin 13 -> 2Y2 pin 7, same drive and ~BUSOE as the
    IRQ output) now drives an optional second IRQ: J10 (next to the PSRAM,
    short stub on the fast SPI line) links GPIO3/SPI_TX to 2A2, R25 (10k)
    holds it low when open; J11 (next to J1) links 2Y2 to ISA IRQ3.
    GPIO3 is the PSRAM SPI_TX (all 26 Pico GPIOs are used), so this is for
    firmware that leaves the PSRAM idle. THT and SMD, ERC 0 errors.
    - DMA heading moved back beside IRQ above J1.
    - Silkscreen labels are members of their circuit-block KiCad groups
    (DAC, MIXER, AUDIO OUT, WT VOL, WAVEBLASTER, MIDI OUT, TX/USBPWR,
    IRQ/DMA + jumper numbers + d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
    [BOM-SMD.csv, BOM-THT.csv, PicoGUS-SMD.kicad_pcb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]
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2026-09-29 hw-tht: J11 vertical with NE2000/IRQ3 label, H1/H2 silk removed; DigiKey upload CSVs
    - J11 stands vertically on J1's pin rows; heading "NE2000 / IRQ3" centred
    above it (replaces "2ND IRQ" + side label); the J11 reference sits beside it.
    - H1/H2 reference silkscreen hidden.
    - Re-routed (VSYS to J7 hand-routed between the J6 pads on B.Cu):
    0 DRC errors, 0 unconnected, schematic parity OK.
    - BOM-*-digikey-upload.csv: quantity, DigiKey PN, MPN and the reference
    designators as Customer Reference (compact ranges, <= 48 chars) so each
    bag is labelled with its board positions.
    Claude-Session: https://claude.ai/code/session_011utN3x8yYU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
    [BOM-SMD-digikey-upload.csv, BOM-THT-digikey-upload-optional.csv, BOM-THT-digikey-upload.csv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]
2026-09-29 hw-smd: J11 vertical with NE2000/IRQ3 label, H1/H2 silk removed; re-routed (0 DRC errors, 0 unconnected)
    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
    [PicoGUS-SMD.kicad_pcb]
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2026-09-29 J5/J8/RV1 labels inside their outlines; 10-board DigiKey upload CSVs
    - J5 (its label was off the board edge), J8 and RV1: reference labels moved inside
    their own silkscreen outlines, so RV1 no longer reads as the MIDI jack's label.
    - BOM-*-digikey-upload-10x.csv: quantities for 10 boards (header strips: 11).
    - Both boards: 0 DRC errors, 0 unconnected, schematic parity OK.
    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
    [BOM-SMD-digikey-upload-10x.csv, BOM-THT-digikey-upload-10x.csv, BOM-THT-digikey-upload-optional-10x.csv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]
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2026-09-29 hw-tht: R7/R8 + C19/C20 belong to the DAC area; module feeds AUDIO_L/R
    The GY-PCM5102 module already has the PCM510x reference 470R/2.2nF output
    filter, so J10's ROUT/LROUT now join AUDIO_L/R after R7/R8 + C19/C20 instead of
    U9's outputs. The whole filter is left out with the DAC when the module is used
    (no double filter, no extra 470R in front of the mixer).
    - Dashed DAC outline now encloses U9, C12-C20, FB3, R7, R8 (steps under J10's
    pin row); "J10: GY-PCM5102" label moved inside the module outline.
    - Schematic note, BOM notes and README table updated.
    - Re-routed the four audio nets: 0 DRC errors, 0 unconnected, parity OK; ERC 0.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
    [BOM-THT.csv, PicoGUS-THT.kicad_pcb, audio.kicad_sch]
2026-09-29 hw-tht: adopt the new DAC/GY-PCM5102 placement; re-routed; artwork moved
    - Placement from the updated board: the DAC block (U9, C12-C20, FB3, R7, R8)
    moved 3 mm right and J10 now lies almost flat over it, so the module's dashed
    outline covers exactly the parts to leave out; heading "DAC -OR- GY-PCM5102".
    R3/R4 turned vertical next to C1/FB2. C32 label moved off R3's pad.
    - Tracks at the moved parts ripped up and re-routed (autorouter + grid router
    for the stragglers), dangling stubs removed, U9 pin 16 stitched to GND.
    - Back artwork regenerated at its new spot above the ISA fingers (pad cut-outs
    recomputed there), dedication where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
    [BOM-THT-digikey-upload-optional-10x.csv, BOM-THT-digikey-upload-optional.csv, BOM-THT.csv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]
2026-09-29 WIP hw-smd: GY-PCM5102 module option (J10) - routing not finished
    - Schematic: J10 on the DAC sheet as on the THT board (outputs to AUDIO_L/R,
    leave out U9, C12-C20, FB3, R7, R8 when the module is fitted); ERC 0 errors.
    - Board: J10 placed where it is on the THT board, colliding tracks removed.
    0 DRC errors but 17 connections still unrouted - do not order from this commit.
    - BOM notes and README DAC-option section.
    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
    [PicoGUS-SMD.kicad_pcb, PicoGUS-SMD.kicad_sch, audio.kicad_sch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]
2026-09-29 hw-tht: new back-side artwork (game heroes over the PicoGUS logo)
    - Back silkscreen artwork replaced with hw-common/art/picogus-artwork.svg,
    76 x 27 mm just above the ISA fingers, cut out 0.3 mm around pads/holes;
    the dedication stays where it was, now above the artwork.
    - 0 DRC errors, 0 unconnected, schematic parity OK.
    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
    [PicoGUS-THT.kicad_pcb]
2026-09-29 hw-tht: dedication text moved to (139.5, 60.5) on the back
    0 DRC errors, 0 unconnected; JLCPCB gerbers regenerated.
    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
    [PicoGUS-THT.kicad_pcb]
2026-09-29 hw-smd: J10 module option routed; DAC heading; new back artwork
    - All connections routed after adding J10 (autorouter + grid router for the
    stragglers; some long staircase tracks, e.g. -12V and UART_TX, are left for
    the planned re-arrangement). Dangling stubs/vias removed.
    - "DAC -OR- GY-PCM5102" heading; J10 outline covers the DAC parts.
    - Back: new PicoGUS artwork at the same spot as on the THT board; dedication
    still at its previous position (THT has it at 139.5, 60.5).
    - Not yet regenerated: BOM-SMD.csv / DigiKey CSVs, README art paragraph,
    schematic PDF, JLCPCB files.
    Cla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
    [PicoGUS-SMD.kicad_pcb]
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2026-09-29 hw-smd: adopt the new component placement; full re-route; new back artwork
    - Placement from the updated board (62 of 82 parts moved, all circuit groups).
    Sanity check: no courtyard overlaps; J10 still covers exactly the DAC parts
    (U9, C12-C20, FB3, R7, R8); C32 (7.7 mm) now under the Waveblaster area,
    ~3 mm below a daughterboard; J9 0.67 mm left of its THT position.
    - Full re-route from scratch (autorouter, then grid router for the last
    signals: RA8/RA9, ~IOR, DACK, AD7, GND stitching of C9, U9 pins 3/19 and the
    J3 GND finger). 0 DRC errors, 0 unconnected, schematic parity OK.
    - Labels on pads / overlapping moved to free spots (angle kept): C2, C10, C14,
    C15, C26, C27, C32, C33,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
    [BOM-SMD.csv, PicoGUS-SMD.kicad_pcb]
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2026-10-05 hw-ne2k: routed board (DRC 0/0), silkscreen and artwork, README
    - Freerouting + manual fix-ups: IRQ grid-routed, GND pour stitched (57
    vias) and U17 GND tied in. KiCad 10 DRC: 0 violations, 0 unconnected,
    schematic parity OK (warnings: 2 silk-to-edge at the USB-A, 3 thermals).
    - No copper under the Pico W antenna or between its end and the bracket.
    - Front silk: title, IRQ numbers, ROM WE, TX/GND, USB, WiFi antenna, REAR.
    Back: PicoGUS artwork, dedication, copyright/licence (CERN-OHL-P v2).
    - README: status, silkscreen, JLCPCB notes (no LCSC numbers yet).
    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
    [PicoGUS-NE2K.kicad_pcb]
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2026-10-05 hw-ne2k: placement proposal (unrouted): bus switches + ROM buffer at the data fingers
    U3/U4 (CB3T3257) and U15 (ROM data buffer) move next to D0-D7 to keep the
    ISA data lines short; U2 moves left next to J1 / A8-A9, U5 + C7 and R5/R6
    shift left of the new row. Everything else as in the user's layout.
    Routing stripped for review (routed version: 28f17e1).
    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
    [PicoGUS-NE2K.kicad_pcb]
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2026-10-09 Mixer docs: schematic note, DAC load and wording for the +6 dB WT gain
    Review fixes for e33fce5:
    - The wavetable-sheet note (both boards, and the schematic PDFs) still said
    "unity gain (inverting, 10k/10k)". It now gives PCM 20k/20k (~unity) and
    WT x2 (+6 dB), wrapped so it stays clear of the THT spare U7 gates.
    - THT README: the PCM510x now sees ~20.5k (R7 + R10), not ~10.5k.
    - Wording: the 47p corner is ~170 kHz (was ~160 kHz with 10k/100p), PCM gain
    moves -0.4 -> -0.2 dB ("essentially unchanged"), and keeping 100p costs
    ~0.2 dB more at 20 kHz. Same wording in the BOM notes.
    Claude-Session: https://claude.ai/code/session_011u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
    [BOM-SMD.csv, BOM-THT.csv, wavetable.kicad_sch]
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2026-10-18 sorting-sheets skill: large-square A5 fold is the default layout
    The skill picked the compact 5 x 2 A5 layout for "fold to A5" requests and
    flat A4 otherwise, so its output missed the final A5 adjustment: squares
    about 50 % larger (3 x 2 per A5 half, ~63 x 61 mm) with U1 and its pin
    strip in separate squares, chosen because jacks, pots, DIP ICs, the Pico
    and 1x20 strips did not fit the smaller squares.
    - render.py / check_sheets.py: layout a5fold is now the large-square layout
    and the default; the 5 x 2 version is a5fold-compact; a4 unchanged;
    a5fold-large is accepted as the old name.
    - SKILL.md: use a5fold unless the user asks for compact squares or flat A4,
    and say why.
    Output chec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
2026-10-18 THT rev B: review fixes, C34 220uF, schematic PDF
    Schematic
    - C34 (USB VBUS bulk) 220 uF low-impedance Rubycon 16ZLH220MEFC6.3X11
    (USB 2.0 asks for >= 120 uF per host port)
    - own UUID namespace for the rev B items (the USB sheet had reused UUIDs of
    v1.3.0 items, which mixed up ERC markers)
    - TP1-TP3 pin names empty ("") in the embedded Pico_USB copy (KiCad 10 drew
    "~" literally)
    - R25/R26 DigiKey/LCSC fields, U3/U4 adapter note (PA0034C first, BOB-13994
    has 0.635 mm pads), U12 in the title block's SMD list, USB sheet note
    reworded, USB-C always-on VBUS warning
    - schematic PDF re-exported (4 pages)
    Board
    - U1: the library footprint's Pico pin-name/SWD silkscreen texts removed
    aga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
2026-10-18 THT rev B: take 2 placement fixes from the review (bracket window, J11 flange, C32)
    - RV1/J8 swapped: RV1's bushing was above the PC slot opening
    - J11 moved 1.36 mm in so its flange stays behind the bracket; C34/F1/R4 nudged
    - C32 out from under the daughterboard; R17/U5 and J6/J7 overlaps fixed
    - R19/R20 turned (summing nodes at U11), C8 next to U8, R2 horizontal, C1/C2
    - README: bracket drilling table, layout status; socket BOM: U3/U4 under the daughterboard
    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

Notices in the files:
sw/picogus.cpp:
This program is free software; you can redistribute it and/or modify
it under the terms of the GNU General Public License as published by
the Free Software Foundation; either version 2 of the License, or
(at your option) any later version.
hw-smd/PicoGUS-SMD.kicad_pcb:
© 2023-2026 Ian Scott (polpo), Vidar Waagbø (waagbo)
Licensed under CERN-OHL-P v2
